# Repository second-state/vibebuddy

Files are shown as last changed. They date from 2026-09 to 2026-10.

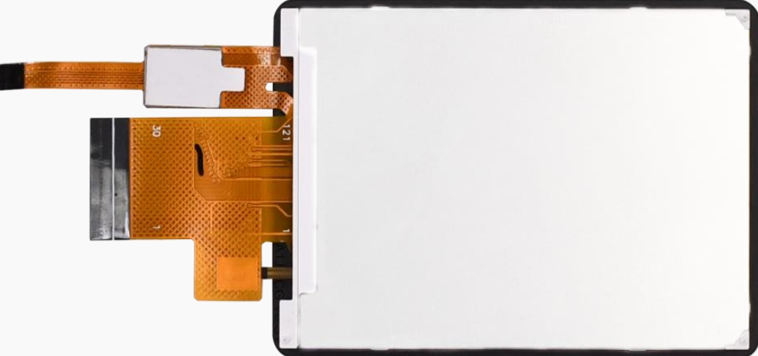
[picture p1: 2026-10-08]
docs/hardware-reference/atk-box3/n1.png

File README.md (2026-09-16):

Vibe Buddy (formerly VibeBuddy) is a physical status terminal for local AI agents and long-running tasks.

# Vibe Buddy

Vibe Buddy（原名 VibeBuddy，仓库、`vibebuddyd` 与 Vibe Buddy Protocol 沿用旧名）是运行在 ESP32-S3 盒子里的实体 Agent 宠物。原创角色“氛围小助手”用动画、任务卡片和短语音呈现本地 AI Agent 与长任务的状态；Codex 是第一个适配器，但设备协议不绑定某个客户端。

## 当前状态

**Stage 4 — 氛围小助手显示与语音已通过实机验收，Codex、Claude Code 与 GitHub Actions 均已接入。** 它们的事件都经 `vibebuddyd` 和 USB Serial/JTAG 到达盒子，并共享同一个任务卡栈。氛围小助手支持空闲、工作中、需要确认、完成、失败和失联；最多显示 3 张任务卡，最新在最上，每张卡显示它在当前状态里待了多久；需要确认、完成和失败各播报一次短语音，工作中保持安静；空闲时轮播当日战绩并偶尔做个小动作。

氛围小助手有三个模式。**值班**是默认：盯着 Agent，有事叫你。**番茄钟**给你计时（专注 25 分钟、休息 5 分钟）：K0 开始、暂停、继续，长按放弃；K1 在值班与番茄钟之间切换；K2 照旧打开来源，长按静音；阶段结束响铃并播报，下一阶段等你按 K0 再开始；今天完成了几次、专注了多久记在面板上，按日清零，重启不丢。**休闲**是值班空闲够久之后它自己去玩：五分钟后开始演小剧目（巡逻、踢球、看书、数星星、躲猫猫、被自己吓醒、梦话），半小时后困了转暗睡觉，夜里睡够 90 分钟关背光；Agent 一有动静或按任何键立刻回来值班。番茄钟与休闲的状态都在固件里，不依赖 Mac 端。设计见 [`docs/pomodoro.md`](docs/pomodoro.md) 与 [`docs/leisure.md`](docs/leisure.md)。

## 目标架构

```text
Local Programs / Agents / Codex / Scripts
                |
                | HTTP / Unix Socket
                v
             vibebuddyd
                |
                | Transport abstraction
                v
          USB Serial / USB CDC
                |
                v
           ESP32S3-BOX
                |
      LCD / Speaker / Buttons
```

- `vibebuddyd`：本机守护进程，负责事件接入、设备连接、重连、路由和状态。
- `beacon`：只调用 `vibebuddyd` 的命令行客户端，不直接占用串口。
- `vibebuddy-fw`：ESP32-S3 固件，仅负责设备 I/O 和 Vibe Buddy Protocol 消息处理。
- Vibe Buddy Protocol：与 transport 解耦的可扩展 NDJSON 协议。

更完整的边界与决定见 [`docs/architecture.md`](docs/architecture.md)，领域词汇见 [`CONTEXT.md`](CONTEXT.md)，氛围小助手设计见 [`docs/pet.md`](docs/pet.md)，番茄钟见 [`docs/pomodoro.md`](docs/pomodoro.md)，休闲模式见 [`docs/leisure.md`](docs/leisure.md)，Codex 接入见 [`docs/codex-adapter.md`](docs/codex-adapter.md)，CI 接入见 [`docs/ci.md`](docs/ci.md)，协议决定见 [`docs/protocol.md`](docs/protocol.md)，阶段门禁见 [`docs/roadmap.md`](docs/roadmap.md)，外部项目的借鉴边界见 [`docs/references.md`](docs/references.md)。

## Stage 0 USB 探测

在开发板未连接和已连接两种状态下分别运行：

```bash
./tools/detect-device.sh baseline
./tools/detect-device.sh connected
diff -ru .probe/baseline .probe/connected
```

探测结果可能包含本机 USB 设备标识。`.probe/` 默认不纳入 Git。

## Stage 1 固件

连接 ATK-DNESP32S3-BOX V1.1 的 `USB-SLAVE` 口后执行：

```bash
./tools/flash.sh /dev/cu.usbmodem8401
uv run --with pyserial python tools/serial-hello.py /dev/cu.usbmodem8401
```

烧录前可以在 Mac 上先验证固件里不依赖硬件的部分：`./tools/test-pomodoro.sh` 跑番茄钟状态机的测试，`./tools/preview-display.sh` 把固件的绘制代码渲染成 PNG 看版式。

固件使用 [`firmware/partitions.csv`](firmware/partitions.csv) 的自定义分区表（app 分区 4 MB），因为语音资产已经装不进默认的 1 MB。这个选择写在 `sdkconfig.defaults` 里，但 ESP-IDF 只在生成 `sdkconfig` 时读取 defaults：2026-09-15 之前就存在 `firmware/sdkconfig` 的检出目录要先删掉它再构建，否则仍按旧分区表检查大小并失败。

设备若只接着 BOX 的 `UART` 口（CH343 桥，`/dev/cu.usbmodem5909…`），不要用 `flash.sh`：那条路在 esptool 默认参数下会把 flash 擦掉后写不进去。用 [`tools/flash-bridge.sh`](tools/flash-bridge.sh)，它以 `--no-stub` 加 256 字节写块烧录，先单独写分区表试路，再写 app：

```bash
launchctl bootout gui/$(id -u)/com.vibebuddy.vibebuddyd
./tools/flash-bridge.sh /dev/cu.usbmodem59090668961 partition
./tools/flash-bridge.sh /dev/cu.usbmodem59090668961 app
launchctl bootstrap gui/$(id -u) ~/Library/LaunchAgents/com.vibebuddy.vibebuddyd.plist
```

`flash.sh` 会覆盖当前固件。2026-09-14 的原厂 `xiaozhi` 1.9.4 整片备份保存在本机 `.probe/factory/`，权限为 `600`，不会提交到 Git。

## Vibe Buddy App

Mac 端的图形界面是一个菜单栏 App，它把 `vibebuddyd` 与 `vibebuddy-hook` 带在身上并看管 daemon，取代了 LaunchAgent。装包：

```bash
idf.py -C firmware build          # Release 装包要附带固件三件套；--debug 可以不带
app/scripts/build-app.sh          # 出 app/build/Vibe Buddy.app
open "app/build/Vibe Buddy.app"
```

首次启动走引导：找盒子（眨眼确认）、接入 Codex 与 Claude Code（写 Hook 配置前展示差异）、挑播报音色写进盒子、登录时启动。之后菜单栏图标回答"盒子在线吗、什么模式、今天干了多少"，设置窗五页管通用、声音、接入、设备（固件更新、截图）、高级。发现旧的 LaunchAgent 会提议卸掉并接管。设计见 [`docs/app.md`](docs/app.md)。

App 用 SwiftPM 构建，只需要命令行工具；`swift run --package-path app SelfTest` 跑视图模型的自检。

## Stage 2 daemon

启动 `vibebuddyd`：

```bash
cargo run -p vibebuddyd
```

默认只监听 `127.0.0.1:7331`，并按 Espressif USB Serial/JTAG 的 `VID:PID 303A:1001` 自动发现设备。发送事件：

```bash
curl -H 'content-type: application/json' \
  --data '{"version":1,"event":"task.done","title":"Hello"}' \
  http://127.0.0.1:7331/v1/events
```

可用 `VIBEBUDDY_BIND` 修改监听地址、`VIBEBUDDY_SERIAL_PORT` 显式指定串口，或用 `VIBEBUDDY_USB_SERIAL` 在多块相同设备中选择目标。HTTP `202 Accepted` 表示事件进入有界发送队列；设备实际接收结果以 daemon 记录的设备响应为准。

daemon 由 Vibe Buddy App 看管（见上）。没有 App 的开发机可以用 [`packaging/com.vibebuddy.vibebuddyd.plist`](packaging/com.vibebuddy.vibebuddyd.plist) 装成 LaunchAgent，但两者不能同时跑，会抢串口。App 还提供 `GET /v1/status`、SSE `/v1/status/stream`、`/v1/config`、`/v1/device/{identify,screenshot,voice-pack,firmware}` 与 `/v1/daemon/restart`。

经 BOX 的 CH343 UART 桥发送时 daemon 按线速分段写：这条桥一次吞不下超过两百字节的连续数据，会把内容错位而长度不变；原生 USB 口不受影响。教训见 [`LESSONS.md`](LESSONS.md)。

## Agent 接入

Codex 与 Claude Code 都由本机 Hook 接入，各有一个隐私过滤脚本，两者写入同一个聚合器。任务卡标题带 Agent 前缀：Codex 为 `CX:`，Claude Code 为 `CC:`。第一行写 Agent 自己给会话起的名字（Claude App 的会话标题、Codex 的线程名或分支），第二行写项目名；会话没有名字时第一行就是项目名。项目名取自 git 项目根，因此在子目录或 worktree 中工作时显示的仍是项目名。

Hook 是一个 Rust 二进制 [`hook/`](hook/)（`vibebuddy-hook codex` / `vibebuddy-hook claude`），App 把它复制到 `~/Library/Application Support/VibeBuddy/bin/` 并写进用户级配置；不依赖 python3，App 挪位置也不断（ADR-0005）。

- Codex：`~/.codex/hooks.json` 的六个事件，写入后要在 Codex 的 `/hooks` 页面审查、信任；详见 [`docs/codex-adapter.md`](docs/codex-adapter.md)。
- Claude Code：`~/.claude/settings.json` 的八个事件；详见 [`docs/claude-adapter.md`](docs/claude-adapter.md)。

它只抽取会话与回合标识、事件名和工作目录，不转发 prompt、助手回复、transcript 或工具结果；判断助手是否在等待回答的规则两个 Agent 共用。它的前身是两个 Python 脚本，已退役；配置还指着旧路径的机器，App 启动时会把自己写的条目换成新路径。

## CI 接入

GitHub Actions 不走 Hook，由 `vibebuddyd` 每 30 秒用 `gh run list` 主动轮询，沿用你已有的 GitHub 登录。**不需要配置**：关注哪些仓库由 Agent 最近一小时工作过的项目自动推导，`owner/repo` 从 `.git/config` 的 `origin` 远端读出。任务卡前缀为 `CI:`，详见 [`docs/ci.md`](docs/ci.md)。

## 仓库布局

```text
daemon/    # vibebuddyd；Stage 2 开始实现
cli/       # beacon；Stage 6 开始实现
protocol/  # Vibe Buddy Protocol 类型与编解码
firmware/  # vibebuddy-fw
docs/      # 架构、协议、硬件证据和路线图
tools/     # 探测与烧录辅助脚本
```

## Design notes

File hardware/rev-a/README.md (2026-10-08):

# Vibe Buddy Rev A 硬件工程

状态：九页原理图草稿（总页 + 八个电路子页），已有 `.kicad_pcb` 初步布局，尚未布线，不可下单。用 KiCad 打开 `vibe-buddy-rev-a.kicad_pro`，再双击 `vibe-buddy-rev-a.kicad_sch` 进入总图；`VB.kicad_sym` 是本工程的元件符号库。

## 当前实现与验证

- 主控、USB、电源、三个业务按键与复位、BOX3 裸屏接口、音频采集、音频电源和音频播放已建立元件与跨页连接，共 105 个实体元件、100 个网络。
- 主控暂选 ESP32-S3-WROOM-1-N16R8；音频采用 ES7210、ES8311、NS4150B，功放使用稳压 3V3，不能直接承受 USB VBUS 的全部允许电压范围。
- 2026-09-18，KiCad 10.0.6 ERC 检查为 **0 错误、0 警告**，报告见 `erc-draft.rpt`。这是默认规则下的连接检查，不代表供电设计、器件参数或生产审核通过。
- 九页均能导出 SVG/PDF，已检查主控、显示、音频播放页的渲染并修正标签遮挡和页框重叠；尚未完成全部页面逐项人工复核。
- 从 KiCad 导出的 XML 网表核对了九组关键网络：USB 重复触点、原生 USB D+/D-、LCD SPI、差分扬声器输出及复位。已运行 PCB DRC，尚有未连接、工艺及丝印问题，不能放行。
- `circuit.py` 和 `build_schematic.py` 是生成源；重新运行会覆盖本目录原理图。若在 KiCad 内修改，须先保留修改并同步生成源，不能直接重新生成。

## 本轮电源审核与 PCB 布局

- 新增 TPS22918 受控上电，选择具体电感及布局封装；电源预算发现普通500mA端口不足以保证Wi-Fi/声音/亮屏峰值同时运行，待完成供电管理。
- 已生成四层90×80mm工程布局，105个电路元件和4个安装孔，所有原理图脚号在PCB上有对应焊盘；0条走线。板形为工程审查占位，不是最终产品尺寸。
- 完整审核、封装依据和未解决项见 [电源与封装审核](power-footprint-review.md)。DRC报告见 `drc-layout.rpt`：当前4项USB定位孔间距错误、2项天线区丝印越界警告，以及264项未连接。没有忽略这些报错或导出生产包。
- `build_layout.py`读取KiCad导出的`layout-input.xml`生成PCB，重新运行会覆盖布局；手动编辑前应保留副本。可双击 `vibe-buddy-rev-a.kicad_pcb` 查看。

## 已确定范围

ESP32-S3 模组、Wi-Fi、2.4 英寸屏幕、单模拟麦克风、ES7210 采集、ES8311 播放、NS4150B 功放、单扬声器。对外仅一个 USB-C、三个业务按键和一个复位键，无 TF 卡及扩展插座。暂按 USB 供电、无电池设计；暂不接模型。

完整设计输入见 [PCB 设计输入](../../docs/pcb-rev-a.md)。既有 BOX 和面包板固件继续保留，不能直接以其引脚分配代替本板设计。

## 原理图分块

| 模块 | 连接与责任 | 完成前需核对 |
| --- | --- | --- |
| 电源与 USB | 单 USB-C 供电、原生 USB 数据、CC 电阻、保护、稳压和去耦 | USB 可用电流、总功耗、峰值负载、连接器封装与保护参数 |
| 主控 | ESP32-S3 模组、启动配置、复位、板内下载测试点 | 完整模组料号、焊盘、天线净空、启动和 USB 引脚 |
| 显示 | BOX 规格的 2.4 英寸显示屏及背光驱动 | 裸屏/模块选择、接口、连接器与引脚方向、背光电流 |
| 操作 | 三个业务键和独立复位键 | GPIO 分配、按键封装、机械位置和故障恢复流程 |
| 音频采集 | 模拟麦克风到 ES7210；ES8311 播放参考到另一采集通道 | 麦克风偏置、耦合、输入幅度、采样通道与时钟 |
| 音频播放 | ESP32-S3 到 ES8311，再到 NS4150B 和扬声器 | 功放电源、增益、控制脚、扬声器阻抗与功率 |

音频依据见 [官方 BOX3 原理图调查](../../docs/box-audio-research.md)。硬件参考输入不等于回声消除软件已经实现。

## 工程推进顺序

1. 配置 KiCad 及官方符号/封装库，确定工程版本。
2. 落实完整采购料号与原厂规格书；自建封装须逐项核对焊盘尺寸、编号和方向。
3. 绘制原理图并做电源预算、引脚审查与 ERC；未定项不得用猜测的封装填充。
4. 结合屏幕和外壳装配确定板框；暂以四层板为设计方向，进入布局布线后复核。
5. 完成 DRC、机械核对、人工电路复核和可制造性检查后导出生产包。
6. 少量样机验收通过后再考虑 20～50 台试卖。

PCB 设计与工厂文件检查均不能代替实机功能验证。

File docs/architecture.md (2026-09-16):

# Vibe Buddy 架构

## 目标与边界

Vibe Buddy 把本地程序的状态事件变成实体宠物的画面与声音。ESP32 只负责确定性渲染、播报和设备 I/O；任务聚合、优先级与客户端适配由 Mac 端负责。

## 组件

### `vibebuddyd`

- 通过 `POST /v1/events` 接收通用事件，通过 `POST /v1/codex-hooks` 和 `POST /v1/claude-hooks` 接收经过最小化的 Agent 生命周期事件。
- 校验并编码 Vibe Buddy Protocol 消息。
- 管理设备发现、串口连接、断线重连和设备状态。
- 把设备上报的按钮事件路由回本机消费者。
- 聚合所有 Agent 的会话，生成最多 3 张“最新在最上”的任务卡；需要用户确认的活动优先控制宠物全局状态。
- 定时清除长时间没有事件的活动，避免异常退出的会话永久占用任务卡。

### `beacon`

- 作为 `vibebuddyd` 的客户端提供命令行接口。
- 不发现、打开或独占物理串口。
- 在 Stage 6 实现；Stage 2 先用 HTTP 请求验收完整链路。

### `vibebuddy-fw`

- 接收并解析 Vibe Buddy Protocol 消息。
- 驱动 LCD 和扬声器；氛围小助手动画完全在盒子上运行，不依赖 Mac 端逐帧传图。
- 不解释任务生命周期之外的本机业务语义。

### `app`（设计已定，待实现）

- 菜单栏 App，看管 `vibebuddyd`（作为 helper 随 App 分发、启动、重启、退出），取代 LaunchAgent。
- 首次引导、接入 Agent（写 Hook 配置）、挑选播报音色并写入设备、更新固件、看设备画面。
- 只在链路异常时自己出声（macOS 通知）；Agent 的事仍由设备讲。设计见 [`app.md`](app.md)。

### `protocol`

- 定义 Vibe Buddy Protocol 的消息模型、编解码、版本和限制。
- 与 USB UART、USB CDC、WebSocket、TCP 或 Bluetooth 等 transport 无关。

## 数据流

```text
Codex Hook -------> privacy filter -> POST /v1/codex-hooks ---+
Claude Code Hook -> privacy filter -> POST /v1/claude-hooks --+
Other producer ------------------> POST /v1/events -----------+-> vibebuddyd -> USB -> ESP32-S3
Codex / Claude / Browser <---------- open source <------------+<- vibebuddyd <- K2
```

首版只实现 `SerialTransport`。Transport 接口只抽象连接、发送、接收和关闭所需的最小能力；在第二个真实 transport 出现前不设计复杂插件系统。

## 关键决定

1. 第一阶段采用 monorepo，Mac 端优先 Rust，固件优先评估 ESP-IDF。
2. CLI 必须经由 daemon，避免多个进程竞争串口并分散重连逻辑。
3. Vibe Buddy Protocol v1 使用 NDJSON，一行一个 JSON object。
4. 固件硬件配置必须来自精确板型的官方资料或实机验证，不借用相似板卡 GPIO。
5. 编译、模拟链路和实机验收是三种不同证据；只有实机链路满足对应阶段门禁。
6. Stage 2 的 `SerialTransport` 使用 64 条有界队列；HTTP `202 Accepted` 只表示事件已入队，不谎称设备已经处理。串口写入失败时保留当前帧，重新按 `303A:1001` 发现设备并重试。
7. 不抓取 Codex UI，也不解析不稳定的 transcript。V1 只使用官方 Hook；适配脚本在进程边界前丢弃 prompt、transcript 与工具内容。任务卡的会话名来自两个 App 自己存在本机的记录（Claude App 会话索引的 `title`、Codex `state_5.sqlite` 里 `threads` 的 `name` 与 `git_branch`），它们是 App 侧栏里本来就显示的名字，不是 prompt；Codex 的 `title` 列是原始首条消息，不读。查询有缓存，Hook 每几秒来一次，不能每次都扫目录、开数据库。
8. 多任务卡按最近活动排序，最多 3 张；全局表情的优先级是“需要确认 > 工作中”。动画和语音资产留在固件中，Mac 只发送状态快照。
9. Hook 生命周期不保证收尾事件，活动必须能自行过期。工作中按 30 分钟、需要确认按 4 小时计时；两档时限不同，因为前者无事件通常意味着进程已经消失，后者只意味着用户尚未回来。清理由 60 秒一次的后台扫描驱动，不能只在收到新 Hook 时惰性触发。
10. 每个 Agent 一个 Adapter，但所有 Adapter 写入同一个聚合器。设备只有一块屏幕和一只氛围小助手，两个聚合器会各自维护任务卡栈并互相覆盖。Adapter 因此不持有状态，只做事件翻译和活动身份合成；任务卡标题带 Agent 前缀，因为两个 Agent 常在同一目录下工作。
11. CI 与 Agent 共用同一套任务卡和播报，只是来源不同：GitHub Actions 由 `vibebuddyd` 主动轮询，不靠 Hook。只有亲眼见过某次 run 在跑，它结束时才播报；否则每次重启 daemon 都会把仓库里最近一次历史结果重新宣告一遍。关注哪些仓库不需要用户配置：Hook 已经带来了 `cwd`，Agent 最近工作过的项目就是该关心 CI 的那些，仓库名从本地 `.git/config` 推导。
12. K2 打开的来源必须与屏幕主状态使用同一套优先级，不能另做一个“最近窗口”列表。聚合器只保存定位所需的 thread id、session id 或 repo/run id，不保存 prompt 与回复；外部参数不经过 shell。Codex 子 Agent 的生命周期 session 不是桌面可导航 thread，Hook 必须把它映射到父 thread 后再关联来源；Claude Code 的 CLI `session_id` 不足以定位窗口——同一个 id 会对应多个桌面会话——必须连同 `cwd` 在 Claude App 的会话索引里解析成桌面会话 id 后再跳转。
13. 番茄钟、休闲与模式切换都在固件里，`vibebuddyd` 只收诊断行。它是设备 I/O 与确定性渲染，本来就是固件的职责；更要紧的是用户拿它计时时 Mac 端可能没在跑，一个要靠心跳才走的计时器没有用。固件里凡是不碰硬件的逻辑——番茄钟状态机、休闲导演、绘制代码——都要能在 Mac 上直接编译：状态机与导演有主机测试，画面与剧目有主机预览，烧录之前就能看见版式和动画。
14. Mac 端的图形界面是原生 SwiftUI 菜单栏 App，`vibebuddyd` 作为 helper 由它看管；语音包放独立分区、走串口协议写入；Hook 改为 Rust 单二进制复制到 Application Support。三条取舍分别见 ADR-0004、0003、0005，整体设计见 [`app.md`](app.md)。

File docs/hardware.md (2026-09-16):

# Vibe Buddy 硬件记录

本文只记录带证据边界的硬件事实。相似名称或同系列开发板不能作为 GPIO、codec、LCD 或 USB 路径的依据。

## 用户提供，尚未由实物或原理图验证

- 名称：正点原子 ESP32S3-BOX。
- 模组：ATK-MWS3S / ESP32-S3。
- 资源：16 MB Flash、8 MB PSRAM。
- 外设：LCD、Speaker、Microphone、Buzzer、K0/K1/K2、TF/microSD、USB-C、USB-A Host、UART。
- 期望：一根 USB-C 线同时供电、烧录和运行时通信。

同一根 USB-C 线完成供电、运行时串口、ROM 下载、Vibe Buddy 固件写入和写入后的重新枚举已经实测成立。

## 当前主机确认

- 主机名：`Michaels-Mac-Studio.local`。
- 型号：Mac Studio，Model Identifier `Mac14,14`，Apple M2 Ultra。
- 证据：2026-09-13 在本机执行 `hostname` 和 `system_profiler SPHardwareDataType`。

## 官方资料确认

详细来源与候选板差异见 [`hardware-research.md`](hardware-research.md)。当前能够确认的是：

- `ATK-MWS3S` 是模组标识，不足以识别底板；正点原子的 DNESP32S3 开发板和老款 ESP32S3 BOX 都可能使用该模组。
- 官方 `ATK-DNESP32S3-Board` 仓库对应 DNESP32S3 开发板，不是 BOX 的通用 BSP。它公开的是 `ATK_DNESP32S3 V1.2` 原理图、KEY0～KEY3 + BOOT、ES8388、XL9555、CH340C 和原生 USB Serial/JTAG 两条烧录路径。
- 当前官方 Wiki 完整覆盖的是 `ATK-DNESP32S3B3 V1`（BOX3）：K0 直连 GPIO0，K1/K2 经过 AW9523B，屏幕为 320×240 ST7789V2，触摸为 CHSC5432，音频链路包含 ES8311、ES7210 与 NS4150B，并公开原生 USB/TinyUSB 资料。
- 用户给出的硬件组合与上述任一候选都不完全闭合。老款 BOX 的官方资料入口当前无法读取，不能拿 BOX3 或 DNESP32S3 开发板引脚补齐。

因此，在 PCB 丝印确认前不选择 BSP、不冻结 GPIO。ESP-IDF v5.5.3 已根据实机当前固件的 v5.5 构建信息和对应上游源码要求安装；该选择不代表已经接受某个候选板的 GPIO 定义。

## 实机确认

- 用户确认开发板尚未连接后，已于 2026-09-13 保存 Mac Studio 的未连接 USB 基线；基线未出现 ESP32、常见 USB-UART bridge 或新增 USB modem 串口。
- 2026-09-14 连接开发板后，新增 Espressif `USB JTAG/serial debug unit`，VID:PID `303A:1001`，USB serial `98:88:E0:06:8B:CC`。
- 新增节点为 `/dev/cu.usbmodem8401` 与 `/dev/tty.usbmodem8401`，证明目标板当前通过 ESP32-S3 原生 USB Serial/JTAG 枚举，而不是外置 CH340/CP210/FTDI bridge。
- 运行日志确认 ESP32-S3 revision v0.2、16 MB QIO Flash、8 MB Octal PSRAM，以及当前固件板型标识 `atk-dnesp32s3-box`。
- 只读 `esptool flash_id` 成功连接 ROM 下载通路并复核 16 MB Flash、8 MB embedded PSRAM 和 USB-Serial/JTAG mode；未擦除或写入 Flash。
- 打开原生 USB 串口会触发 `USB_UART_CHIP_RESET`，因此运行时重连设计必须容忍设备复位和重新枚举。
- 2026-09-14 的背面照片显示 PCB `V1.1` 丝印、ATK-MWS3S `N16R8` 模组、`B0/K1/K2`、`USB-SLAVE`、`HOST`、`UART`、麦克风、扬声器、蜂鸣器和 TF 卡座。
- 实物布局与当前固件自报标识共同确认板型为 **ATK-DNESP32S3-BOX V1.1**；不是 DNESP32S3 开发板、BOX0、BOX2 或 BOX3。
- Stage 2 真实拔掉 `USB-SLAVE` 后，`vibebuddyd` 记录到 `Device not configured`；插回后自动重新发现同一串口节点并恢复通信。
- 完整 USB 断电后，原小智固件遗留画面消失而屏幕保持黑色；这证明旧画面是 LCD 残留状态，不代表旧固件仍在运行，也不证明 Vibe Buddy 已有 LCD 驱动。
- LCD 已由 Vibe Buddy 实机驱动并通过视觉验收：320×240 ST7789、8 位 i80，总线数据 GPIO40/39/38/12/11/10/9/46，CS/DC/RD/WR 为 GPIO1/2/41/42，背光由 XL9555 P0.7 控制。
- I2C 在 7 位地址 `0x18` 探测到 ES8311；音频 I2S BCLK/WS/DOUT 为 GPIO21/13/14，采样率 24 kHz，扬声器使能由 XL9555 P0.5 控制。
- 固件启动已回报 `AUDIO READY` 与 `AUDIO CODEC ES8311`；用户已实际听到“需要你确认”语音。
- 2026-09-14 实机验证失联指示：停止 `vibebuddyd` 超过 15 秒后，设备转为闭眼、画面转灰并显示 `NO LINK`，任务卡保留但同样转灰；恢复 daemon 后自动退出该状态。用户已实机确认。
- 2026-09-14 提高播报响度：语音资产以统一增益归一化到约 90% 满量程（+5.5 dB，无削波），codec 输出音量由 45 调至 65。用户实机确认音量已足够。
- 2026-09-14 实机探针确认 K2 接在 XL9555 P0.3，低电平有效：松开时 `P0=0xFF`，按下时变为 `P0=0xF7`，随后恢复为 `0xFF`，期间 P1 保持 `0xFF`。写入正式固件后，用户短按 K2，设备能上报 K2 单击事件并由 Mac 端 `vibebuddyd` 拉起目标应用；Codex 子 Agent 到父会话的精确路由修复仍待最后一次实机确认。
- 2026-09-15 用户确认外壳上的按键为 K0、K1、K2 与 RST。PCB 丝印上的 `B0` 对应外壳的 K0：它是 ESP32-S3 的 BOOT 键，直连 GPIO0、低电平有效、内部上拉。依据是同板上游固件 `xiaozhi` 的 `atk-dnesp32s3-box/config.h` 定义 `BOOT_BUTTON_GPIO GPIO_NUM_0`；同日实机按压确认：按 K0 后设备回报 `POMODORO PAUSED` / `RESUMED`。运行时按 K0 不影响启动模式，只有复位瞬间按住才会进下载模式；`vibebuddyd` 打开串口会触发复位，那一瞬间恰好按着 K0 的概率可以忽略，但要知道有这回事。
- 2026-09-15 实机探针确认 K1 接在 XL9555 P0.4，低电平有效：按下时 `P0=0xEF`，松开恢复 `0xFF`，P1 始终 `0xFF`。探针的候选范围来自同板上游固件 `atk_dnesp32s3_box.cc` 的方向寄存器写法（`0x06=0x1B`、`0x07=0xFE`，即 P0.0、P0.1、P0.4 与 P1.1～P1.7 为输入），实机只有 P0.4 随 K1 变化。

## 当前运行固件旁证

实机运行 `xiaozhi` 1.9.4。固定版本源码中存在 `atk-dnesp32s3-box` board 目录，并记录了 ST7789 i80、XL9555、ES8311 和一组板级引脚。这与启动日志相互印证，可作为核对候选，但该仓库不是正点原子官方原理图/BSP，不能越过 PCB 版本门禁直接冻结引脚。

- [`xiaozhi-esp32` v1.9.4 固定提交](https://github.com/78/xiaozhi-esp32/tree/3ced7709c65a39494f5684e99111854a5bcbd8c7)
- [`atk-dnesp32s3-box/config.h`](https://github.com/78/xiaozhi-esp32/blob/3ced7709c65a39494f5684e99111854a5bcbd8c7/main/boards/atk-dnesp32s3-box/config.h)

## 待验证

- 与准确 PCB 版本匹配的厂家 schematic、BSP 和 examples。
- 触摸控制器（如有）。
- 麦克风输入链路。
- buzzer 的 GPIO 和有效电平。

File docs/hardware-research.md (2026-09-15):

# Vibe Buddy Stage 0：正点原子 ESP32-S3 硬件资料核对

> 调研日期：2026-09-13  
> 证据范围：正点原子官网、官方 Wiki、官方 GitHub，以及乐鑫官方文档/仓库。第三方项目仅列在“非官方实现参考”，不参与硬件事实确认。

## 结论先行

目前**不能仅凭“正点原子 ESP32S3-BOX / ATK-MWS3S”确认底板型号，也不能据此冻结 GPIO 或 BSP**。

- 正点原子官方把“ESP32S3 开发板”和“ESP32S3 BOX”列为两个产品，但二者都采用 ATK-MWS3S；所以 ATK-MWS3S 只能识别模组，不能唯一识别底板。[正点原子官方文章](https://www.cnblogs.com/zdyz/p/18715431)
- 正点原子目前有资料完整的 **ATK-DNESP32S3B3 V1（BOX3）**。它使用 K0/K1/K2、ST7789V2、CHSC5432、ES8311、ES7210 和 NS4150B；官方简介只列一个 USB Type-C OTG 口，未列蜂鸣器或 USB-A Host。[BOX3 官方简介](https://wiki.alientek.com/docs/Boards/IoT/DNESP32S3B3/start-guide/dnesp32s3-box3-introduction/)
- 正点原子官方 `ATK-DNESP32S3-Board` 仓库对应的是 **DNESP32S3 开发板**，不是已被证明等同于 BOX 的 BSP。该板有 KEY0～KEY3、BOOT、蜂鸣器、ES8388、CH340C USB 转串口和原生 USB 从机/JTAG。[官方仓库 README](https://github.com/openedv/ATK-DNESP32S3-Board/blob/c7434a3da5b9e6feda05added5d6a686f1c95f13/README.md)
- 用户描述中的“16 MB Flash、8 MB PSRAM、LCD、扬声器、麦克风、蜂鸣器、K0/K1/K2、TF、USB-C、USB-A Host、UART”与上述任一套已公开官方资料都不完全相符。尤其是“蜂鸣器 + 三按键 + USB-A Host”的组合尚无一手资料闭环。

因此 Stage 0 的硬件结论为：**型号门禁未通过**。在取得底板正反面清晰照片、PCB 丝印和接口标注之前，只能准备候选适配层，不能把任何候选板的 GPIO 当成实机事实。

## 型号歧义

### 三个不得混用的对象

| 对象 | 官方身份 | 与当前描述的关系 | 证据边界 |
|---|---|---|---|
| 正点原子 DNESP32S3 开发板 | `ATK-DNESP32S3-Board`；ATK-MWS3S，16 MB Flash、8 MB PSRAM | 有蜂鸣器、ES8388、MIC、扬声器、TF、USB 转串口和 USB 从机/JTAG；按键却是 KEY0～KEY3 + BOOT | 只能作为 DNESP32S3 开发板候选资料，不能直接套给 BOX。[官方 README](https://github.com/openedv/ATK-DNESP32S3-Board/blob/c7434a3da5b9e6feda05added5d6a686f1c95f13/README.md) |
| 正点原子 BOX3 | `ATK-DNESP32S3B3 V1`；ESP32S3-R8，16 MB Flash | 有 K0/K1/K2、2.4 英寸触摸屏、MIC、扬声器、TF 和 USB-C；官方简介未列蜂鸣器、USB-A Host，也未把板卡称作 ATK-MWS3S | 只有实机确认为 `ATK-DNESP32S3B3 V1` 后，才能采用本页 BOX3 引脚。[官方简介](https://wiki.alientek.com/docs/Boards/IoT/DNESP32S3B3/start-guide/dnesp32s3-box3-introduction/) |
| 乐鑫 ESP32-S3-BOX / BOX-3 | 乐鑫自有产品线 | 名字相近，但不是正点原子板卡 | 乐鑫 BSP 只服务其自有 ESP-BOX 系列，不能作为正点原子 GPIO/BSP 依据。[乐鑫 esp-box](https://github.com/espressif/esp-box) · [乐鑫 esp-bsp 的 ESP-BOX-3](https://github.com/espressif/esp-bsp/blob/master/bsp/esp-box-3/README.md) |

正点原子官方 2025 年文章确实给老款“ESP32S3 BOX”单列了资料入口：`ATK-DNESP32S3BVXX.html`，也给 DNESP32S3 开发板单列了 `ATK-DNESP32S3.html`；这进一步证明两者不能互换。[官方文章](https://www.cnblogs.com/zdyz/p/18715431) 截至本次调研，文章内老资料入口已无法正常取得内容，因此**老款 BOX 的精确版本号、原理图与 BSP 仍未确认**。

### 当前最小可信判断

1. 若 PCB 丝印为 `ATK-DNESP32S3B3 V1`，按 BOX3 资料实现。
2. 若 PCB 丝印为 `ATK-DNESP32S3` 并与官方开发板原理图一致，按 DNESP32S3 开发板资料实现。
3. 若丝印包含 `ATK-DNESP32S3B`、`BOX` 或其他版本号，但不是 `B3 V1`，必须继续寻找该精确版本的官方资料包；不能拿 BOX3 或 DNESP32S3 的引脚表补空白。

## 官方确认：DNESP32S3 开发板候选

以下只对正点原子 `ATK-DNESP32S3-Board` 官方仓库所对应的开发板成立。引用固定在官方仓库提交 `c7434a3da5b9e6feda05added5d6a686f1c95f13`，避免后续分支变化改变证据。

### BSP、原理图与例程

- 官方仓库包含原理图、ESP-IDF/Arduino/MicroPython 例程、固件和工具。[仓库 README](https://github.com/openedv/ATK-DNESP32S3-Board/blob/c7434a3da5b9e6feda05added5d6a686f1c95f13/README.md)
- 官方原理图版本为 `ATK_DNESP32S3 V1.2`。[原理图 PDF](https://github.com/openedv/ATK-DNESP32S3-Board/blob/c7434a3da5b9e6feda05added5d6a686f1c95f13/1_docs/1_sch/ATK_DNESP32S3%20V1.2.pdf)
- 仓库不是乐鑫 `esp-bsp` 中的一个集中式板级包；其 ESP-IDF 例程把厂商驱动放在各例程的 `components/BSP` 下。可以抽取为 Vibe Buddy 的板级适配层，但需要自行确定版本、依赖和测试边界。[I2C 扩展例程 BSP 目录](https://github.com/openedv/ATK-DNESP32S3-Board/tree/c7434a3da5b9e6feda05added5d6a686f1c95f13/2_examples/1_ESP_IDF/1_basic_routines/09_iic_exio/components/BSP)

### 按键与蜂鸣器

这块板的 KEY0～KEY3 和蜂鸣器不是直接连接 ESP32-S3 GPIO，而是连接 XL9555 I/O 扩展器；XL9555 使用 ESP32-S3 GPIO41（SDA）和 GPIO42（SCL）。[官方原理图](https://github.com/openedv/ATK-DNESP32S3-Board/blob/c7434a3da5b9e6feda05added5d6a686f1c95f13/1_docs/1_sch/ATK_DNESP32S3%20V1.2.pdf)

| 功能 | XL9555 位 | 电气/软件语义 | 官方依据 |
|---|---:|---|---|
| 蜂鸣器 | P0_3 / `0x0008` | 例程写 0 开、写 1 关，即低有效 | [定义](https://github.com/openedv/ATK-DNESP32S3-Board/blob/c7434a3da5b9e6feda05added5d6a686f1c95f13/2_examples/1_ESP_IDF/1_basic_routines/09_iic_exio/components/BSP/XL9555/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) · [例程](https://github.com/openedv/ATK-DNESP32S3-Board/blob/c7434a3da5b9e6feda05added5d6a686f1c95f13/2_examples/1_ESP_IDF/1_basic_routines/09_iic_exio/main/main.c) |
| KEY3 | P1_4 / `0x1000` | 低电平按下 | [定义与扫描实现](https://github.com/openedv/ATK-DNESP32S3-Board/blob/c7434a3da5b9e6feda05added5d6a686f1c95f13/2_examples/1_ESP_IDF/1_basic_routines/09_iic_exio/components/BSP/XL9555/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) |
| KEY2 | P1_5 / `0x2000` | 低电平按下 | [定义与扫描实现](https://github.com/openedv/ATK-DNESP32S3-Board/blob/c7434a3da5b9e6feda05added5d6a686f1c95f13/2_examples/1_ESP_IDF/1_basic_routines/09_iic_exio/components/BSP/XL9555/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) |
| KEY1 | P1_6 / `0x4000` | 低电平按下 | [定义与扫描实现](https://github.com/openedv/ATK-DNESP32S3-Board/blob/c7434a3da5b9e6feda05added5d6a686f1c95f13/2_examples/1_ESP_IDF/1_basic_routines/09_iic_exio/components/BSP/XL9555/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) |
| KEY0 | P1_7 / `0x8000` | 低电平按下 | [定义与扫描实现](https://github.com/openedv/ATK-DNESP32S3-Board/blob/c7434a3da5b9e6feda05added5d6a686f1c95f13/2_examples/1_ESP_IDF/1_basic_routines/09_iic_exio/components/BSP/XL9555/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) |

注意：这套官方定义没有 K0/K1/K2 命名，而是 KEY0～KEY3。若实机外壳印的是 K0/K1/K2，不能只按按键序号做映射。

### 音频

- 音频编解码器为 ES8388，板载 MIC、扬声器、耳机接口，扬声器使能通过 XL9555 的 P0_2 控制。[官方 README](https://github.com/openedv/ATK-DNESP32S3-Board/blob/c7434a3da5b9e6feda05added5d6a686f1c95f13/README.md) · [XL9555 定义](https://github.com/openedv/ATK-DNESP32S3-Board/blob/c7434a3da5b9e6feda05added5d6a686f1c95f13/2_examples/1_ESP_IDF/1_basic_routines/30_music/components/BSP/XL9555/xl9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)
- 官方音乐例程的 I2S 引脚为 MCLK=GPIO3、BCLK=GPIO46、WS/LRCK=GPIO9、ESP→codec 数据=GPIO10、codec→ESP 数据=GPIO14。[官方 I2S 头文件](https://github.com/openedv/ATK-DNESP32S3-Board/blob/c7434a3da5b9e6feda05added5d6a686f1c95f13/2_examples/1_ESP_IDF/1_basic_routines/30_music/components/BSP/I2S/i2s.h)
- ES8388 通过 I2C 配置；驱动接口同时覆盖 DAC 与 ADC 路径。[官方 ES8388 头文件](https://github.com/openedv/ATK-DNESP32S3-Board/blob/c7434a3da5b9e6feda05added5d6a686f1c95f13/2_examples/1_ESP_IDF/1_basic_routines/30_music/components/BSP/ES8388/es8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)

### LCD 与触摸

- 官方 SPI LCD 例程支持 240×240 与 320×240 两种面板配置，例程默认方向尺寸为 320×240；LCD CS=GPIO21，DC 由跳帽选择到 GPIO40，SPI MOSI/SCLK/MISO 分别为 GPIO11/GPIO12/GPIO13。[LCD 头文件](https://github.com/openedv/ATK-DNESP32S3-Board/blob/c7434a3da5b9e6feda05added5d6a686f1c95f13/2_examples/1_ESP_IDF/1_basic_routines/12_spilcd/components/BSP/LCD/lcd.h) · [LCD 实现](https://github.com/openedv/ATK-DNESP32S3-Board/blob/c7434a3da5b9e6feda05added5d6a686f1c95f13/2_examples/1_ESP_IDF/1_basic_routines/12_spilcd/components/BSP/LCD/lcd.c)
- 仓库包含 ST7789VW 数据手册，但通用驱动同时支持不同尺寸，因此**仅凭仓库不能确认用户 BOX 的 LCD 控制器或分辨率**。[官方资料目录](https://github.com/openedv/ATK-DNESP32S3-Board/tree/c7434a3da5b9e6feda05added5d6a686f1c95f13/1_docs/2_chip_manual)
- 官方 `touch` 例程使用 GT9xxx，并配合 RGBLCD；触摸 I2C 为 GPIO39/GPIO38，INT 为 GPIO40。它证明开发板生态中存在该触摸方案，但不能证明用户 BOX 的 2.4 英寸屏使用 GT9xxx。[GT9xxx 官方头文件](https://github.com/openedv/ATK-DNESP32S3-Board/blob/c7434a3da5b9e6feda05added5d6a686f1c95f13/2_examples/1_ESP_IDF/1_basic_routines/24_touch/components/BSP/TOUCH/gt9x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)

### USB、烧录与运行链路

- 原理图把 ESP32-S3 原生 USB 的 D- / D+ 分别接到 GPIO19 / GPIO20；UART0 TX/RX 分别是 GPIO43/GPIO44。[官方原理图](https://github.com/openedv/ATK-DNESP32S3-Board/blob/c7434a3da5b9e6feda05added5d6a686f1c95f13/1_docs/1_sch/ATK_DNESP32S3%20V1.2.pdf)
- 该开发板提供两条烧录路径：CH340C USB 转串口，以及 ESP32-S3 原生 USB Serial/JTAG。[官方 README](https://github.com/openedv/ATK-DNESP32S3-Board/blob/c7434a3da5b9e6feda05added5d6a686f1c95f13/README.md) · [官方 USB-UART 例程说明](https://github.com/openedv/ATK-DNESP32S3-Board/blob/c7434a3da5b9e6feda05added5d6a686f1c95f13/2_examples/1_ESP_IDF/1_basic_routines/33_usb_uart/README.md)
- 官方 USB-UART 例程使用 TinyUSB CDC ACM，可让应用运行时通过原生 USB 提供虚拟串口。[官方实现](https://github.com/openedv/ATK-DNESP32S3-Board/blob/c7434a3da5b9e6feda05added5d6a686f1c95f13/2_examples/1_ESP_IDF/1_basic_routines/33_usb_uart/main/APP/tud_usart.c)

这里必须区分三件事：CH340C 外置 UART、芯片固定功能的 USB Serial/JTAG、应用自己启动的 TinyUSB CDC。它们都可能表现为“串口”，但枚举身份、驱动、固件生命周期和故障恢复方式不同。

## 官方确认：BOX3 候选

以下仅在实机丝印确认为 `ATK-DNESP32S3B3 V1` 时成立。引用固定在官方 Wiki 源仓提交 `c6f9797b64aef2666547206b4b274017d6d28a3d`。

### 板卡组成

- 主控为 ESP32S3-R8，外接 16 MB Flash；板卡输入为 5V USB。[官方简介源文件](https://github.com/openedv/openedv-wiki-boards-dnesp32s3b3/blob/c6f9797b64aef2666547206b4b274017d6d28a3d/start-guide/dnesp32s3-box3-introduction.md)
- 屏幕为 2.4 英寸 320×240、4 线 SPI、ST7789V2；LCD CS=GPIO47、DC=GPIO48，SPI SCLK/MOSI/MISO=GPIO15/GPIO16/GPIO17。[LCD 官方说明](https://github.com/openedv/openedv-wiki-boards-dnesp32s3b3/blob/c6f9797b64aef2666547206b4b274017d6d28a3d/example-idf/lcd.md)
- 触摸控制器为 CHSC5432，I2C 7 位地址 `0x2E`。[触摸官方说明](https://github.com/openedv/openedv-wiki-boards-dnesp32s3b3/blob/c6f9797b64aef2666547206b4b274017d6d28a3d/example-idf/touch.md)
- 音频输出使用 ES8311，采集使用 ES7210，输入为模拟麦克风，功放为 NS4150B。[官方简介源文件](https://github.com/openedv/openedv-wiki-boards-dnesp32s3b3/blob/c6f9797b64aef2666547206b4b274017d6d28a3d/start-guide/dnesp32s3-box3-introduction.md)
- 音频 I2S 为 BCLK=GPIO38、WS=GPIO39、数据输出=GPIO40、数据输入=GPIO41、MCLK=GPIO21。[音乐官方说明](https://github.com/openedv/openedv-wiki-boards-dnesp32s3b3/blob/c6f9797b64aef2666547206b4b274017d6d28a3d/example-idf/music.md)

### K0/K1/K2

| 按键 | 连接 | 备注 | 官方依据 |
|---|---|---|---|
| K0 | ESP32-S3 GPIO0 | 低电平有效 | [按键例程](https://wiki.alientek.com/docs/Boards/IoT/DNESP32S3B3/example-idf/key/) |
| K1 | AW9523B P0_0 | 通过 I/O 扩展器读取 | [音乐例程源文件](https://github.com/openedv/openedv-wiki-boards-dnesp32s3b3/blob/c6f9797b64aef2666547206b4b274017d6d28a3d/example-idf/music.md) |
| K2 | AW9523B P0_1 | 通过 I/O 扩展器读取 | [音乐例程源文件](https://github.com/openedv/openedv-wiki-boards-dnesp32s3b3/blob/c6f9797b64aef2666547206b4b274017d6d28a3d/example-idf/music.md) |

BOX3 官方简介的功能列表和板载资源表均未列蜂鸣器。因此若实机确认有蜂鸣器，不能用 BOX3 文档猜测其引脚。[官方简介](https://wiki.alientek.com/docs/Boards/IoT/DNESP32S3B3/start-guide/dnesp32s3-box3-introduction/)

### USB、烧录与运行链路

- BOX3 有一个 USB Type-C OTG 接口，默认 Device 模式，用于供电、USB 通信及连接 VS Code；官方简介未列第二个 USB-A Host 口。[官方简介源文件](https://github.com/openedv/openedv-wiki-boards-dnesp32s3b3/blob/c6f9797b64aef2666547206b4b274017d6d28a3d/start-guide/dnesp32s3-box3-introduction.md)
- 官方 USB Slave 例程使用芯片原生 USB 与 TinyUSB CDC，运行时提供虚拟串口。[USB Slave 官方说明](https://github.com/openedv/openedv-wiki-boards-dnesp32s3b3/blob/c6f9797b64aef2666547206b4b274017d6d28a3d/example-idf/usb_slave.md)
- 官方烧录说明使用同一 USB 连接，并允许在开发环境中选择 UART 或 JTAG 下载方式。[烧录官方说明](https://github.com/openedv/openedv-wiki-boards-dnesp32s3b3/blob/c6f9797b64aef2666547206b4b274017d6d28a3d/set-up-development-environment/esp-flash-download.md)

## 乐鑫官方 USB 能力边界

这些是 ESP32-S3 芯片能力，不自动证明某块底板已把接口、电源和跳线按相同方式接出。

- ESP32-S3 固定功能 USB Serial/JTAG 使用 GPIO20（D+）和 GPIO19（D-），可同时提供双向串口、烧录和 JTAG；macOS 通常使用 `/dev/cu.*` 设备。[乐鑫 USB Serial/JTAG 文档](https://docs.espressif.com/projects/esp-idf/en/stable/esp32s3/api-guides/usb-serial-jtag-console.html)
- 如果应用重配 USB 引脚或禁用 USB Serial/JTAG 控制器，端口会消失；官方恢复方式包括 GPIO0 拉低后复位进入下载模式。[乐鑫 USB Serial/JTAG 文档](https://docs.espressif.com/projects/esp-idf/en/stable/esp32s3/api-guides/usb-serial-jtag-console.html)
- ESP-IDF 的 TinyUSB Device 栈可实现 CDC、HID、MIDI、MSC、Vendor 和复合设备，CDC-ACM 是应用级 USB 串口实现。[乐鑫 USB Device Stack 文档](https://docs.espressif.com/projects/esp-idf/en/stable/esp32s3/api-reference/peripherals/usb_device.html)
- 首次通过芯片原生 USB 烧录时，若自动下载未生效，官方流程是按住 BOOT、按一下 RESET，再松开 BOOT。[乐鑫串口连接文档](https://docs.espressif.com/projects/esp-idf/en/stable/esp32s3/get-started/establish-serial-connection.html)

对 Vibe Buddy 而言，“一根 USB-C 同时负责供电、烧录、日志和运行期 NDJSON 串口”在芯片能力上可行，但要满足：

1. 实机 USB-C 确实连接到 GPIO19/20 的原生 USB，而不是只接 CH340C；
2. 固件选择 USB Serial/JTAG 控制台或 TinyUSB CDC 中的一条明确链路；
3. 固件不在运行中抢占/关闭该 USB 控制器；
4. macOS 上实测冷启动、烧录后重枚举、异常重启和 BOOT 恢复。

在以上实测完成前，不应把“一根线完成全部链路”写成已确认能力。

## 非官方实现参考

本节两个仓库都不是正点原子或乐鑫官方资料，**不能作为板型、GPIO、BSP、原理图或电气安全依据**。

### `second-state/echokit_box`

可借鉴：

- 用 Rust + ESP-IDF 组织设备固件，并通过 Cargo feature 选择集成式 BOX 配置；README 展示了 `espflash` 的构建/烧录流程。[项目 README](https://github.com/second-state/echokit_box/blob/4484efca885c2ffd01ffb1acdbb5817421583bd8/README.md)
- `atom_box.rs` 把屏幕、音频、按键、I2C/I/O 扩展器等集中在一个板级实现中。Vibe Buddy 可以借鉴这种“业务逻辑不直接引用裸 GPIO、板型差异封装在 board profile”的结构。[板级实现](https://github.com/second-state/echokit_box/blob/4484efca885c2ffd01ffb1acdbb5817421583bd8/src/boards/atom_box.rs)
- 可参考其 framebuffer、音频任务、按钮任务的并发组织方式，但需要重新用目标板官方资料和实机测试验证时序、缓冲区与引脚。

不可作为依据：该项目自行携带/修改的 HAL 驱动和 `atom_box.rs` 中的 I2C、I2S、LCD、I/O 扩展器引脚，即使注释出现 ALIENTEK 或 ESP32S3 BOX，也只是第三方实现声明。它与上文 BOX3/DNESP32S3 的已确认引脚明显不同，恰好说明“ESP32S3 BOX”名称不足以识别硬件。

### `second-state/echokit_server`

可借鉴：设备与服务端分层、WebSocket 会话，以及 ASR→LLM→TTS 服务编排和可配置 provider 的工程组织。[项目 README](https://github.com/second-state/echokit_server/blob/d1d976596f122976095b7da4df3e946baf152b96/README.md)

不可作为依据：这是上层语音代理服务器，不提供正点原子底板的官方硬件证明。Vibe Buddy v1 若采用本地守护进程 + USB NDJSON，WebSocket 与完整语音云管线也不应未经需求验证直接引入。

## 待实机/丝印确认

请一次性采集以下证据，避免继续靠商品名猜板：

1. 拆开或透过开孔拍摄主板正反面高清照片，必须能读出 PCB 型号、版本号和日期，例如是否为 `ATK-DNESP32S3B3 V1`。
2. 拍摄模组屏蔽罩丝印，确认 `ATK-MWS3S` 的具体版本；同时记录 Flash/PSRAM 的实机启动日志。
3. 拍清所有接口旁的丝印：USB-C、USB-A、UART、OTG、HOST、SLAVE、DOWNLOAD/JTAG。
4. 拍清 K0/K1/K2、蜂鸣器、MIC、扬声器、TF 及 LCD 排线/子板丝印。
5. 在 macOS 上分别插入每个 USB 口，保存 `system_profiler SPUSBDataType`、`ioreg -p IOUSB` 和 `/dev/cu.*` 变化；不要只凭接口外形判断 Host/Device。
6. 上电保存完整 ROM/bootloader 日志，记录芯片 revision、Flash、PSRAM、USB 枚举身份和固件标识。

在实机确认前保持以下项目为**未确认**：

- 精确底板型号及硬件 revision；
- LCD 控制器、分辨率、总线与背光控制；
- 触摸控制器、I2C 地址、中断/复位线；
- codec、ADC、功放、MIC 类型及所有 I2S/I2C 引脚；
- 蜂鸣器是否存在、直连还是经 I/O 扩展器、有效电平；
- K0/K1/K2 是直连 GPIO 还是扩展器位；
- USB-C 是 CH340C、USB Serial/JTAG、USB OTG/TinyUSB 中的哪条链路；
- USB-A 是否真的支持 Host、VBUS 供电能力及过流保护；
- 官方 BSP/资料包是否有对应老款 BOX 的独立版本。

## ESP-IDF 版本选择门槛

- **若确认为 BOX3**：正点原子官方环境文档明确要求其 ESP32-S3 例程使用 ESP-IDF `v5.3.x` 及以上，当前资料包示例提供 `v5.5.3` 离线安装包。[BOX3 官方安装说明](https://github.com/openedv/openedv-wiki-boards-dnesp32s3b3/blob/c6f9797b64aef2666547206b4b274017d6d28a3d/set-up-development-environment/esp-idf-install.md)
- **若确认为 DNESP32S3 开发板或老款 BOX**：已找到的 DNESP32S3 官方仓库没有声明可复现的最低/固定 ESP-IDF 版本；老款 BOX 的精确资料包又尚未取得。因此不能把 BOX3 的 `>=5.3.x` 要求外推给它们。[DNESP32S3 官方开发说明](https://github.com/openedv/ATK-DNESP32S3-Board/blob/c7434a3da5b9e6feda05added5d6a686f1c95f13/1_docs/Developing_With_ESP_IDF.md)
- **Vibe Buddy 的选择规则**：不要跟随 `latest` 或 `master`。先在精确板型的官方最低支持线内选择一个固定 release tag；候选版本只有在厂商原始例程与 Vibe Buddy 最小探针都通过“编译、烧录、重启、USB 重枚举、LCD、触摸、按键、音频采放”后才能锁定。乐鑫也明确建议依赖 ESP-IDF 的项目先遵循该项目自己的兼容版本说明。[乐鑫 ESP-IDF 版本说明](https://docs.espressif.com/projects/esp-idf/en/latest/esp32/versions.html)
- **当前建议**：若实机是 BOX3，以官方资料中的 `v5.5.3` 作为第一条复现基线，再单独验证同一 `release/v5.5` 系列的最新 bugfix tag；没有完整回归前不升 ESP-IDF 6.x。若不是 BOX3，在拿到对应资料包前不冻结 IDF 版本。

## 建议下一步

1. **先过型号门禁**：以 PCB 丝印和端口照片为准，把设备归入 BOX3、DNESP32S3 开发板或“其他老款 BOX”。
2. **获取精确官方资料包**：若不是 BOX3，使用丝印型号向正点原子技术支持索要对应 revision 的原理图、例程与出厂固件，不接受相近型号替代。
3. **做只读枚举**：在 Mac Studio 上记录每个 USB 口的 VID/PID、产品名、串口节点和重枚举行为，再决定烧录/运行链路。
4. **做最小硬件探针固件**：只验证串口、三按键、蜂鸣器、LCD 色块、触摸坐标、MIC 电平、扬声器正弦波和 TF 挂载；每项先用候选 BSP，再以逻辑/示波和实机现象复核。
5. **建立板型隔离**：代码层至少区分 `dnesp32s3_devboard`、`dnesp32s3_box3` 与 `unknown_legacy_box`，型号未确认时禁止选择默认 GPIO 表。
6. **最后才冻结 Vibe Buddy 接口**：硬件探针通过后，再确定一线 USB 的烧录、日志与 NDJSON 生命周期，并把经过验证的引脚表转录到 `docs/hardware.md`。

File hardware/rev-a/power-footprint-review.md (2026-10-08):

# Rev A 电源与封装审核

状态：第一轮审核已完成，发现项已记录；**尚未通过生产放行**。PCB 为四层、90×80mm 工程布局，非最终产品尺寸；目前未布线。

## 电源改动与计算

- 新增 U8 TPS22918DBVR，VBUS → U8 → VBUS_SW → 降压和模拟 LDO。C14/C17 移至受控上升时间的输出侧；连接器直接电容只剩 C10 4.7µF。已从 KiCad 导出网表确认此连接。
- C19=10nF 接 CT，QOD 悬空禁用快速放电，ON 接 VBUS。TI 给出的典型斜率时间 SR=0.55×CT(pF)+30，计算为 5530µs/V；5V 的 10%–90%上升约22.1ms。输出直接11µF的纯充电分量约2mA。这不包含稳压器启动时的负载和后级电容，也不是浪涌实测结果。
- **TPS22918 不具备本设计所需的 USB 枚举电流管理，也不是电流限制器**。没有 PD 协商；仅保留 CC 下拉与检测。普通电脑端口可用电流、上电枚举前负载及 USB 挂起策略仍需软硬件联合设计，不能默认允许取用1.5A。
- U3 保留 AP63203WU-7。L1 改为 SRP5030T-4R7M：4.7µH、DCR最大53mΩ、Irms4.6A、Isat6A。4.7µH位于稳压器手册建议2.2–10µH范围内；与典型表的3.9µH有意不同。按VIN5.5V、VOUT3.3V、1.1MHz算纹波约0.255A，2A负载峰值约2.13A；饱和电流也高于芯片峰值限流最大3.1A。仍需按电感容差、温升和实际布局做瞬态验证。
- 功放使用稳压3.3V，避免直接USB电压超过NS4150B允许范围。3.3V桥接理想正弦功率上限约V²/(2R)=1.36W（4Ω），实际未削顶功率更低，不能宣称能输出扬声器标称2W。
- U4 AP2112K-3.3只供模拟/音频芯片，按音频电流60mA的工程预留估算，在5.5V输入时损耗约0.132W；60mA不是整套芯片已验证最大值。

### 供电预算发现

暂取主控峰值预留500mA、屏幕100mA（屏幕规格未锁定）、模拟轨60mA，以及功放/降压效率均85%的估算。4.75V输入、0.4W声音输出时，输入约为 `(3.3×0.6+0.4/0.85)/(4.75×0.85)+0.06=0.67A`；1W声音输出时约0.84A。这些是设计预留值，不是器件数据表保证值。

因此，**Wi-Fi峰值、亮屏和声音同时运行不能宣称适配所有500mA电脑端口**。须完成USB供电能力识别、音量/背光/Wi-Fi功耗管理、枚举前启动预算和热插拔实测。当前功放默认关闭；这不足以证明整机枚举前电流合规。该项阻止生产放行，但不阻止先做布局审查。

## 封装核对

105个实体电路元件均分配了布局封装。脚号检查从KiCad导出XML网表到实际PCB焊盘逐件完成；不能等同于所有采购料号已经通过尺寸承认。

|器件|采用封装|检查与剩余条件|
|---|---|---|
|ESP32-S3-WROOM-1-N16R8|KiCad官方模组封装，含天线禁布区|41号地焊盘及内部散热孔；标准库0.2mm孔；按嘉立创多层板能力将最小孔径设为0.2mm，盘中孔填孔/盖孔工艺仍需报价确认|
|ES7210|VQFN32 4×4、0.4mm间距、EP2.8×2.8|与原厂本体、间距及EP尺寸匹配；将同芯片焊盘间隙设为0.15mm（库角部约0.183mm）；焊盘扩展量、钢网需在生产审核中复核|
|ES8311|VQFN20 3×3、0.4mm间距、EP1.7×1.7|同上；裸露焊盘21接地|
|NS4150B|MSOP8 3×3、0.65mm|引脚1～8与原厂连接对应；不替换成SOP8|
|AP63203|TSOT23-6|脚1FB、2EN、3VIN、4GND、5SW、6BST|
|AP2112K|SOT23-5|1IN、2GND、3EN、4NC、5OUT|
|TPS22918DBVR|SOT23-6|按TI脚表1VIN、2GND、3ON、4CT、5QOD、6VOUT|
|L1|Bourns SRP5030T|外形5.7×5.2mm；库焊盘2×1.8mm，中心距4.5mm，外跨度6.5mm|
|四个按键|TL3305A系列封装|选TL3305AF160QG上按式工程候选；高度、力值和壳体按帽需试装，不代表最终低成本采购已锁定|
|J2屏幕座|Hirose FH12-30S-0.5SH(55)|30针0.5mm下接候选；FPC厚度/插入方向与实际BOX3裸屏尚未实物核对，位置未冻结|
|MK1|项目CMC-4015-40P手焊封装|脚距1.4mm、孔0.7mm、外径4mm；实物针距公差需试装，禁止假定可回流|
|USB/扬声器连接器|USB4105-GF-A / B2B-PH-K-S|焊盘号已核；USB定位孔附近的默认孔铜间距规则冲突需向板厂确认|
|阻容及磁珠|0603/0805及指定磁珠|还需冻结具体阻容料号，检查电容直流偏压后的有效容量和电阻额定功率|

## 布局及检查边界

天线在上侧板边，三个业务键位于右上，USB在下侧，电源在左下；ADC与麦克风在右侧，DAC与功放在右下。安装孔已避开天线禁布区。完整内层地平面、USB回流、功放回流和地过孔属于后续布线工作，当前没有铺铜，不能声称已实现。

自动摆放用于初步分区，**尚未逐一优化所有去耦电容到芯片电源脚的距离与回流路径**。屏幕暂按背面装配思路预留接口，未绘制虚构的裸屏外形。PCB脚号覆盖检查通过，ERC为0错误0警告；当前DRC仍存在未连接和制造/丝印问题，详见 `drc-layout.rpt`，没有通过DRC放行。

## 依据

- [TI TPS22918 Rev C](https://www.ti.com/lit/ds/symlink/tps22918.pdf)
- [Diodes AP6320x DS41326 Rev3-2](https://www.diodes.com/datasheet/download/AP63200-AP63201-AP63203-AP63205.pdf)
- [Bourns SRP5030T原厂规格](https://www.bourns.com/docs/product-datasheets/srp5030t.pdf)
- [E-Switch TL3305产品页](https://www.e-switch.com/ja/product/tl3305-series-smt-tactile-switch/?part-number=TL3305AF160QG)
- 音频原厂资料与针脚证据见 `audio-component-evidence.md`。

工艺参考：[嘉立创制造工艺要求](https://member.jlc.com/portal/1/serviceGuide)，[当前加工能力](https://www.jlc.com/portal/vtechnology.html)。仅为工程设计规则依据，不是工厂审单通过。USB定位孔到铜约0.1944mm仍不足本工程0.25mm规则及通常0.2mm要求，保留报错，不用规则豁免掩盖。

本轮最终检查：ERC 0错误0警告；PCB DRC 4项USB定位孔间距错误、2项天线区丝印越界警告，另有264项未连接。安装孔/器件庭院重叠和天线禁布区冲突已消除。原理图完整针脚到PCB焊盘编号覆盖检查通过，不代表布线、回流和供电验收通过。

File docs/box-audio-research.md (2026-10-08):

# 正点原子 BOX 音频器件调查

调查日期：2026-09-18。对象是用户照片中的 ATK-DNESP32S3-BOX V1.1，不是乐鑫 ESP-BOX，也不是正点原子 BOX3。

## 当前结论

**尚未取得老款 BOX 麦克风和扬声器的完整可采购料号。不能据此冻结音频 BOM 或封装。**

| 项目 | 已有证据 | 未确认内容 |
| --- | --- | --- |
| 麦克风 | 原商品资料称“数字麦克风”；照片可见独立收音器件 | 厂家、完整料号、接口、电压、灵敏度、封装与声孔方向 |
| 扬声器 | 用户照片中为板载圆形喇叭 | 厂家、完整料号、标称阻抗、额定功率、尺寸和安装方式 |
| 音频芯片 | 项目已有正点原子实机记录为 ES8311，见 `hardware.md` | 不能由编解码器型号推出麦克风或扬声器料号 |

“数字麦克风”是商品功能描述，不能据此直接认定为 INMP441、PDM 或某个 I²S 器件。面包板麦克风录音成功也不能证明其与 BOX 同料。

## 资料追踪

1. [正点原子官方旧款产品文章](https://www.cnblogs.com/zdyz/p/18715431)链接到用户同款商品与老款资料入口。对应[商品链接](https://detail.tmall.com/item.htm?id=850275706131)的资料没有给出可确认的麦克风、扬声器完整料号。
2. 老款资料入口 `http://www.openedv.com/docs/boards/esp32/ATK-DNESP32S3BVXX.html` 与论坛 `https://openedv.com/thread-350585-1-1.html` 本次无法取得资料正文；论坛浏览出现证书问题。
3. [21ic 原理图条目](https://dl.21ic.com/download/atk_dnesp32s3b_v1-756799.html)列出 `ATK_DNESP32S3B_V1.0.pdf`，679 KB，下载需要 2 积分。本次只读到文件条目，未取得 PDF。它既不是已阅读的原理图证据，也不能证明与用户 V1.1 完全一致。
4. [官方 BOX3 录音实验](https://wiki.alientek.com/docs/Boards/IoT/DNESP32S3B3/example-idf/recoding/)写明 ES8311 输出、ES7210 采集；属于不同硬件版本，不可移植为老款器件结论。
5. [官方 BOX3 音乐实验](https://wiki.alientek.com/docs/Boards/IoT/DNESP32S3B3/example-idf/music/)前言出现 NS4168，后续资源与正文又介绍 ES8311。说明文字存在不一致，不能只摘一个芯片名建立 BOM。

## 官方 GitHub 仓库核查（2026-09-18 补充）

通过 GitHub API 分页检查 `openedv` 公开仓库，并读取相关仓库的 README 与文件树：

| 入口 | 实际内容 | 对当前 BOX 的适用范围 |
| --- | --- | --- |
| [openedv 官方账号](https://github.com/openedv) | 账号介绍为广州市星翼电子，链接 alientek.com 与 wiki.alientek.com | 官方仓库总入口 |
| [ATK-DNESP32S3-Board](https://github.com/openedv/ATK-DNESP32S3-Board) | 包含 `1_docs/1_sch/ATK_DNESP32S3 V1.2.pdf`、数据手册、IDF/Arduino/MicroPython 例程；README 标明 ES8388、五个按键等资源 | 是大开发板，不是用户的 BOX V1.1，不能直接套用其音频器件 |
| [openedv-wiki-boards-dnesp32s3b3](https://github.com/openedv/openedv-wiki-boards-dnesp32s3b3) | BOX3 在线教程源文件，包含录音、播放及原理图插图；下载页仍指向 openedv.com 资料中心 | 可作新版电路参考，不能证明老款同料 |
| [openedv-wiki](https://github.com/openedv/openedv-wiki) | 当前完整文件树中 ESP32 相关产品目录为 `docs/Boards/IoT/DNESP32S3B3` | 本次未找到老款 BOX 教程目录 |
| [ATK-MD0240 屏幕仓库](https://github.com/alientek-module/LCD-module_2.4-inch_ATK-MD0240) | 独立 2.4 英寸屏幕资料，已保存规格书和原理图 | 见屏幕调查；不能用于推断音频型号 |

本次没有找到老款 BOX V1.1 的官方公开 BOM 或独立 GitHub 硬件仓库。这是当前检索结果，不是断言厂家从未公开。已找到的公开仓库说明可以直接获得部分参考资料，但尚未解决老款麦克风与扬声器的完整料号。

## 对自研 PCB 的影响

### BOX3 官方原理图核查结果

已直接读取官方仓库原理图插图，固定版本为 `c6f9797b64aef2666547206b4b274017d6d28a3d`，原文件保存在 `hardware-reference/atk-box3/`。

| 器件/电路 | 图纸证据 | 结论与限制 |
| --- | --- | --- |
| MK1 麦克风 | 采集图标注 `4015`，两端经电容接 ES7210 MIC1P/MIC1N，并有 MICBIAS12 偏置网络 | 是模拟麦克风电路；`4015` 不是包含厂家、灵敏度等信息的完整可采购料号，不能仅凭该字符串冻结封装 |
| U8 | `ES7210`；MIC3P/MIC3N 经电容及 0Ω 电阻接 CODEC_OUTP/OUTN | 同时采集麦克风和播放参考信号；官方说明用于 AEC。硬件连接本身不代表回声消除已实现 |
| U9 | `ES8311`；OUTP/OUTN 输出，麦克风输入及 ASDOUT 未接 | 此设计主要用于播放，采集由 U8 承担 |
| U10 | `NS4150B`；模拟差分输入，VoP/VoN 接 LS+/LS−，电源 VBAT | 确认功放型号；图中没有扬声器完整料号、阻抗或额定功率 |
| 扬声器 | 产品介绍写 `2520腔体喇叭` | 仅有规格类别，仍不足以作为采购料号；不能推定 4Ω、8Ω 或额定瓦数 |

来源：

- [官方采集原理图](https://github.com/openedv/openedv-wiki-boards-dnesp32s3b3/blob/c6f9797b64aef2666547206b4b274017d6d28a3d/example-idf/img/ES7210.png)
- [官方播放与功放原理图](https://github.com/openedv/openedv-wiki-boards-dnesp32s3b3/blob/c6f9797b64aef2666547206b4b274017d6d28a3d/example-idf/img/z13.png)
- [官方产品介绍](https://github.com/openedv/openedv-wiki-boards-dnesp32s3b3/blob/c6f9797b64aef2666547206b4b274017d6d28a3d/start-guide/dnesp32s3-box3-introduction.md)

### 第一版方案判断

用户在查看比较后决定第一版加入 BOX3 参考音频架构：模拟麦克风 + ES7210 采集、ES8311 播放、NS4150B 功放和外接扬声器，并保留播放参考信号采集通路。此前将单 I²S 麦克风 + MAX98357A 作为自研板基线的建议被此决定替代；面包板配置继续保留。

当前仍暂不接模型。AEC、语音打断需要后续软件、时钟同步和声学验证，不能仅凭硬件参考通路承诺效果。具体麦克风、扬声器料号和各芯片订购型号仍需落实，尚未冻结生产 BOM。

以下约束保持不变：

- 用户指定正式版采用 BOX 屏幕，但没有要求音频器件必须与 BOX 完全同料。找原装料号与选择满足需求的量产器件是两条可独立推进的路线。
- 在获得老款原理图/BOM 之前，原装麦克风与扬声器保持“待确认”，不要填写猜测的型号、阻抗或功率。
- 如果改用有明确数据手册和供应来源的音频器件，必须标为自研方案选型，并重新验证采集、播放、供电与装配；不能称为 BOX 同款。
- 保留已验证的面包板 I²S 采集和 MAX98357A 播放方案作为功能参考，见 `pcb-rev-a.md`。现有低音量试听不代替扬声器额定功率与最大音量验证。

本次仅调查资料，没有修改固件、烧录设备或生成可投产文件。

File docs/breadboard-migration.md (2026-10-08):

# 面包板原型迁移记录

## 目标与保护边界

同时支持原有正点原子 BOX 和新的 ESP32-S3 面包板原型；通过独立板型配置和独立构建目录区分驱动、引脚及产物。新板暂不接业务按键。此处记录迁移准备，不代表已实现双板支持。

2026-09-17 检查时工作区干净，源码基线为 `685118ccc961d3fda70db7fdf1a8a5ff2d0b9f2c`。已归档至 `.probe/hardware-migration-backup/alientek-source-685118ccc961.tar.gz`，该本地目录不提交 Git。当前工作树未发现 `firmware/build` 下可归档的固件二进制；源码归档不能替代设备 Flash 备份，设备现有固件及语音包备份仍待完成。尚未对设备执行擦除或烧录。

## 已确认和待确认的硬件

- 用户照片确认屏幕背面标注 `DRIVER IC: ST7789`、`INTERFACE: SPI`、`RESOLUTION: 240*240`，正面标注 1.54 英寸 IPS。
- 正面从左到右引脚为 `GND VCC SCL SDA RES DC CS BLK`；背面视角顺序相反。接线必须按丝印，不按照片左右方向记忆。
- 屏幕供电规格和 BLK 控制电路尚未由对应资料或测量确认；背面丝印本身不证明可接 5V，也不证明 BLK 可以无条件直接接 GPIO。
- 主控模组丝印为 `S3-N16R8`，实际芯片、Flash 和 PSRAM 待读取确认。
- 功放模块丝印为 `MAX98357A`；麦克风具体型号、扬声器阻抗和功率待确认。
- 现有面包板接线未经核验，不从线色或遮挡照片推断网络。
- 用户确认当前电脑连接的是正点原子设备；新开发板尚待单独连接确认。

## 新开发板 USB 首次连接

用户随后拔掉正点原子、接入新开发板 OTG 口。当前枚举为 Espressif `USB JTAG/serial debug unit`，VID:PID `303A:1001`，序列号 `D0:CF:13:15:27:E4`，串口 `/dev/cu.usbmodem8401`。这证明新板原生 USB 枚举正常，不证明外设、存储或现有程序正常。串口路径和 VID/PID 可与旧板相同，切换设备不能仅凭路径识别个体。

`lsof` 显示现有 `vibebuddy` 进程正在占用该串口；尚未打开串口进行 ROM 查询、Flash 读取或烧录。需要先释放端口，再读取芯片信息及保存旧程序。正点原子设备 Flash 备份仍待重新连接时完成。

## 验证顺序

### 新板只读检测结果与备份取消

退出 App 后已释放串口，ROM 查询确认 ESP32-S3 revision v0.2、8 MB 内置 PSRAM、16 MB Flash（厂商 ID `c2`，器件 ID `2018`），USB Serial/JTAG，MAC `d0:cf:13:15:27:e4`。这些不是 PSRAM 运行压力测试结果。

读取新板完整 Flash 期间，用户明确要求“不用备份了”，已中断读取，不将此次文件视为完整备份；未擦除或烧录。该要求按当前语境应用于新板旧程序备份，原正点原子源码及双板支持要求仍保留。

1. 保留正点原子源码、确认原设备固件备份，再切换设备。
2. 新板断电，移除外设及电源轨连接线，仅保留主控开发板；核对面包板孔位无电源短接，再接单根 USB 数据线。识别端口和芯片，确认旧程序是否需要保存。
3. 确认屏幕电源和背光接法，冻结引脚表，再接屏幕测试色块、方向及动画。
4. 核对 MAX98357A 供电与接线，单独测试播报，再验证显示和音频并行。
5. 新板配置禁用未安装的按键，不依赖 BOX 的 XL9555；麦克风采集与语音对话是后续功能，不能当作现有播报代码的直接迁移。
6. 验证 App/daemon 在两台设备之间拔插切换，以及各板型构建和烧录目标的明确区分。

## 屏幕独立探针

用户已逐线核对并确认以下接线，照片不能替代电气通断测量：

| 屏幕 | 开发板 |
|---|---|
| GND | GND |
| VCC | 3V3 |
| SCL | G12 |
| SDA | G11 |
| RES | G10 |
| DC | G9 |
| CS | G8 |
| BLK | 3V3，暂时常亮 |

独立测试工程位于 `firmware-probes/spi-screen`，使用 ESP-IDF 5.5.3，运行 `bash tools/build-screen-probe.sh` 仅构建，不自动烧录。产物在该工程自己的 `build/` 目录；原有 `firmware/` 和 `tools/flash.sh` 不变。探针并非完整 Vibe Buddy 新板固件，不提供 Agent 协议、音频或按键功能。

测试采用 4 MHz SPI、RGB565、240×240、初始偏移 `(0,0)`。上电先依次显示红、绿、蓝各一秒，然后显示左红中绿右蓝三条色带、四周白边框、左上白块和右下黄块；中间白块水平移动。实际颜色、方向、边框完整性须观察屏幕验收，日志提交成功不能证明屏幕收到数据。若有偏移或反色，依据实机结果调整。

烧录前必须核对目标 MAC 为 `d0:cf:13:15:27:e4`，避免仅凭可复用的串口路径选设备。探针使用自己的默认分区表，只允许写到此新板，不可使用它覆盖正点原子。

### 首次烧录结果

2026-09-17 用户接回 USB 后串口变为 `/dev/cu.usbmodem1101`。ROM 查询重新确认 MAC 为 `d0:cf:13:15:27:e4`，再写入独立探针的 bootloader、分区表和 app；三段均通过 esptool 写入哈希校验。未执行整片擦除，正点原子未连接、未写入。

启动日志确认运行 `vibebuddy-spi-screen-probe`、ESP-IDF v5.5.3、16 MB Flash，打印指定 GPIO、图案提交和刷新计数。打开 USB 串口引发一次 `USB_UART_CHIP_RESET` 后正常启动。当前证据仅证明烧录、启动和 SPI 提交成功，屏幕实际显示仍待用户观察或照片确认。

用户随后回复“一致”，确认屏幕色带、边框及动态测试画面符合预期，屏幕阶段通过。

## MAX98357A 播放探针

用户确认自行核对完成以下连接：VIN/SD 接 3V3、GND 共地、BCLK 接 G5、LRC 接 G6、DIN 接 G7、GAIN 悬空；扬声器两线接功放输出正负端，输出负端不是 GND。3.3V 仅作为当前低音量测试供电，尚未验证最大音量或正式产品供电。

探针新增独立音频任务，复用 `firmware/main/assets/done.pcm`（24 kHz、16-bit、小端双声道），数字幅度缩小至 1/16。启动后播放三次“任务完成”，间隔五秒，随后停止；按 RST 可重复测试。屏幕动画同时运行，用于观察电源和并行运行情况。当前探针仍不支持 Agent 协议、录音或按键。

音频版已编译通过；2026-09-17 再次核对目标 MAC 后，经 `/dev/cu.usbmodem8401` 仅写 app 地址 `0x10000`，写入哈希校验通过。声音是否清晰、播放期间画面是否稳定仍需用户验收。

### 音频实机验收

用户确认听到语音、声音清晰，播放期间屏幕没有闪烁或重启。因此当前接线下的小音量 MAX98357A 播放及屏幕并行刷新通过实机验收。此结论不覆盖最大音量、Wi-Fi 并行、麦克风录音或长期稳定性。下一阶段迁移 Vibe Buddy 的 240×240 界面和 Agent 通信，同时保留原正点原子板型；麦克风及语音对话仍作为后续独立功能验证。

## 正式固件迁移（2026-09-17）

已新增 `breadboard` 板型，保留默认 `alientek` 板型。原 BOX 本轮没有连接、擦除或烧录；原音频、显示和按键路径保留。用户此前取消了备份，本轮未继续读取 Flash；开头的备份待办是历史状态，不是本轮前置条件。

分别构建：

```bash
bash tools/build-firmware.sh alientek
bash tools/build-firmware.sh breadboard
```

各自产物和 sdkconfig 位于 `firmware/build-alientek`、`firmware/build-breadboard`。脚本仅编译；烧录前必须重新核对串口与设备 MAC，不能以端口名称判断设备身份。旧 `tools/flash.sh` 仍是默认 BOX 入口，不能用它烧录面包板。

面包板复用已验证的屏幕与功放引脚，不需改线。SPI 频率仍为 4 MHz。所有原有页面先按 4:3 比例缩至 240×180，在 240×240 屏幕上下留边；采用面积采样避免小字整条笔画丢失。此为功能迁移版，小字仍比原屏小，尚未单独重排方屏界面。BLK 接 3V3，熄屏和识别闪烁通过 LCD 显示开关实现，不等于切断背光供电。

MAX98357A 使用软件音量，App 的 20～100 档映射到 PCM 振幅的 1.25%～6.25%，默认 65 档约为 4.06%。此限制沿用已通过的低音量测试范围。未接业务按键，固件明确上报 `BUTTONS NOT FITTED`；不会读取 BOX 的按键扩展芯片。麦克风、Wi-Fi 语音对话尚未迁移或验收。

### App 和切换板型

App 根据设备上报的 `BOARD` 选择对应固件。旧 BOX 固件没有该字段时仍按 BOX 兼容。重新连接时清除上一台设备的板型、音量、音色等缓存。设备与请求板型不符时，daemon 拒绝烧录。截图链路支持 320×240 和 240×240。

`bash app/scripts/build-app.sh --debug` 已生成同时包含两种固件的 `app/build/Vibe Buddy.app`，本轮运行的就是这个包，没有替换 `/Applications` 下的 App。它仍使用原有 Hook 路径和本机配置。日常切换先断开当前板，再连接另一块，App 自动重连；不要同时插两台依赖自动选择。

### 已验证的结果与边界

- 两种正式固件编译通过；番茄钟、休闲模式、语音包格式测试通过。
- Rust 工作区 119 项测试通过，包括两种尺寸截图和阻止旧 App 请求向面包板写入 BOX 固件；Swift `SelfTest` 通过，App 打包通过。
- 每次烧录前 ROM 核对 MAC 为 `d0:cf:13:15:27:e4`。首次写入正式分区表、bootloader、app；随后只更新面包板 app。写入均通过哈希校验。
- 实机上报 `AUDIO CODEC MAX98357A`、`VOICES builtin`、`VOLUME 65`、`BOARD goouuu-s3-spi`。正式分区为 4 MiB app + 2 MiB voices。
- App 状态确认新板已连接；收到这次 Codex 会话的真实 Hook，设备截图显示 `CX:VIBE BUDDY` 工作卡片。
- 经 App/daemon 截图接口取得实际设备的 240×240 PNG；通过同一链路提交音量试听。
- 对正在连接的新板提交旧板固件请求，实测返回 HTTP 409“固件板型与连接设备不匹配”，没有执行写入。

验收截图、状态与构建/测试/烧录日志存于忽略目录 `.probe/breadboard-formal/`。正式版本的肉眼画面与试听还待用户确认；原 BOX 本轮只完成编译回归，未做换线后的物理切换验收。探针成功不代表录音、语音对话或量产可靠性已通过。

用户随后回复“正常”，正式固件的画面与播放通过本轮实机验收。

## 麦克风采集测试

圆形模块已按引脚文字连接：VDD→3V3、GND→GND、L/R→GND、SCK→G15、WS→G16、SD→G17。具体芯片型号仍未确认；当前按 Philips I²S 数字麦克风接口验证。麦克风 SD 是数据输出，不能与 MAX98357A 的 SD 使能脚混接。

仅面包板编译 `agent_mic.c`，使用 I2S1；扬声器仍为 I2S0。`device.mic.capture` 命令采集两秒：16 kHz、左右各 32 位槽、每帧 64 个时钟，丢弃开始 128 ms，取左槽高 16 位。仅在命令期间打开采集，完成即关闭、释放通道。当前是同步硬件测试，录音及导出期间界面会短暂停止刷新，不是正式语音交互实现。

退出 App 释放串口后运行：

```bash
python tools/capture-mic.py /dev/cu.usbmodemXXXX .probe/mic/test.wav
```

需要 pyserial；脚本核对固件板型、倒数三秒、接收带偏移量的 Base64 数据，核对完整 64,000 字节后写本地 WAV，并输出峰值、去直流 RMS 和削波计数。不会上传录音。测试后重新打开本次构建的 App。

2026-09-17：两种板型构建通过。核对 MAC `d0:cf:13:15:27:e4` 后仅更新新板 app，哈希校验通过。首次两秒采样完整收到 32,000 点，最小 -133、最大 521、去直流 RMS 117.51、削波 0，保存于 `.probe/mic/baseline.wav`。这证明链路产生非恒定数据，尚不能单凭底噪认定语音录音通过；等待用户说话测试。

用户准备好后完成说话采样：`.probe/mic/speech.wav`，32,000 点，最小 -1168、最大 283、整段去直流 RMS 165.42、削波 0。按 100 ms 分块观察，开始有直流衰减，后半段 RMS 出现约 14～142 的变化，不能把整段 RMS 增长直接等同于清晰人声。保留原始文件，另生成 80 Hz 高通、16 倍增益的 `speech-listen.wav` 供用户试听；清晰度待确认。

本轮 App 重新编译遇到本机 SDK 缺少 `SwiftUIMacros.StateMacro` 插件。App 源码未因录音测试改变，因此保留此前已验证的 App 可执行文件，仅更新包内面包板固件和构建标识、重新 ad-hoc 签名；未把本次完整 App 构建记为通过。录音完成后已重新启动该 App。

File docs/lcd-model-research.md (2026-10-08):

# 正点原子 2.4 英寸屏幕料号调查

调查日期：2026-09-18。当前决定：正式产品按 BOX3 裸屏参考设计推进，不再要求确认与旧 BOX 同款；1.54 英寸面包板屏仅作验证。下文独立模块调查为历史记录，当前依据见末节。

## 结论与证据边界

- 客服推荐的[独立屏幕商品](https://detail.tmall.com/item.htm?id=768663566580)与 **ATK-MD0240** 的尺寸、分辨率、驱动和接口规格一致，属于高度匹配的模块型号。
- `alientek-module/LCD-module_2.4-inch_ATK-MD0240` 公开资料包中的屏幕规格书明确写出 **深圳市优智景科技有限公司（UNVISION），TFT024B462**。这是有厂商规格书支持的裸屏候选，不是根据 ST7789 猜出的料号。
- **尚不能证明用户 ATK-DNESP32S3-BOX V1.1 的当前生产批次使用同一裸屏**。缺少该 BOX 的 BOM、实物屏幕排线料号或厂商对该料号的明确确认。不得将候选写成已冻结生产物料。
- 未验证裸屏库存、价格、最低采购量及长期供货；模块零售价不能当作裸屏成本。

## 已取得资料

来源仓库固定提交：[`a4ac06ddfc1a22bfd0b0379aca148c95fd68eebd`](https://github.com/alientek-module/LCD-module_2.4-inch_ATK-MD0240/tree/a4ac06ddfc1a22bfd0b0379aca148c95fd68eebd)。下载后原样保存，没有编辑 PDF。

| 文件 | 本地副本 | 用途 |
| --- | --- | --- |
| `1_docs/2_datasheet/Specifications.pdf` | [裸屏规格书](hardware-reference/atk-md0240/Specifications.pdf) | TFT024B462，V1.0，2023-12-19；封面标为初步规格书 |
| `1_docs/1_sch/ATK-MD0240_V1.1.pdf` | [模块原理图](hardware-reference/atk-md0240/ATK-MD0240_V1.1.pdf) | LCD、接口模式选择、背光与外围电路；图纸标题栏为 V1.0、2024-03-18，与文件名版本不同 |
| `1_docs/2_datasheet/Module_dimension_diagram.pdf` | [模块尺寸图](hardware-reference/atk-md0240/Module_dimension_diagram.pdf) | 带底板模块机械资料，不能替代裸屏尺寸图 |

## 裸屏参数

以下取自规格书 PDF 第 4、5、7、10 页（印刷页码 3、4、6、9）；尺寸与原理图已视觉核对。

| 项目 | 厂商资料 |
| --- | --- |
| 料号 | TFT024B462 |
| 厂家 | 深圳市优智景科技有限公司 |
| 屏幕 | 2.4 英寸 IPS，全视角，常黑 |
| 分辨率 | 240×320；横向使用对应 320×240 |
| 驱动 | ST7789 |
| 本体尺寸 | 43.12×59.80×3.05 mm，排线另计 |
| 显示有效区域 | 36.72×48.96 mm |
| 接口 | MCU 8080 8/16 位、SPI；按 IM 引脚配置 |
| 屏端引脚 | 1～29；与转接板的 32 Pin 接口不同 |
| 背光 | 4 LED 并联，典型总电流 80 mA，典型电压 3.0 V |
| 典型亮度 | 300 cd/m² |

## 设计前需解决的资料问题

1. 仓库 README 写模块最大 50 mA，但裸屏规格书背光典型为 80 mA；不能据前者直接冻结供电预算，需核对背光实际驱动电流。
2. README 的 32 Pin 数据位映射与原理图不一致：README 将 12～27 顺序写为 D0～D15，原理图为 12=D15、27=D0。应核实实物/最新生产图，而非照 README 接线。
3. 裸屏机械图端点标为 1～29，间距为 1.00 mm，但尺寸公式写有 `P1.0*(32-1)=28.00`，算式存在笔误。不得由该错误公式制作最终焊盘。
4. 29 引脚裸屏焊接端、32 Pin 转接板接口、2×4 SPI 排针是三个不同连接层级；必须区分。

## 下一步

可据此开始屏幕外围原理图草案；冻结 PCB 焊盘前，取得 TFT024B462 最新承认书和样品，核对排线及连接方式。若要确认 BOX 原装同款，用其屏幕背面/排线完整丝印与这个料号比对，或让供应商明确确认，不需要继续泛问“是不是 ST7789”。本次不修改固件、不烧录设备、不下单。

## 2026-09-18：BOX3 裸屏参考更新

用户要求直接使用 BOX 同款裸屏，不接受 ATK-MD0240 模块，并允许参考 BOX3。BOX3 官方 LCD 教程原理图标为 **TFT024B579-B0**，配 30 针、0.5mm 间距、下接 FPC 座；这一接口与此前独立模块 TFT024B462 的资料不同，禁止混用。

来源：[官方 BOX3 LCD 文档固定版本](https://github.com/openedv/openedv-wiki-boards-dnesp32s3b3/blob/c6f9797b64aef2666547206b4b274017d6d28a3d/example-idf/lcd.md)，[官方电路图](https://github.com/openedv/openedv-wiki-boards-dnesp32s3b3/blob/c6f9797b64aef2666547206b4b274017d6d28a3d/example-idf/img/19.png)。本地原图：`hardware-reference/atk-box3/19.png`。

Rev A 当前仅采用其电气映射：1 LEDA、2 LEDK/GND、3 GND、4/5 3V3、6/7 3V3、8 GND、9 RESET、10 CS、11 SCLK、12 DC、13 GND、14 MOSI、15–30 GND。引脚 11/12 必须按 SPI 模式连线，不按并口功能名猜测。

仍未取得可信的 TFT024B579-B0 裸屏承认书，外形、排线厚度、出线位置、背光电流尚未冻结。没有给屏幕座指定生产封装，也没有生产板框。用户后续明确“参考 BOX3 就行”：旧 BOX 同款证明及客服链接不再是继续设计的前提。继续依据 BOX3 官方资料核定屏幕接口和布局；原始资料未给出的尺寸仍须标明未确认，不能以此授权推断未知规格。

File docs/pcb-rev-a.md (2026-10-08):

# Vibe Buddy 第一版自研 PCB 设计输入

状态：设计输入草案，已有部分原理图草稿，已有初步 PCB 布局，但尚无可下单的生产文件。

## 设计工具与工程位置

- 用户已确定使用 KiCad 设计原理图和 PCB，嘉立创负责制造及贴片。
- 工程目录：`hardware/rev-a/`，可编辑工程与设计资料纳入仓库版本管理。
- 用户已安装 KiCad 10.0.6，命令行工具与符号、封装、3D 模型库已确认可用。九页原理图草稿已绘制电路并通过解析与导出，ERC 为 0 错误、0 警告；USB 功耗/浪涌和屏幕机械输入仍未闭环，已有未布线 PCB，DRC 尚未通过。具体进度见工程目录 README。
- 制造交付物包括 Gerber、钻孔、BOM、贴片坐标及装配说明；不能将草稿目录或未验证文件作为生产包。

## 已确认的目标

- 保留正点原子 BOX、面包板两种已有固件支持；自研板另有硬件配置。
- 不接模型、不开发语音对话；保留麦克风硬件和已通过的录音能力。
- 第一版自研 PCB 纳入 BOX3 参考音频架构：模拟麦克风 + ES7210 采集、ES8311 播放、NS4150B 功放和外接扬声器，包含播放信号回送采集芯片的 AEC 参考通路。硬件纳入不等于 AEC 软件或语音打断已经完成。
- 屏幕显示、扬声器播放、麦克风采集、USB 与 App 通信已获得本轮用户实机确认。
- 首批产品目标为 20～50 台，先做少量工程样机验收，再决定试卖批次。
- 对外只保留一个 USB-C、三个业务按键和一个独立复位键；不安装 TF 卡座、额外 USB、UART 扩展插座及通用扩展排针。屏幕、麦克风、扬声器和 Wi-Fi 保留。

## 建议的第一版范围（待冻结）

- ESP32-S3 模组焊接到自研主板，保留 Wi-Fi 能力；不把整块 GOOUUU 开发板装到量产主板上。
- 唯一 USB-C 同时供电、原生 USB 通信和下载；暂按无电池方案设计。
- 主板包含电源、音频功放、三个业务按键和一个独立复位键；不额外增加外露下载键。板内预留下载模式、复位及必要调试测试点，具体电路和故障恢复流程在原理图阶段确认并验证。
- 不依赖 TF 卡存储；现有声音与界面资源继续按板载 Flash 方案规划，后续核算固件、资源及升级所需容量。录音验证不要求设备长期保存录音。
- 正式版按 BOX3 的 2.4 英寸裸屏参考设计推进（用户最新确认）；1.54 英寸面包板屏仅作验证。用户明确拒绝带底板模块，要求裸屏。BOX3 官方电路中的 TFT024B579-B0（30 针、0.5mm、下接 FPC）作为当前电气参考，不再要求确认与旧 BOX 同款；仍须核定机械规格；不能套用 ATK-MD0240/TFT024B462 的 29 针资料。见[屏幕料号调查](lcd-model-research.md)。扬声器通过接口连接。
- 麦克风采用模拟采集路线，须确认完整料号、偏置、灵敏度、收音孔与机械安装方式；不直接沿用面包板数字麦克风的接法。音频架构依据见[音频调查记录](box-audio-research.md)。
- 板形以易调试为先，保留固定孔；尺寸和元件位置仍需和屏幕、按键、扬声器装配配合。

## 面包板已验证的信号分配

| 功能 | GPIO / 电源 | 验证边界 |
| --- | --- | --- |
| ST7789 SCK / MOSI | 12 / 11 | 4 MHz SPI，240×240 |
| ST7789 RES / DC / CS | 10 / 9 / 8 | 已实机显示 |
| 屏幕 VCC / BLK | 3V3 / 3V3 | 模块接法，不代表裸屏电路 |
| MAX98357A BCLK / LRC / DIN | 5 / 6 / 7 | 24 kHz 播放 |
| MAX98357A VIN / SD | 3V3 / 3V3 | 仅低音量负载验证 |
| 数字麦克风 SCK / WS / SD | 15 / 16 / 17 | 16 kHz，Philips I²S 左槽 |
| 麦克风 VDD / L/R | 3V3 / GND | 型号未确认；用户已听清录音 |
| 业务按键 | 未分配 | 尚未在面包板连接测试 |

该表是逻辑 GPIO，不能直接当作所选模组的焊盘编号。设计时必须逐项核对模组数据手册。
该表保留面包板验证记录；自研板采用新的音频架构，需另行分配 I²C、I²S/MCLK 和功放控制信号，重新验证固件与硬件。

## 布板前需要补齐

1. 模组完整料号、厂家数据手册、推荐焊盘和天线净空；“N16R8”是存储容量标识，不能用来推断不同厂家的模组封装兼容。
2. 屏幕按 BOX3 的 TFT024B579-B0 参考设计；核定实际供货屏幕的排线、背光和机械尺寸后冻结屏幕座及位置。此前 ATK-MD0240/TFT024B462 资料只保留为调查历史，不能用于当前屏幕的封装或尺寸。
3. 模拟麦克风完整料号、规格书与封装；ES7210、ES8311、NS4150B 的完整订购型号、供应情况、供电与时钟要求。核对播放参考信号幅度与采集通道配置，重新做录放音和参考通道验证。
4. 扬声器标称阻抗和额定功率；据此选择功放供电和输出能力，不能把低音量 3V3 测试当作最大音量设计依据。
5. 三个业务按键与一个复位键的操作方向、位置与封装；确认无外露下载键时，通过板内测试点进入下载模式的恢复方案。
6. 板框、固定孔和接口出线方向。3D 打印可以容纳修改，但不替代机械尺寸确认。

## 设计与交付顺序

1. 冻结器件和接口，完成 BOM 初稿及供应情况检查。
2. 原理图：USB-C CC、电源预算/稳压/去耦、保护、复位下载、音频与按键。
3. PCB：核对封装，处理天线净空、USB 走线、功放回流和麦克风噪声/声孔；做 ERC、DRC 与人工复核。
4. 导出可编辑 EDA 工程、Gerber/钻孔、BOM、贴片坐标及装配说明；平台匹配料号和生产稿后再下单。
5. 少量工程样机：上电电压、下载、USB、屏幕、按键、录放音、供电负载、Wi-Fi 和组合运行验证。
6. 修订后再考虑 20～50 台试卖，不能从面包板通过直接跳到整批生产。

嘉立创 PCB 加 SMT 流程需要板文件、BOM 和坐标文件，参见[官方贴片下单流程](https://www.jlc.com/portal/server_guide_19858.html)。平台制造检查不等于功能验证。

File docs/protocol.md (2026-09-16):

# Vibe Buddy Protocol v1

Vibe Buddy Protocol 是 `vibebuddyd` 与 Vibe Buddy 设备之间的应用协议。v1 使用 UTF-8 NDJSON；transport 负责可靠地传送字节流，协议不依赖具体串口名称。

## Framing

- 每条消息是一个 JSON object，以单个 LF（`\n`）结束。
- 接收端同时接受 CRLF（`\r\n`），但发送端统一使用 LF。
- 空行忽略。
- 单条 JSON 最多 1024 bytes，不含行结束符。超出后丢弃整行并返回 `ERROR input_too_large`。
- v1 不支持跨行 JSON、JSON array 或多个 JSON object 共用一行。

## Envelope

每条消息必须包含：

- `version`：整数；v1 必须等于 `1`。
- `event`：非空字符串。

`id`、`title`、`message` 等字段由具体事件使用。Stage 1 不要求 `id`，所以下面的 Hello 是合法消息：

```json
{"version":1,"event":"task.done","title":"Hello"}
```

接收端忽略未知字段，以便旧固件接受新增的可选字段。未知 `event` 也必须完成 framing 和 envelope 解析；Stage 1 固件会输出其名称，不因事件尚未实现而破坏连接。无法识别的 `version` 返回 `ERROR unsupported_version`，不能按 v1 猜测处理。

## 方向

Mac 到设备的首批事件：

- `task.start`
- `task.done`
- `task.error`

当前固件识别：

- `task.start`：工作中，不播放语音。
- `agent.input_required`：需要用户确认，播放一次“需要你确认”。
- `task.done`：完成，播放一次“任务完成”，5 秒后回到空闲。
- `task.error` / `agent.blocked`：失败，播放一次“任务遇到问题”。
- `agent.idle`：回到空闲，不播放语音。
- `device.heartbeat`：证明链路存活，不显示、不回显诊断行、不播放语音。

`vibebuddyd` 可附加最多 3 项的 `tasks` 数组。数组按最近活动倒序，设备按给定顺序绘制任务卡：

```json
{"version":1,"event":"task.start","title":"GAMMA","tasks":[{"title":"GAMMA","status":"working","elapsed_s":75},{"title":"BETA","status":"input_required","elapsed_s":900}],"stats":["7 DONE","4 ASKS","1H23 BUSY"]}
```

每项包含 `title`、`status` 和 `elapsed_s`，可选 `project`；当前状态值为 `working`、`input_required`、`done`、`failed`。`title` 是卡片第一行：Agent 自己给会话起的名字（Claude App 的会话标题、Codex 的线程名）或分支名，都没有才是项目名；`project` 是项目名，设备画在第二行，与标题重复时不画。旧固件会按 v1 规则忽略 `tasks` 与 `project`。未来事件可以包括 `task.progress`、`task.cancelled`、`agent.waiting`、`message`、`system` 和 `device.status`。

`elapsed_s` 是该活动进入**当前状态**已经过去的秒数，不是距上一个事件的秒数：工作中的卡片回答「这个 turn 跑了多久」，等待确认的卡片回答「等了多久」。设备收到后自行继续计时，因为可见状态不变时 `vibebuddyd` 会去重、不再发消息，而屏幕上的数字必须一直走。也正因为要去重，`elapsed_s` 与 `stats` 都在去重之后才盖到事件上；放进快照会让每个工具事件都变成一次重绘，把工作中的动画不断打回第一帧。

`stats` 是最多 3 行当日战绩，空闲屏轮播它们。它随每条状态事件下发而不只随 `agent.idle`：`task.done` 之后设备是自己回到空闲的，那一刻正是用户会看的一眼，缓存的战绩必须已经包含刚刚完成的那一件。计数按本地自然日归零，并持久化到 `~/Library/Application Support/VibeBuddy/stats.json`，否则每次重启 daemon 屏幕上写着「今天」的数字都会归零。

当一个后台任务完成、但画面仍需显示其他活动任务时，`vibebuddyd` 会在当前状态事件上附加 `"announcement":"done"`。这是一次性语音通知，不改变画面状态；`announcement_id` 用于标识对应 turn。设备收到它时排队播放一次“任务完成”。失败走同一条路径，取值为 `"announcement":"failed"`，播放一次“任务遇到问题”。

当聚合任务变化仅需重绘既有的输入等待状态时，`vibebuddyd` 会附加 `"suppress_audio":true`。设备继续显示 `agent.input_required`，但不重复播放已经播过的提醒。`announcement` 的一次性通知优先于此字段。

`vibebuddyd` 每 5 秒发送一次心跳，并捎上自己的构建标识、本地小时数与本地日期：

```json
{"version":1,"event":"device.heartbeat","build":"9b642af 2026-09-14 17:41","hour":14,"day":20260915}
```

`build` 是 `git describe --always --tags --dirty` 加上二进制的时间戳。它随心跳重复发送而不是握手一次，因为设备可能随时重启，一次性的握手会丢。设备只在取值变化时才重绘，否则每 5 秒就要刷一次屏。`hour` 是 Mac 端的本地小时，休闲模式用它区分白天黑夜；`day` 是本地日期 YYYYMMDD，番茄钟的当日记录按它清零。设备没有时钟，也不该为了这个去连 Wi-Fi。旧 daemon 不发它们时设备当白天处理、不换日。

Mac 端发往 BOX 的 CH343 UART 桥时按线速分段写（每 128 字节等它走完再写下一段）：这条桥一次吞不下超过两百字节的连续数据，会把内容错位而长度不变；原生 USB 口整帧写。

设备只显示它，不拿它和自己的固件标识比对：两边的发布节奏本来就不同步，把不一致当告警只会制造持续的假警报。字段缺失时设备显示 `?`，这说明对面是个还不发这个字段的旧 daemon。

设备超过 15 秒没有收到**任何**消息即判定失联，覆盖显示为 `NO LINK` 并把画面转灰；收到任何一行合法消息即恢复。判定依据是所有消息而不只是心跳，因为繁忙时真实事件本身就足以证明链路存活。固件不为心跳输出 `EVENT` 诊断行，否则每天会产生上万行日志。

设备到 Mac 的事件同样使用 NDJSON，例如：

```json
{"version":1,"event":"button","button":"K2","action":"press"}
```

当前只上报 K2 短按，在任何模式里都上报。K0（番茄钟）、K1（切换模式、长按去休闲）与 K2 长按（静音）由固件自己消费，不上报。短按在松开时才算数，因为只有等到松开才知道它不是长按的开头；上报时机因此从按下推迟到松开。模式与番茄钟见 [`pomodoro.md`](pomodoro.md)，休闲见 [`leisure.md`](leisure.md)。`vibebuddyd` 收到后按这个顺序选落点：等人回答的任务优先（屏幕主状态显示的就是它，而且它 blocking 着人）；其次是最近一次播报过结束的任务——它已经离开卡片栈，屏幕上再也看不到，而还在跑的任务一直挂在屏幕上、本来就不需要 K2 定位；再次才是最新工作项。落点由下一次播报接力替换，不设时间窗：这台设备的用处正是人不在电脑前，用墙上时钟让落点过期，等于假设用户一直守在旁边。选定活动后，Codex 顶层活动打开自身 thread，子 Agent 活动打开拥有它的父 thread；Claude Code 先把 Hook 报的 CLI `session_id` 连同 `cwd` 在 Claude App 的会话索引里解析成桌面会话 id，再用 `claude://code/continue?session=<桌面会话 id>` 精确跳转；解析不到（会话只跑在终端里）才退回 `claude://resume?session=<session_id>` 导入；GitHub Actions 打开对应 run。当前没有活动时回到最近一次可定位的来源；该定位会写入本机状态文件，daemon 重启后仍然有效。候选按这个顺序逐个试：Codex 线程先在本机线程表里核对存在，不存在就跳过，免得打开一个空白会话。K0、K1 和长按/释放尚未绑定。

固件输出的 `READY`、`EVENT`、`TITLE` 和 `ERROR` 行是实机链路验收用的诊断文本，不是设备到 Mac 的正式 JSON 事件。同类的还有 `MODE DUTY` / `POMODORO` / `LEISURE`（模式切换），`POMODORO FOCUS START` / `FOCUS END` / `BREAK START` / `BREAK END` / `PAUSED` / `RESUMED` / `STOPPED` / `BREAK SKIPPED`（番茄钟转换），`LEISURE ALERT` / `BORED` / `SLEEPY`、`LEISURE SKIT <名>`、`LEISURE LIGHTS OUT` / `ON`（休闲），以及 `CLOCK HOUR <n>`（收到的小时数变化）、`TALLY LOADED <次> <秒>S DAY <日期>`（开机恢复的当日记录）、`MUTE ON` / `OFF`（长按 K2）与 `AUDIO MUTED <哪句>`（静音期间被吞掉的语音）。番茄钟与休闲的状态都只在固件里，Mac 端只记日志。

## 设备维护：眨眼确认与语音包写入

这些消息是 App 在操作设备本身，不算 Agent 的动静，不叫醒休闲，也不产生 `EVENT` 诊断行。

`device.hello` 是 Mac 端刚连上时的一声招呼：模式、固件构建号、音色、音量只在开机或变化时才报，daemon 比设备重启得勤，不问就一直不知道。设备回四行诊断：`DISPLAY READY BUILD …`、`MODE …`、`VOICES …`、`VOLUME …`。

`device.echo` 是链路自检：设备把 `data` 字符串的长度与 CRC32 回成 `{"event":"echo","length":…,"crc":…}`，再原样回显一行 `ECHO …`，用来查串口有没有收错字节；排查 UART 桥那次就是靠它。

`device.identify` 让设备背光快闪约一秒，任何模式下都看得见；引导里用它确认连的是哪一台。设备回一行诊断 `IDENTIFY`。

`device.volume` 调扬声器音量：`level` 是 codec 的 20 到 100，越界的值收进范围，存在设备的 NVS 里，重启不丢；不带 `level` 只是问一声。设备应用后回一行 `VOLUME <n>`（没有 codec 的板子回 `VOLUME ERROR` 再报当前值）；带 `preview: true` 时再用当前音量播一句"任务完成"，静音时和别的播报一样不出声。下限不到零：静音只在设备上长按 K2，而且有意不持久化。

语音包（格式见 `firmware/main/agent_voice_pack.h`）经同一条串口写进 `voices` 分区，不复位、不用 esptool，两种接法行为一样。停等流控：Mac 每发一块就等设备回执，没有回执不发下一块。

```json
{"version":1,"event":"voice.begin","size":1523456}
{"version":1,"event":"voice.chunk","seq":0,"crc":305419896,"data":"<base64，最多 672 字节原始数据>"}
{"version":1,"event":"voice.end"}
```

设备的回执：

```json
{"version":1,"event":"voice.ready","seq":-1}
{"version":1,"event":"voice.ack","seq":0}
{"version":1,"event":"voice.written","voice":"wanwanxiaohe"}
{"version":1,"event":"voice.error","seq":12,"message":"ESP_ERR_INVALID_CRC"}
```

`begin` 会先等正在播的一句放完，再擦掉所需范围；`size` 是整包字节数，含 256 字节包头。块必须按 `seq` 从 0 连续到达，每块原始数据不超过 672 字节，base64 后整行仍在 1024 字节上限内；`crc` 是这一块原始字节的 CRC32（zlib 同款），设备解码后当场核对，不符就回 `voice.error` 放弃，不等到最后。包头那 256 字节留在设备内存里，`end` 时设备回读 flash 校验载荷 CRC，通过才写包头，然后重新映射并切换到新音色；任一步失败都回 `voice.error`、放弃会话，分区在固件看来是空的，播报回落到内置音色。写入期间的播报用内置音色。

## Stage 1 错误输出

| 输出 | 含义 |
| --- | --- |
| `ERROR invalid_json` | 该行不是完整合法的 JSON |
| `ERROR invalid_message` | 根不是 object，或缺少/误用 `version`、`event`、`title` |
| `ERROR unsupported_version` | `version` 不是 `1` |
| `ERROR input_too_large` | 一行超过 1024 bytes |

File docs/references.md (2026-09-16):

# 实现参考与适用边界

本文记录可借鉴的外部实现，不把参考项目当成 Vibe Buddy 硬件事实来源。

## `second-state/echokit_box`

核查版本：[`4484efca885c2ffd01ffb1acdbb5817421583bd8`](https://github.com/second-state/echokit_box/tree/4484efca885c2ffd01ffb1acdbb5817421583bd8)

可借鉴：

- Rust 固件使用 `esp-idf-svc`，并通过 `esp-idf-sys` 接入 C component；这说明“Rust 上层 + 厂家/ESP-IDF C driver”在 ESP32-S3 上是可行组织方式。[Cargo.toml](https://github.com/second-state/echokit_box/blob/4484efca885c2ffd01ffb1acdbb5817421583bd8/Cargo.toml)
- 工程把板级差异放在 board module/feature 中，适合以后确有第二种硬件时参考；Vibe Buddy 第一块板不提前复制其多板抽象。
- 仓库固定 `ESP_IDF_VERSION = "v5.4.1"`，使用 `xtensa-esp32s3-espidf` 和 `espflash`。[`.cargo/config.toml`](https://github.com/second-state/echokit_box/blob/4484efca885c2ffd01ffb1acdbb5817421583bd8/.cargo/config.toml)
- README 记录 EchoKit 设备通过标为 OTG/SLAVE 的口枚举成 JTAG 串口，并给出 `/dev/cu.usbmodem...` 示例；这可作为 Vibe Buddy 插板后的一个排查假设，不能当成目标板结论。[README](https://github.com/second-state/echokit_box/blob/4484efca885c2ffd01ffb1acdbb5817421583bd8/README.md)

不直接采用：

- EchoKit 的协议面向 Wi-Fi/WebSocket 音频会话，服务端事件用 MessagePack，设备命令部分用 JSON；Vibe Buddy v1 是本地 USB 串行 NDJSON，目标和 framing 不同。[`src/protocol.rs`](https://github.com/second-state/echokit_box/blob/4484efca885c2ffd01ffb1acdbb5817421583bd8/src/protocol.rs)
- `atom_box.rs` 和 `components/hal_driver` 中的 GPIO、ES8311、XL9555、320×240 LCD 等参数只属于 EchoKit 对应板型。除非精确 PCB/原理图证明一致，否则不得复制到 Vibe Buddy。
- 该仓库使用 GPL-3.0。没有确定 Vibe Buddy 的许可证兼容策略前，只借鉴思路，不复制实现代码。

## `second-state/echokit_server`

核查版本：[`d1d976596f122976095b7da4df3e946baf152b96`](https://github.com/second-state/echokit_server/tree/d1d976596f122976095b7da4df3e946baf152b96)

可借鉴：

- 服务端采用 Rust、Tokio、Axum、Serde 和 tracing/logging 相关生态，与 `vibebuddyd` 的候选技术栈方向一致。[Cargo.toml](https://github.com/second-state/echokit_server/blob/d1d976596f122976095b7da4df3e946baf152b96/Cargo.toml)
- WebSocket I/O 使用独立消息处理循环和 channel 把 transport 与业务流水线分隔；Stage 2 设计串口收发/重连任务时可参考这个职责边界。[`src/services/ws.rs`](https://github.com/second-state/echokit_server/blob/d1d976596f122976095b7da4df3e946baf152b96/src/services/ws.rs)

不直接采用：

- EchoKit Server 是 ASR → LLM → TTS 语音平台，范围显著大于本地状态守护进程。Vibe Buddy 不引入其 AI provider、VAD、音频流、MCP 或配置系统。
- 它的网络协议、重试和音频分块策略不能替代 Vibe Buddy Protocol 的版本、逐行 framing、输入上限与未知事件规则。
- 该仓库同样使用 GPL-3.0；当前阶段不复制代码。

## 对 Vibe Buddy 的实际影响

1. 保持 Mac 端 Rust + Tokio/Axum 的方向，但到 Stage 2 才创建依赖与代码。
2. 固件仍优先评估 ESP-IDF C；是否采用 Rust 固件必须以官方 BSP 可复用程度、构建复杂度和 Stage 1 最小链路为依据，不因参考仓库使用 Rust 就自动选择 Rust。
3. 插板后重点观察 `/dev/cu.usbmodem*`、USB Serial/JTAG 与多 USB 口角色，但不预设结果。
4. 许可证策略未确定前，参考仓库只用于架构比较和排障线索。

## 当前设备运行固件：`78/xiaozhi-esp32`

核查版本：[`v1.9.4 / 3ced7709c65a39494f5684e99111854a5bcbd8c7`](https://github.com/78/xiaozhi-esp32/tree/3ced7709c65a39494f5684e99111854a5bcbd8c7)

2026-09-14 的实机启动日志自报应用 `xiaozhi` 1.9.4、ESP-IDF v5.5 和板型 `atk-dnesp32s3-box`，与该固定源码版本相符。这个仓库因此是“当前设备运行固件”的一手实现来源，可用于理解当前可工作的板级配置和选择兼容 ESP-IDF 版本。

适用边界：它不是正点原子的厂家原理图/BSP，也没有给出用户手中 PCB 的硬件版本。其 [`config.h`](https://github.com/78/xiaozhi-esp32/blob/3ced7709c65a39494f5684e99111854a5bcbd8c7/main/boards/atk-dnesp32s3-box/config.h) 中的 GPIO、LCD 和音频参数只能作为待核对候选，不能单独成为 Vibe Buddy 的最终硬件依据。

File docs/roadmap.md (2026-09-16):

# Vibe Buddy 路线图

## 阶段门禁

### Stage 0 — Hardware Probe（已完成，2026-09-14）

完成条件：

- 当前开发主机确认为 Mac Studio。
- 记录开发工具路径与版本，明确缺失项和安装方案。
- 保存 ESP32S3-BOX 插拔前后的 USB、IOKit 和串口枚举，并形成差异。
- 确认 VID/PID、设备名、串口节点、USB 类型、烧录路径和运行时路径，或把尚不能证明的项目明确标记为待验证。
- 精确识别 PCB 型号/版本，并调查匹配的官方 schematic、BSP 和 examples；无法取得的资料必须记录证据边界，并继续锁定依赖它们的外设阶段。

最小 USB/烧录路径未确认前，Stage 0 不通过。

实机结论：ATK-DNESP32S3-BOX V1.1 通过 `303A:1001` 原生 USB Serial/JTAG 枚举；同一 `USB-SLAVE` 连接已完成 ROM 探测、烧录和运行时通信。老款 BOX V1.1 的厂家原理图/BSP 仍未取得，因此 Stage 3～5 的外设 GPIO 不得按相似板卡猜测。

### Stage 1 — Serial Hello（已完成，2026-09-14）

只实现串口逐行读取和 JSON 解析，不实现 LCD/audio。验收必须是 Mac → USB → ESP32 → JSON parse 的实机链路，不能用本机模拟或仅编译通过代替。

实机结论：ESP-IDF v5.5.3 构建和烧录成功；Mac 发送 `{"version":1,"event":"task.done","title":"Hello"}` 后，ESP32 实际返回 `EVENT task.done` 与 `TITLE Hello`。原厂 16 MB Flash 已在写入前完成本地受限权限备份。

### Stage 2 — `vibebuddyd`（已完成，2026-09-14）

实现 `POST /v1/events`、最小 Transport 抽象、`SerialTransport` 和断线重连；用 HTTP 请求完成实机验收。

实机结论：`vibebuddyd` 按 `303A:1001` 自动发现 `/dev/cu.usbmodem8401`；HTTP 事件到达 ESP32 并得到对应诊断输出。真实拔掉 `USB-SLAVE` 后记录到 `Device not configured`，插回后自动重新连接；重连后的 `task.done` 事件成功到达设备。

### Stage 3 — LCD（已完成，2026-09-14）

实机确认 320×240 ST7789 i80 与 XL9555 背光控制后，实现氛围小助手的 Ready、Working、Input Required、Done、Failed 动画。Mac 端多任务快照可绘制最多 3 张卡片，最新在最上。

### Stage 4 — Audio（已完成，2026-09-14）

实机探测到 ES8311，并确认 I2S 与扬声器使能链路。需要确认、完成和失败使用固件内置的 24 kHz PCM 中文短语音；工作中与空闲保持静音。用户已听觉确认“需要你确认”。

### Stage 5 — Buttons（K2 已完成，2026-09-14）

K2“打开当前来源”的按键与 Mac 激活链路已经通过实机验收：探针确认 K2 为 XL9555 P0.3、低电平有效（`P0: 0xFF → 0xF7 → 0xFF`）；设备通过 NDJSON 上报单击，用户短按后 `vibebuddyd` 能拉起目标应用。精确路由已修正两处：Codex 子 Agent 映射到父 thread；Claude Code 不再聚焦 Ghostty，而是打开 Claude App 的对应 Code 会话。2026-09-15 修正了其中的定位错误：CLI `session_id` 到桌面会话不是一对一，原先的 `claude://resume` 会打开一个内容陈旧的影子会话，现改为先解析桌面会话 id 再用 `claude://code/continue` 跳转。两条 deeplink 均已单独验证，完整 K2 页面跳转仍需一次实机短按确认。

2026-09-15 加入第二个场景：番茄钟（专注 25 分钟、休息 5 分钟，表盘仿 Focus To-Do）。三个键各管一件事：K0 短按开始/暂停/继续、长按放弃，K1 切换场景，K2 照旧打开来源；阶段结束播钟声加语音并自动切到番茄钟，下一阶段等用户按 K0 才开始。状态机有主机测试，画面有主机预览。同日经 UART 桥烧录后实机确认三个键都工作：K0 为 GPIO0，K1 由候选位探针定为 XL9555 P0.4，K2 照旧打开来源；场景切换、开始、暂停、继续均有设备回报。第一次实机也暴露出短促轻点会被 100 ms 的采样加两次一致去抖丢掉，已改为 20 ms 采样、翻转即生效。专注结束与休息结束的钟声、语音和自动切场景尚待一次完整的 25 分钟实机验收。设计见 [`pomodoro.md`](pomodoro.md)。

同日再加入第三个模式：休闲。值班空闲 5 分钟进无聊档随机演七出小剧目，30 分钟进困倦档转暗睡觉，夜里 23 点到 7 点睡够 90 分钟关背光；Agent 一有动静、任何按键、链路断开都立刻回值班；番茄钟待开始放五分钟、暂停放半小时视为人走了。心跳新增本地小时数。导演有主机测试，剧目有 GIF 预览。实机验收用时间压缩 60 倍的固件走完整条链：无聊、剧目轮换、困倦、熄灯、被 Agent 事件唤醒并点亮、再次入睡，设备回报与预期一致。设计见 [`leisure.md`](leisure.md)。

Stage 5 整体尚未完成：K2 在无活动/已完成状态下的扩展行为仍未实现；原计划的 K0 静音已让位给番茄钟。

### Stage 6 — `beacon`

实现 `start`、`done`、`error` 和 `run`；CLI 只调用 `vibebuddyd`。

### Stage 7 — App（已实现，2026-09-16；待人工过一遍界面）

原生 SwiftUI 菜单栏 App 看管 `vibebuddyd`、首次引导、接入 Agent、挑选播报音色并写入设备的 `voices` 分区、更新固件、看设备画面。设计见 [`app.md`](app.md)。

实机结论：固件加了 2 MB `voices` 分区，语音包经串口协议分块写入并回读校验，换音色不刷固件；`device.hello`、`device.identify`、`device.echo` 事件到位。daemon 有状态接口与 SSE、配置文件、截图、语音包写入、ROM 协议烧录（块 256 字节、桥接分段，MD5 校验后硬复位，在 App 看管下约 38 ms 一块，1.5 MB 四分钟）。`vibebuddy-hook` 取代两个 Python 脚本。App 在 dragon 的 Mac 上取代了 LaunchAgent：拉起 daemon、SSE 驱动菜单、SIGTERM 与 SIGKILL 下 daemon 都跟着退出。经 App 走通：写语音包、烧固件、Hook 转发。尚未由人过目的是界面本身（引导六步、设置五页、通知）。

途中查明 CH343 UART 桥吞不下超过两百字节的连续数据（见 `LESSONS.md`），daemon 改为按线速分段发送，顺带修掉了长事件行偶发 `invalid_json` 的老毛病。

## Later

可选任务标题、microphone、voice interaction、长期任务历史、Wi-Fi、WebSocket transport、progress、多设备。多 Agent 的三任务实时卡片已提前进入 Stage 4。

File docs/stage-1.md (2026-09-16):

# Stage 1 — Serial Hello 验收记录

验收时间：2026-09-14（Asia/Singapore）

## 结论

Stage 1 **已通过实机验收**。证据链是 Mac Studio → `/dev/cu.usbmodem8401` → ESP32-S3 原生 USB Serial/JTAG → `vibebuddy-fw` → cJSON parse → USB 返回结果，不是本机模拟或仅编译通过。

本阶段没有初始化 LCD、audio、microphone、buzzer 或 buttons。实机烧录后，LCD 继续显示原小智固件最后留下的配网页面；这不是旧固件仍在运行，而是 LCD 控制器显存和背光在 ESP32 软件复位后保持，且 Stage 1 固件没有覆盖画面。随后重复执行 Serial Hello 仍通过，直接证明当前运行的是 Vibe Buddy 固件。LCD 清屏和新 UI 必须等待 Stage 3 及厂家硬件依据。

## 构建

- ESP-IDF：v5.5.3。
- Target：`esp32s3`。
- 固件项目名：`vibebuddy-fw`。
- 应用镜像：183,616 bytes（`0x2cd40`）。
- 默认应用分区：1 MiB，剩余 82%。
- 首次构建发现并移除了一个无效 Kconfig symbol 和一个 C qualifier warning；重新构建无编译警告。

构建和烧录入口：

```bash
./tools/flash.sh /dev/cu.usbmodem8401
```

## 原厂固件备份

写入 Vibe Buddy 前，使用 `esptool read_flash` 读取了完整 16 MiB Flash：

- 本机文件：`.probe/factory/atk-dnesp32s3-box-v1.1-xiaozhi-1.9.4-2026-09-14.bin`
- 大小：16,777,216 bytes。
- SHA-256：`7e0ae33002423eaca46a6e6c1f8cc6d92a2a04babd99fe7aa2a4ede788a01ec2`。
- 权限：`600`。
- Git 状态：`.probe/` 已忽略，不进入仓库。

整片备份可能包含原固件的配网或设备状态，因此按敏感本机证据处理，不复制到文档或远程仓库。

## 烧录

`idf.py flash` 通过同一 `/dev/cu.usbmodem8401` 成功写入：

| Offset | 内容 | 写入大小 |
| --- | --- | --- |
| `0x0000` | bootloader | 20,832 bytes |
| `0x8000` | partition table | 3,072 bytes |
| `0x10000` | `vibebuddy-fw` | 183,616 bytes |

三段写入均由 esptool 报告 hash verified，随后完成 hard reset；设备仍以 `/dev/cu.usbmodem8401` 重新枚举。

## Mac → USB → ESP32 验收

执行：

```bash
uv run --with pyserial python tools/serial-hello.py /dev/cu.usbmodem8401
```

Mac 实际发送：

```json
{"version":1,"event":"task.done","title":"Hello"}
```

ESP32 实际返回：

```text
EVENT task.done
TITLE Hello
PASS Stage 1 Mac -> USB -> ESP32-S3 -> JSON parse
```

在用户观察到旧小智画面仍停留后，同一命令再次得到完全相同的 PASS，排除了“烧录未生效或仍在运行旧固件”。Hello 没有 `id`，验证了 Stage 1 对可选 `id` 的实际兼容。NDJSON framing、版本策略、未知字段/事件和输入上限见 [`protocol.md`](protocol.md)。

同一实机还补测了非法 JSON、`version: 2`、带未知字段的 `custom.event`、CRLF framing 和 1025-byte 超限输入，依次得到：

```text
ERROR invalid_json
ERROR unsupported_version
EVENT custom.event
ERROR input_too_large
PASS protocol error, version, extension, CRLF, and size handling
```

## 未证明的事项

- 这次验收没有证明 LCD、audio、buzzer、buttons 或 TF 卡可由 Vibe Buddy 驱动。
- 这次验收没有实现 `vibebuddyd`、HTTP API 或 serial reconnect；这些属于 Stage 2。
- 当前串口节点编号可能随 macOS 枚举变化，后续 daemon 不能写死 `usbmodem8401`，应使用 VID/PID 与 USB serial 发现设备。

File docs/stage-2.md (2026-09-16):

# Stage 2 — `vibebuddyd` 验收记录

验收时间：2026-09-14（Asia/Singapore）

## 结论

Stage 2 **已通过实机验收**。Mac 本机 HTTP 请求经 `vibebuddyd`、`SerialTransport`、ESP32-S3 原生 USB Serial/JTAG 和 Vibe Buddy Protocol 到达 `vibebuddy-fw`；真实 USB 拔插后 daemon 自动重新发现并连接设备，重连后的事件也成功送达。

## 实现边界

- `POST /v1/events` 默认只监听 `127.0.0.1:7331`。
- `vibebuddy-protocol` 负责 version、非空 event、未知扩展字段、NDJSON 编码和 1024-byte 上限。
- `SerialTransport` 默认按 `VID:PID 303A:1001` 发现唯一设备，不写死 `/dev/cu.usbmodem8401`。
- `VIBEBUDDY_SERIAL_PORT` 可显式指定串口；`VIBEBUDDY_USB_SERIAL` 可在多块同型号设备中筛选目标。
- 发送队列容量为 64。HTTP `202 Accepted` 只表示入队；队列满或 worker 已停止时返回 `503 Service Unavailable`。
- 串口读写失败后保留尚未确认 flush 的当前帧，每 500 ms 重新发现并连接设备。

本阶段没有安装 macOS 后台服务，也没有实现 `beacon` CLI、LCD、audio 或 buttons。

## 自动化检查

执行：

```bash
cargo fmt --all -- --check
cargo test --workspace
cargo clippy --workspace --all-targets -- -D warnings
```

结果：6 个测试通过，Clippy 无告警。测试覆盖无 `id` 的 Hello、未知字段保留、不支持的 version、超长消息、HTTP 入队与 NDJSON framing，以及 USB serial 格式归一化。

## HTTP → USB → ESP32 实机链路

daemon 自动发现并打开：

```text
串口已连接 port=/dev/cu.usbmodem8401
```

发送：

```json
{"version":1,"event":"task.start","id":"stage2-live","title":"Stage 2 HTTP"}
```

HTTP 实际返回 `202 Accepted`。ESP32 随后实际返回：

```text
EVENT task.start
TITLE Stage 2 HTTP
```

`version: 2` 的请求实际返回 `400 Bad Request`，没有进入串口队列。

## 真实断线重连

保持同一 `vibebuddyd` 进程运行，用户拔掉 `USB-SLAVE` 后日志记录：

```text
串口读取失败，开始重连 port=/dev/cu.usbmodem8401 error=Device not configured (os error 6)
```

重新插回后，无需重启 daemon：

```text
串口已连接 port=/dev/cu.usbmodem8401
```

随后发送：

```json
{"version":1,"event":"task.done","id":"stage2-reconnect","title":"Reconnect verified"}
```

设备实际返回：

```text
EVENT task.done
TITLE Reconnect verified
```

因此本阶段证明的是同一 daemon 进程在真实 USB 断开、重新枚举后恢复传输，不是进程重启或本地模拟。

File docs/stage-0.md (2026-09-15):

# Stage 0 — Hardware Probe 记录

更新时间：2026-09-14（Asia/Singapore）

## 当前结论

Stage 0 **已通过**。开发主机、USB 插拔差异、运行时串口和 ROM 下载链路已经实机确认；芯片、Flash/PSRAM 容量、PCB 版本以及当前运行固件的板型标识也已确认。

2026-09-14 的实物照片显示 PCB `V1.1` 丝印、ATK-MWS3S `N16R8` 模组、`B0/K1/K2`、`USB-SLAVE`、`HOST` 和 `UART` 接口，以及麦克风、扬声器、蜂鸣器和 TF 卡座。结合当前固件自报的 `atk-dnesp32s3-box`，实机可识别为 **正点原子 ATK-DNESP32S3-BOX V1.1**，不是 DNESP32S3 开发板、BOX0、BOX2 或 BOX3。

厂家针对这款老 BOX V1.1 的原理图/BSP 仍未从当前官方站点或 GitHub 组织取得。这个缺口不阻塞仅使用芯片原生 USB Serial/JTAG、且不访问外设 GPIO 的 Stage 1；它继续阻塞 LCD、音频、蜂鸣器和按键实现。未取得厂家依据前，不冻结这些外设的 GPIO。

Stage 1 所需的最小 USB 前置条件已经满足：同一根 USB-C 线可供电、读取运行时日志，并让 `esptool` 进入 ESP32-S3 ROM 下载链路。这里的“下载链路已确认”不等于“Vibe Buddy 固件已烧录”；本阶段没有擦除或写入 Flash。

## 主机身份

| 项目 | 实测结果 |
| --- | --- |
| Hostname | `Michaels-Mac-Studio.local` |
| Model Name | Mac Studio |
| Model Identifier | `Mac14,14` |
| Chip | Apple M2 Ultra |
| Architecture | `arm64` |
| macOS | 26.6.2（25G83） |

主机满足“只在 Mac Studio 创建项目”的前置条件。

## 开发环境

### 初始探测

| 工具 | 初始状态 | 初始版本/路径 | 对当前阶段的影响 |
| --- | --- | --- | --- |
| Homebrew | 已安装 | 6.0.22，`/opt/homebrew/bin/brew` | 满足安装依赖所需条件 |
| Python 3 | 已安装 | 3.14.5，`/opt/homebrew/bin/python3` | 满足 ESP-IDF 6.x 官方最低 Python 3.10 要求 |
| CMake | 未安装 | 不在 PATH，Homebrew 无 installed keg | 固件构建前必须补齐 |
| Ninja | 未安装 | 不在 PATH，Homebrew 无 installed keg | EIM/ESP-IDF 前置依赖，必须补齐 |
| Rust | 已安装 | 1.98.0，`/Users/dragon/.cargo/bin/rustc` | 满足后续 Mac daemon 开发 |
| Cargo | 已安装 | 1.98.0，`/Users/dragon/.cargo/bin/cargo` | 满足后续 Rust workspace 构建 |
| ESP-IDF / `idf.py` | 未发现 | PATH、`~/esp`、`~/.espressif` 常见位置均未找到 | Stage 1 固件构建前必须安装 |
| `esptool` / `esptool.py` | 未发现 | 命令与当前 Python 环境均未找到 | 识别芯片/烧录前必须由选定 IDF 环境补齐 |

### 已执行安装与验证

按 Espressif 当前 macOS 官方安装路线，已通过 Homebrew 安装：

- CMake 4.4.3
- Ninja 1.13.2
- dfu-util 0.11
- libslirp 4.9.4
- ESP-IDF Installation Manager（EIM）0.19.0

安装 EIM 时，Homebrew 自动从 6.0.22 更新到 7.0.0，并要求显式信任第三方 tap。仅对 Espressif 官方 `espressif/eim` tap 建立了信任；没有处理或信任其他 tap。

实机日志显示当前固件由 ESP-IDF v5.5 构建；同一固件的 `xiaozhi` v1.9.4 源码要求 ESP-IDF 5.4 或以上。基于这两条依据，已用 EIM 安装固定稳定版 ESP-IDF v5.5.3，而不是追踪 `master` 或切换到 6.x。

安装过程出现 `compote cooking` 命令缺失及 component cache 下载失败警告，因此没有把安装器的成功提示直接当作验收。重新激活环境后独立验证结果如下：

| 工具 | 实测版本/路径 |
| --- | --- |
| ESP-IDF | v5.5.3，`/Users/dragon/.espressif/v5.5.3/esp-idf` |
| `idf.py` | ESP-IDF v5.5.3 |
| `esptool` | v4.12.0 |
| Xtensa GCC | 14.2.0_20251107 |
| IDF CMake | 3.30.2 |
| IDF Ninja | 1.12.1 |

EIM 在仓库根目录生成了包含本机绝对路径的 `eim_config.toml`。它是本机安装状态，不是项目构建配置，已加入 `.gitignore`，不提交到仓库。

官方依据：

- [ESP-IDF v6.0 macOS 安装说明](https://docs.espressif.com/projects/esp-idf/en/stable/esp32p4/get-started/macos-setup.html)
- [EIM 官方说明与 macOS Homebrew 安装方式](https://docs.espressif.com/projects/idf-im-ui/en/latest/)
- [EIM 前置依赖](https://docs.espressif.com/projects/idf-im-cli/en/latest/prerequisites.html)
- [ESP-IDF v5.5.3 官方 release](https://github.com/espressif/esp-idf/releases/tag/v5.5.3)

## USB 未连接基线

用户确认开发板尚未接入 Mac Studio 后，已保存 `.probe/baseline`。该快照中：

- `system_profiler SPUSBDataType` 退出码为 0，但在 macOS 26.6.2 上返回空结果。
- `ioreg -p IOUSB -l -w 0` 正常返回 USB 树。
- `/dev/cu.*` 与 `/dev/tty.*` 只出现 Bluetooth、Bose QC Earbuds 和系统 debug 节点。
- 未观察到名称包含 ESP、CP210、CH34、FTDI、USB Serial/JTAG 或 CDC 的设备/串口。

这构成开发板未连接时的正式基线，但仍不能推导目标板采用哪种 USB 实现。原始 `ioreg` 包含不断变化的统计计数器；探测脚本同时生成只保留设备树、VID/PID、产品名、厂商名、序列号和 location ID 的归一化摘要，后续差异以摘要为主、原始输出为证据补充。

## USB 连接后对比

2026-09-14，用户把开发板通过计划采用的 USB-C 线接到 Mac Studio 后，已保存 `.probe/connected` 并与基线比较。连接期间同时出现一台 iPhone；它不符合 ESP/串口筛选条件，已从目标设备判断中排除。

| 项目 | 实测结果 |
| --- | --- |
| USB product | `USB JTAG/serial debug unit` |
| Manufacturer | Espressif |
| VID:PID | `303A:1001`（十进制 `12346:4097`） |
| USB serial | `98:88:E0:06:8B:CC` |
| Location ID | `138412032` |
| Runtime callout device | `/dev/cu.usbmodem8401` |
| Runtime tty device | `/dev/tty.usbmodem8401` |
| USB implementation | ESP32-S3 原生 USB Serial/JTAG；不是 CH340、CP210 或 FTDI bridge |

`system_profiler SPUSBDataType` 在本机仍以退出码 0 返回空内容，因此本次结论由 `ioreg` 插拔差异和新增 serial device node 共同支撑。

## 运行日志与 ROM 下载链路

以 115200 baud 打开 `/dev/cu.usbmodem8401` 后，设备因原生 USB 串口打开动作发生 `USB_UART_CHIP_RESET`。这不是完全被动的读取，但没有擦除或写入 Flash。启动日志确认：

- ESP32-S3 ROM 标识 `esp32s3-20210327`，芯片 revision v0.2。
- 16 MB QIO Flash，80 MHz。
- AP 64 Mbit（8 MB）Octal PSRAM，80 MHz。
- 当前应用项目 `xiaozhi`，版本 1.9.4，ESP-IDF v5.5。
- 当前固件板型标识 `atk-dnesp32s3-box`。
- 当前固件成功初始化 LCD/LVGL、ES8311 codec 和 Wi-Fi；这些日志只证明现有固件可驱动实机，不自动证明 Vibe Buddy 可复用其全部板级参数。

随后执行只读 `esptool flash_id` 探测：

- 成功连接 ESP32-S3 QFN56 revision v0.2。
- 确认 USB mode 为 `USB-Serial/JTAG`，40 MHz crystal，8 MB embedded PSRAM。
- Flash manufacturer/device 为 `68:4018`，探测容量 16 MB，3.3 V。
- RAM stub 上传、460800 baud 切换和 hard reset 均成功。

该探测证明 ROM 下载通路工作，但未执行 erase、write 或 Vibe Buddy 固件烧录。实际写入后的重新枚举和运行时通信仍属于 Stage 1 实机验收。

## 当前固件源码旁证

启动日志中的 `xiaozhi` 1.9.4 与板型标识可对应到该固件的固定源码版本。其 `atk-dnesp32s3-box` board 目录记录了 ST7789 i80、XL9555 和 ES8311 等配置，可用于下一步核对实物，但它是当前运行固件的上游源码，不是正点原子的官方原理图/BSP，不能单独作为最终 GPIO 依据。

- [`xiaozhi-esp32` v1.9.4 固定提交](https://github.com/78/xiaozhi-esp32/tree/3ced7709c65a39494f5684e99111854a5bcbd8c7)
- [该版本的 `atk-dnesp32s3-box/config.h`](https://github.com/78/xiaozhi-esp32/blob/3ced7709c65a39494f5684e99111854a5bcbd8c7/main/boards/atk-dnesp32s3-box/config.h)

## Stage 0 门禁

- [x] 经用户确认的未连接 USB 基线。
- [x] 连接后快照及拔插前后 USB 差异。
- [x] VID/PID 与设备名称。
- [x] native USB 或 USB-UART bridge 的证据。
- [x] ROM 下载路径与当前固件运行时串口路径；实际 Vibe Buddy 烧录后仍需复验。
- [x] PCB 完整型号/版本：ATK-DNESP32S3-BOX V1.1。
- [x] 已整理 DNESP32S3 开发板和 BOX3 两套候选官方资料，并明确不可混用。
- [x] 确定实机版本；厂家 schematic、BSP 和 examples 仍缺失并继续锁定外设阶段。
- [ ] LCD、touch、audio、microphone、buzzer、K0/K1/K2 的官方引脚/器件依据。

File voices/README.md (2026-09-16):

# 音色库

同一套五句提示，用五种音色各合成一遍，供日后在 macOS 端让用户挑选。每个子目录就是一整套固件资产，格式与 `firmware/main/assets/` 完全相同（24 kHz、16-bit、双声道、小端序 PCM，峰值 -1 dBFS，番茄钟两句前面拼了钟声），复制过去重新编译即可换音色。`wanwanxiaohe/` 与当前固件资产逐字节一致。

| 目录 | 音色 | 引擎 | 备注 |
|---|---|---|---|
| `wanwanxiaohe/` | 湾湾小何 `zh_female_wanwanxiaohe_moon_bigtts` | 火山引擎豆包语音 1.0（`seed-tts-1.0`） | 台湾口音，小智音箱同款，当前固件用的就是它 |
| `xiaohe2/` | 小何 2.0 `zh_female_xiaohe_uranus_bigtts` | 火山引擎豆包语音 2.0（`seed-tts-2.0`） | 普通话，同一角色的 2.0 版 |
| `hsiaoyu/` | 晓雨 `zh-TW-HsiaoYuNeural` | 微软 edge-tts | 台湾女声，不用密钥 |
| `hsiaochen/` | 晓臻 `zh-TW-HsiaoChenNeural` | 微软 edge-tts | 台湾女声，不用密钥 |
| `xiaoxiao/` | 晓晓 `zh-CN-XiaoxiaoNeural` | 微软 edge-tts | 大陆女声，不用密钥 |

五句台词固定为：需要你确认 / 任务完成 / 任务遇到问题 / 专注结束，休息一下 / 休息结束，对应 `input_required` / `done` / `failed` / `focus_done` / `break_done`。

## 重新生成

```bash
# 火山引擎音色（密钥是豆包语音控制台发的 API Key，不进仓库）
VOLC_API_KEY=... OUT_DIR=voices/wanwanxiaohe tools/make-voices.sh
VOLC_API_KEY=... OUT_DIR=voices/xiaohe2 VOLC_VOICE=zh_female_xiaohe_uranus_bigtts VOLC_RESOURCE_ID=seed-tts-2.0 tools/make-voices.sh
# edge-tts 音色
OUT_DIR=voices/hsiaochen VOICE=zh-TW-HsiaoChenNeural tools/make-voices.sh
```

## 打成语音包

写进设备 `voices` 分区的是语音包（ADR-0003），由脚本从一个音色目录打出：

```bash
tools/make_voice_pack.py voices/wanwanxiaohe wanwanxiaohe build/wanwanxiaohe.bin
```

包不入库，App 构建时现打。格式见 `firmware/main/agent_voice_pack.h`，两边各有测试：`tools/test-voice-pack.sh`（固件解析）与 `python3 tools/test_make_voice_pack.py`（打包布局）。

豆包语音 2.0 的合成结果每次略有差异，1.0 和 edge-tts 基本稳定。想试听就转成 WAV：

```bash
ffmpeg -f s16le -ar 24000 -ac 2 -i voices/hsiaochen/done.pcm done.wav
```

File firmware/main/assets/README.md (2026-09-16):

# 氛围小助手语音资产

PCM 文件为 24 kHz、16-bit、双声道、小端序，由 `tools/make-voices.sh` 一键生成。它们只在以下状态切换时播放一次：

- `input_required.pcm`：需要你确认
- `done.pcm`：任务完成
- `failed.pcm`：任务遇到问题
- `focus_done.pcm`：钟声，然后“专注结束，休息一下”
- `break_done.pcm`：钟声，然后“休息结束”

工作中和空闲状态不播放语音，避免持续打扰用户。番茄钟的开始、暂停、继续、放弃也不出声。

## 音色

当前音色是火山引擎豆包语音的「湾湾小何」（`zh_female_wanwanxiaohe_moon_bigtts`，1.0 模型，台湾口音，2026-09-16 更换），由 `tools/volc-tts.py` 走 V3 HTTP 接口合成。用户要的是小智音箱那种台湾女声，这个音色就是同一个。它归「语音合成 1.0」字符版，`X-Api-Resource-Id` 用 `seed-tts-1.0`；2.0 里的「小何 2.0」是普通话音色，不是替代品。

API Key 是豆包语音控制台（default 项目）自己发的那种，IAM 的 API Key 和 Access Key 都不能直接用于合成接口；密钥存在用户的凭据目录，不进仓库。之前用过 macOS 系统语音 `Tingting`（拼接式发音生硬）和微软 edge-tts 的 `zh-TW-HsiaoYuNeural`（不设 VOLC_API_KEY 时脚本仍会回落到它）。合成只在生成素材时发生，固件运行时不依赖任何在线服务。五种候选音色的完整成品都归档在仓库根目录 `voices/`，见那里的 README。

## 生成步骤

```bash
VOLC_API_KEY=... tools/make-voices.sh      # 豆包语音，默认湾湾小何
tools/make-voices.sh                       # 不给密钥则用 edge-tts HsiaoYu
```

脚本对每一句单独归一化到 -1 dBFS 峰值：不同句子的合成峰值相差可达 1.7 dB，统一增益要么让一句削波、要么让另一句太轻。单声道转双声道会损失 3 dB，脚本量的是转换之后的峰值。要再提高响度应优先调整 `agent_audio.c` 的 codec 音量，不要把素材推到满量程，那会让功放削波。

番茄钟的两个文件由 `tools/make-pomodoro-audio.py` 在语音前拼上钟声。钟声由脚本加法合成，不使用任何第三方音频素材。

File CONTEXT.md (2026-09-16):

# Vibe Buddy

Vibe Buddy 把本地 AI Agent 的状态变成实体宠物的画面与声音。本文只定义领域词汇，不记录实现决定；实现边界见 [`docs/architecture.md`](docs/architecture.md)。

## Language

### 角色与组件

**Vibe Buddy**：
产品名，2026-09-15 起用，此前叫 AgentBeacon。2026-09-16 起内部名也全部跟着改：仓库 `vibe-buddy`、daemon `vibebuddyd`、Hook `vibebuddy-hook`、CLI `vibebuddy`、Vibe Buddy Protocol、bundle id `com.vibebuddy.app`、本机目录 `VibeBuddy`。
_Avoid_: AgentBeacon、beacond、beacon-hook（旧名，只在讲历史时出现）、氛围助手（那是解释，不是名字）

**氛围小助手**：
Vibe Buddy 的原创像素角色，设备上唯一的拟人化主体，英文也叫 Vibe Buddy。2026-09-15 前叫小灯灵，代码里叫 `buddy`。
_Avoid_: 小灯灵（旧名）、宠物（泛指时可用，指代本角色时不可）、Pet、Codex 宠物、助手（单独用时指 Agent，见下）

**Agent**：
被 Vibe Buddy 观测的本地 AI 助手，例如 Codex 或 Claude Code。Agent 是观测对象，不是 Vibe Buddy 的组成部分。
_Avoid_: 客户端、AI、助手；也不指 Claude Code 内部的 subagent

**Adapter**：
把某个 Agent 的事件翻译成 Vibe Buddy 领域概念的那一层，包含本机隐私过滤脚本和 daemon 内的事件映射。每个 Agent 一个 Adapter，聚合逻辑不属于 Adapter。
_Avoid_: 集成、插件、connector

**App**：
Vibe Buddy 在 Mac 上的图形界面：菜单栏图标加设置窗，负责首次引导、设置、音色与固件，并看管 daemon。它不是第二个提醒出口，Agent 的事都由氛围小助手来讲。
_Avoid_: 客户端、面板、控制台、伴侣应用

**链路**：
Mac 与设备之间的连接。链路断开时氛围小助手闭眼变灰，链路异常是 App 唯一会自己出声提醒的事。
_Avoid_: 连接、USB、串口（那是链路的一种实现）

**接入**：
某个 Agent 与 Vibe Buddy 之间的 Hook 连接及其状态：装没装、最近一次收到事件是什么时候。
_Avoid_: 集成、安装、配置

### 声音

**播报音色**：
氛围小助手说话用的那一个声音，全部五句共用，同一时刻只有一个。候选音色各自成套归档，用户在 App 里挑选并写入设备。
_Avoid_: 声音、语音（语音指那几句台词本身）、voice、TTS

**语音包**：
一个播报音色的五句成品打成的一包，写进设备里独立于程序的位置；设备没有语音包时用出厂内置的那一套。换音色就是换语音包，不换固件。
_Avoid_: 音色包、资产包、语音资产（那是仓库里的源文件）

**静音**：
设备扬声器的总开关，只在设备上长按 K2 切换：关上后播报和番茄钟的铃声都不出声，画面照常。它是设备自己的事，Mac 端不记、不显示、不代切。
_Avoid_: 免打扰、勿扰、mute、关声音

**音量**：
设备扬声器的响度档位，20 到 100，存在设备上、重启不丢；播报和番茄钟的铃共用一个。App 的滑块只是遥控，显示的永远是设备报回来的值。下限不到零：关声音只能靠静音。
_Avoid_: 声音大小、volume、音量设置（那是 App 里的一处界面，不是这个概念）

### 模式

**模式**：
氛围小助手此刻在替用户做的事，同一时刻只有一个，每个模式拥有整块画面。三个：值班、番茄钟、休闲。模式决定画面归谁，不决定语音——扬声器不分模式。
_Avoid_: 场景、页面、视图、状态（那是值班里 Agent 的词）

**值班**：
默认模式：盯着 Agent，有事叫你。任务卡、氛围小助手的表情、当日战绩都在这里。Agent 一有动静就回到值班。
_Avoid_: Agent 模式、助手模式（“助手”已被 Agent 一词避免）、工作模式（用户在番茄钟里也在工作）

**番茄钟**：
设备本地的专注计时器：专注 25 分钟、休息 5 分钟，两个阶段都由用户按键开始。它的状态只在固件里，Mac 端不参与；它不是 Activity，也不产生任务卡。
_Avoid_: 计时器、Timer、番茄、专注模式（会与专注阶段相撞）

**阶段**：
番茄钟当前所处的一段：专注或休息，各自有待开始、运行中、暂停三种运行状态。阶段结束是只消费一次的边沿，与播报同一性质。
_Avoid_: session

**休闲**：
值班时空闲够久之后氛围小助手自己去玩的模式。它由无聊度驱动而不是由用户切换；Agent 有动静、按键、链路断开都让它立刻回到值班。
_Avoid_: 娱乐模式、屏保、空闲模式（空闲是值班里的一个状态）

**无聊度**：
连续空闲的时长，按状态而非按消息累计：Agent 无事可做、番茄钟没在走、链路正常、没有按键。分三档：待命、无聊、困倦。
_Avoid_: 空闲时间（会与值班的空闲状态混）

**剧目**：
休闲模式里随机演出的一段几秒到十几秒的动画，例如巡逻、踢球、看书。
_Avoid_: 动画、小动作（那是值班空闲时的眨眼伸懒腰）

### 活动生命周期

**Session**：
一个 Agent 进程中的一次完整会话。由 Agent 提供标识，Vibe Buddy 不自行生成。
_Avoid_: 连接、会话实例

**Turn**：
从用户提交一次输入到助手停止生成之间的工作单元。Codex 以 `turn_id` 标识，Claude Code 以 `prompt_id` 标识；两者语义对齐，因此 Turn 是跨 Agent 的通用概念，不是某个 Agent 的专有词汇。
_Avoid_: 轮次、prompt、请求

**Activity**：
Vibe Buddy 正在追踪的一次工作及其当前状态，是值得单独播报的最小单位。对话式 Agent 的 Activity 由 Session 与 Turn 共同确定身份；训练任务、CI 等没有 Turn 的生产者自行提供标识。Activity 在结束或过期时消失。
_Avoid_: 任务、Job、Task（Task 专指设备上的呈现，见下）

**任务卡**：
Activity 在设备屏幕上的呈现形式，最多同时显示 3 张，最近活动的在最上。Vibe Buddy Protocol 中承载它的字段名为 `tasks`，属于 v1 的历史命名，不改变 Activity 才是领域对象这一事实。
_Avoid_: 卡片、条目、Task item

### 状态与通知

**可见状态**：
当前应当显示在设备上的那一个状态快照，由所有 Activity 聚合得出。可见状态是持续的、可去重的：相同的快照不重复下发。
_Avoid_: 当前状态、全局状态、快照

**播报**：
只应消费一次的边沿通知，对应一次短语音。播报不改变可见状态，也不参与去重；同一个 Turn 的播报不得触发第二次。
_Avoid_: 通知、提醒、语音事件

**当日战绩**：
按本地自然日累计的完成数、需要确认次数和忙碌时长。它描述的是这一天发生过什么，不是当前状态，因此只在空闲时显示，也不参与去重。
_Avoid_: 统计、metrics、历史

**需要确认**：
某个 Activity 正在等待用户回应时的状态。它在全局优先级上高于工作中，因为它回答的是"我现在最需要你做什么"。
_Avoid_: 阻塞、等待中、pending

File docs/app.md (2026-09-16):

# Vibe Buddy App

App 是 Vibe Buddy 在 Mac 上的图形界面：一个菜单栏图标加一扇设置窗。它负责首次引导、设置、播报音色与固件，并看管 daemon。它不是第二个提醒出口：Agent 的事都由盒子上的氛围小助手来讲，App 只在盒子自己没法开口的时候（链路异常）出声。本文记录 2026-09-16 的设计定案；三个难逆转的取舍另见 ADR-0003、0004、0005。

## 角色与生命周期

- **菜单栏常驻，不上 Dock。** `LSUIElement` 为真，设置窗从菜单打开。
- **看管 daemon。** `vibebuddyd` 作为 helper 打包在 App 内，App 启动时拉起它，崩溃后按 1、2、5 秒退避重启，连续三次失败就停手、弹通知，菜单第一行变成「daemon 异常 · 点击重启」。
- **退出即离线。** 退出 App 就退出 daemon，菜单项写明「退出 Vibe Buddy（盒子将离线）」。不再有独立于 App 的 daemon 生命周期。
- **取代 LaunchAgent。** 首次启动发现旧的 `com.vibebuddy.vibebuddyd` LaunchAgent，或 7331 端口已被占用，就提议卸掉旧的并接管。
- **登录时启动**用 SMAppService 注册，引导的最后一步询问，之后在「通用」页可改；系统会提示"已添加后台项目"，这是唯一会遇到的系统权限交互。

## 技术栈与仓库布局

- SwiftUI 界面，菜单栏用 AppKit 的 `NSStatusItem` 加标准 `NSMenu`；daemon 与 Hook 仍是 Rust。
- `app/` 目录放 Xcode 工程，`.xcodeproj` 直接入库，不用生成器。一个 Build Phase 跑 `cargo build --release -p vibebuddyd -p vibebuddy-hook`，把两个二进制拷进 App 包。
- 最低 macOS 14。界面第一版只做中文，字符串集中存放以便日后加英文。
- 显示名 `Vibe Buddy`，包名 `Vibe Buddy.app`，bundle id `com.vibebuddy.app`，helper 叫 `vibebuddyd`。与"显示名改、内部名不改"的约定一致。
- App 自身不做更新检查（没有 Sparkle），关于页只显示版本号。

## App 与 daemon 怎么说话

沿用本机 HTTP `127.0.0.1:7331`。新增：

- `GET /v1/status`：链路、当前模式、固件与 daemon 构建标识、当日战绩、Hook 最近一次事件时间。
- `GET /v1/status/stream`：SSE，状态一变就推。
- 写操作：写语音包、更新固件、截图、重启 daemon 自身。

配置由 daemon 持有，存在 `~/Library/Application Support/VibeBuddy/config.json`（当前音色、通知开关等），App 通过接口读写，不直接碰文件；现有环境变量保留为开发时的覆盖手段。App 自己只用 UserDefaults 存窗口位置一类的界面状态。

## 菜单栏

图标是氛围小助手的像素脸：设备已连接时正常，链路断开或 daemon 没起来时灰色闭眼。点开是标准菜单：

1. 设备状态：`已连接 · 固件 abc1234` / `未找到盒子` / `daemon 异常 · 点击重启`
2. 当前模式：值班 / 番茄钟 / 休闲
3. 当日战绩一行，只读
4. 设置…
5. 退出 Vibe Buddy（盒子将离线）

菜单里不放任务卡，盒子才是看任务的地方。

## 通知

只在链路异常时弹 macOS 通知：设备断开超过 30 秒（拔一下线不弹），或 daemon 三次重启失败。Agent 事件一律不弹，避免与盒子重复。通知权限在第一次需要弹的时候才申请，不在引导里要。

## 设置窗

五页，外观走系统设置那一套：顶部标签、分组表单、系统字体与配色。品牌只出现在引导页、关于页和菜单栏图标。

**通用**：登录时启动、链路异常通知开关。

**声音**：最上面是音量滑块（20 到 100，步进 5）：值来自盒子的状态，松手才写进盒子的 NVS，重启不丢；旁边「在盒子上试一句」让盒子用新音量播"任务完成"，Mac 上的试听与它无关。不做静音也不允许调到零，静音只在盒子上长按 K2。下面是播报音色的卡片列表，每张卡有名字、口音或来源标签、一个播放键（五句连播，约十秒，再点停止）、「使用」按钮和「已写入」标记。点「使用」后卡片上出进度条，其它卡片与设备页操作禁用；桥接时最长约三分钟，写完盒子回校验结果才标记「已写入」。写到一半拔线，分区在固件看来就是空的，自动回落内置音色，App 提示重新写入，不做断点续传。

**接入**：Codex、Claude Code 两行，各显示状态与最近一次事件时间，配「安装」「修复」「移除」。GitHub CLI 这一版不出现在界面上，CI 轮询照旧沿用已登录的 `gh`，没登录就静默没有 CI 卡。写入的是用户级 `~/.claude/settings.json` 与 `~/.codex/hooks.json`，只合并 Vibe Buddy 自己的条目，不动别人的 Hook，写前展示差异确认。写完显示「等待第一次事件…」，收到即变绿。Codex 的 `/hooks` 信任只能人做，App 只提示，但提示要能分出好坏：Codex 对改过的 hook 会静默停用直到重新信任，所以配置文件比 daemon 报的最近一次事件新时，这一行标红并直说去 Codex 输入 `/hooks`；App 自己改写 Codex 配置（包括改名迁移）时当场弹一条通知。App 不重算 Codex 的信任哈希，只看写入之后有没有收到过事件。项目级配置不碰。

**设备**：连接状态与串口名；「盒子固件 x · App 附带 y」，哈希不同就出「更新到 App 附带版本」；盒子当前画面，按「刷新」才截一张（桥接下一张要占串口几秒，不自动轮询），配「保存图片」。

**高级**：打开日志、重启 daemon、导出诊断（日志、配置、两边构建标识打成一个包）。

## 首次引导

1. 欢迎。
2. 找设备：提示插上盒子，列出找到的口，连上后让盒子眨一下眼确认。可跳过，之后菜单栏一直提示「未找到盒子」。
3. 接入 Agent：检测 Codex、Claude Code，一键写 Hook，Codex 提示去 `/hooks` 信任。可以「先不接」，不能跳过这一页。
4. 选音色：试听并写入盒子。可跳过。
5. 登录时启动。
6. 完成。

找设备放在接入之前：先让人看到盒子活了，再配别的，信心足。

## 播报音色与语音包

固件不再把五句 PCM 编进程序。分区表新增 2 MB 的 `voices` 数据分区，固件启动时从那里读；分区为空或校验不过就用出厂内置的湾湾小何，行为与今天一样。

语音包是自定义的小格式，不上文件系统：魔数、版本、音色 id、五条 `[偏移, 长度]`，后面跟五段与现有资产同格式的 PCM。包头最后写，写到一半的包等于没写。

写入走现有串口协议：Mac 分块 base64 发，固件自己写分区并校验回报，不复位、不抢串口，两种接法行为一样；桥接 115200 波特下 1.5 MB 约三分钟，原生 USB 口几秒。esptool 路径只留给固件升级。

五个语音包不入库，构建时由脚本从 `voices/*/` 打出，随 App 分发，约 7.5 MB。

设备协议要新增的事件（草案，实现时写进 `protocol.md`）：`device.identify`（眨眼）、`voice.begin` / `voice.chunk` / `voice.end`、设备回报 `voice.written` 与校验结果。

## 固件升级

App 附带与之配套的固件三件套（bootloader、分区表、app）。Release 构建要求 `firmware/build` 里有它们，缺了就构建失败并提示先构建固件；Debug 构建允许不带，设备页隐藏「更新」。

版本只比哈希：不同就显示「更新到 App 附带版本」，不判断新旧，带 `-dirty` 的照实显示。固件没有语义版本号，加一个反而要维护。

流程：确认 → daemon 断开串口 → espflash 烧录（桥接时自动 no-stub）→ 盒子重启 → 重连，进度全程可见；失败给出重试和「按住 K0 再插线」的兜底说明。升级不抹 `voices` 与 `nvs` 分区，换固件不丢音色和当日战绩。永远不自动升级。

## 设备页脚

页脚第二行标签从 `DAEMON` 改为 `APP`，值是 App 版本加构建号。链路断开时不清掉，跟着整屏变灰：断开时最有价值的信息恰恰是"上次连的是哪个版本"。

## 实现记录（2026-09-16）

- 构建用 SwiftPM 加装包脚本，不是 Xcode 工程：本机只有命令行工具，`xcodebuild` 不可用，而 `swift build` 能编 SwiftUI 与 AppKit；装了 Xcode 可直接打开 `app/Package.swift`。命令行工具也没有 XCTest 和 swift-testing，视图模型的缝用 `swift run --package-path app SelfTest` 的断言自检守着。
- 固件烧录不用 espflash：它的 ROM 写块固定 1 KB、串口对象是具体类型没法包装，过不了 UART 桥；daemon 自己实现 ROM 下载协议，块 256 字节、桥接时按线速分段，MD5 校验后硬复位。
- 语音包分块写入在桥上约 5 KB/s（1.2 MB 四分钟），比设计里估的慢一些；瓶颈是停等回执加 115200 波特，原生 USB 口快得多。
- 设备连上先收 `device.hello`，把模式、固件构建号、音色重报一遍；否则 daemon 重启后什么都不知道。
- App 把自己的 pid 放在 `VIBEBUDDY_PARENT_PID` 里传给 daemon；App 被强杀（SIGKILL）时 daemon 两秒内自己退出，不会变成孤儿占着串口和端口。SIGTERM 则由 App 接住走正常退出。
- 装包脚本做的是 ad-hoc 签名，只为让登录项与通知认得这个包的身份，不是分发用的 Developer ID 签名与公证——那仍在「明确不做」里。
- 固件三件套的偏移（0x0、0x8000、0x10000）由分区布局决定，daemon 写死，App 只传文件路径。

## 明确不做

- **静音**：只在设备上长按 K2，Mac 不记、不显示、不代切。
- 菜单里的任务卡、Agent 事件的 macOS 通知。
- 自动升级固件、App 自更新、安静时段、项目级 Hook 配置。

## 验收

实机走完：引导六步；换一次音色并听到新声音；固件更新一次且音色与战绩仍在；拔线 30 秒后收到通知、插回后图标恢复；一键写 Hook 后接入页在下一次 Agent 事件时变绿。

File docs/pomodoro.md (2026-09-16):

# 番茄钟模式

番茄钟是氛围小助手的第二个模式。第一个是值班：盯着 Agent，回答“Agent 现在怎么样”；番茄钟回答“我自己这一段专注还剩多久”。两者共用一块屏幕，所以需要模式这个概念；它们共用一只扬声器，所以语音不分模式。第三个模式是休闲，见 [`leisure.md`](leisure.md)。

## 时长

专注 25 分钟，休息 5 分钟，暂时固定。两个阶段都由用户按键开始，不自动衔接：专注结束后停在“休息待开始”（`BREAK 05:00`），按 K0 才开始计休息；休息结束后回到空闲，按 K0 才开始下一段专注。第一版曾让休息自动开始，理由是休息的意义在于被计时；实际用下来 dragon 要求改成手动——专注结束那一刻人往往还在收尾，休息从起身那一刻算才准。休息待开始时长按 K0 直接跳过休息回到空闲。

## 画面

复刻 Focus To-Do 的表盘：一圈 60 根刻度，走过的部分染成阶段色，一根更长的指针停在当前位置，倒计时放在圆心。空闲时指针停在 12 点、刻度全灰、显示 `25:00`。专注是番茄红，休息是绿色，空闲用氛围小助手的 READY 蓝。

右栏三组信息：

- 阶段与按键提示：`FOCUS` / `BREAK` / `READY`，下面是当前可用的按键。暂停时倒计时数字每半秒闪一次，并额外显示 `PAUSED`——停表的老规矩。
- 当日记录：`TODAY` 下面每完成一次专注记一格，再一行 `3 FOCUS 1H15` 写清次数与累计专注时长。只记完成的专注，放弃的不算，暂停的时间也不扣。按 Mac 端心跳带来的本地日期清零，存在 NVS 里，重启不丢；Mac 端跨夜没在跑时，要等心跳回来带着新日期才归零。值班空闲屏的战绩轮播也带这一行。
- Agent 摘要：氛围小助手的主状态与最上面那张任务卡的标题。番茄钟模式里 Agent 让出了画面，但没有让出注意力：需要确认时这一行仍然变黄，语音照常播。

阶段结束时圆环像闹钟一样响：头两秒圆环和倒计时数字左右抖动，每 0.1 秒换一边、幅度 3 像素，整圈刻度亮成下一阶段的颜色（专注结束是休息的绿，休息结束是 READY 蓝）；之后整圈在阶段色与它的半亮之间一秒一拍地脉动，像心跳而不是灰与亮的硬闪。脉动持续到用户动手为止：按 K0 开始下一阶段、长按 K0 放弃或跳过，或者按 K1 切走画面（休闲接管也算）。钟声和语音是瞬时的，静了音就再也听不见；这套画面让到点之后任何时候瞟一眼都能看出"还没按掉"。这不是番茄钟状态机的一部分：画面模块记下结束时的阶段，视图一变就停。

切回值班时，倒计时不消失：右上角有一个小徽章 `F 18:21` / `B 04:59`，暂停时同样闪烁。

失联时只灰掉 Agent 那一栏与顶部状态条。番茄钟是设备自己的事实，不因为 Mac 端失联而变得不可信，圆环保持原色。

## 按键

外壳上有 K0、K1、K2 三个键（另有 RST）。三个键各管一件事，与当前模式无关：

| 按键 | 短按 | 长按（1 秒） |
| --- | --- | --- |
| K0 | 番茄钟：开始 / 暂停 / 继续 | 放弃当前阶段，回到空闲；休息待开始时即跳过休息 |
| K1 | 在值班与番茄钟之间切换 | 让氛围小助手现在就去休闲 |
| K2 | 打开当前来源（上报 Mac，行为不变） | 静音开关 |

每个键只有一种意思，不用记“在哪个模式里按什么”。专注途中 Agent 需要确认，按 K2 一下就能跳过去，不必先换模式。K0 开始一段专注时会自动切到番茄钟，圆环开始走就是反馈；暂停和继续不换模式，值班画面右上角的徽章会跟着闪。

短按在松开时才算数，因为只有等到松开才知道它不是一次长按的开头。K2 上报 Mac 的时机因此从按下推迟到松开，对“打开来源”没有可感知的影响。

三个键的接线都已实机确认：K0 是 BOOT 键 GPIO0（PCB 丝印写作 `B0`），K1 是 XL9555 P0.4，K2 是 XL9555 P0.3，都是低电平有效。K1 的位是 2026-09-15 第一次烧录时由固件里的候选位探针定出来的：上游固件把 P0.0、P0.1、P0.4 与 P1.1～P1.7 配成输入，固件先把其中任一位变低当作 K1，实机按下时回报 `BUTTON RAW P0=0xEF`，随后收窄成单一位并去掉探针。

## 模式切换规则

- 用户用 K1 在值班与番茄钟之间主动切换，设备记住他的选择。
- K0 开始一段专注时切到番茄钟。
- 阶段结束把番茄钟推到前面来。那一刻正是用户该看一眼的时候：知道该按键开始休息了，或者知道该按键开始下一段专注了。
- 待开始放了五分钟、暂停放了三十分钟没人动，切回值班，接着由休闲接手（见 [`leisure.md`](leisure.md)）。
- Agent 事件不抢模式。专注途中 Agent 需要确认，靠语音和右栏那一行黄字提醒；把画面切走等于替用户决定“Agent 比你的专注重要”，那不是设备该做的判断。

## 声音

专注结束和休息结束各播一次：先一段钟声，再一句中文语音。钟声是加法合成的（[`tools/make-pomodoro-audio.py`](../tools/make-pomodoro-audio.py)），专注结束是下行的“叮—咚”，休息结束是上行三音；语音是“专注结束，休息一下”和“休息结束”。钟声负责把注意力拉过来，语音负责说清楚是哪一个。

开始、暂停、继续、放弃都不出声：这些是用户自己按出来的动作，画面已经给了反馈。

长按 K2 一秒是全局静音：Agent 的播报和番茄钟的铃都不响，再长按恢复；屏幕左上角常驻 `MUTE`。静音不持久化，重启恢复有声——开会静了音忘记开回来，设备哑好几天比多响一次更糟。专注时自动免打扰、夜间自动静音暂未做。

## 状态归属

番茄钟的状态完全在固件里，`vibebuddyd` 不参与。它是设备 I/O 与确定性渲染，正是固件的职责；而且用户拿它计时的时候，Mac 端可能根本没在跑。固件只把转换以诊断行的形式发给 Mac（`POMODORO FOCUS START`、`FOCUS END`、`BREAK START`、`BREAK END`、`PAUSED`、`RESUMED`、`STOPPED`、`BREAK SKIPPED`，以及记录变化时的 `POMODORO TODAY <次> <秒>S DAY <日期>`），`vibebuddyd` 记进日志，不做别的。当日记录也留在设备上，不回传：专注一结束面板上的数字就该变，绕一圈 Mac 端只会引入延迟和不一致。

## 验证

- 状态机有主机端测试：`./tools/test-pomodoro.sh`，覆盖开始、暂停、继续、放弃、阶段结束只报一次、毫秒计数回绕。
- 画面有主机端预览：`./tools/preview-display.sh`，把固件里同一份绘制代码渲染成 PNG，烧录前先看版式；阶段结束的闹铃头三秒拼成 `pomodoro_alarm.gif`。
- 实机验收清单：按 K1 看到 `25:00` 表盘，再按 K1 回到值班；按 K0 开始，画面自动切到番茄钟、指针走动，按 K1 切回值班能看到右上角徽章；再按 K0 暂停，数字闪烁；长按 K0 回到 `25:00`；等到专注结束听到钟声加语音、画面自动切到 `BREAK 05:00` 且不走动，圆环抖两秒后整圈绿色脉动；按 K0 休息开始走动、脉动停；休息结束听到第二段钟声、回到 `READY`，圆环整圈蓝色脉动到按 K0 为止；长按 K2 静音后重复一遍，只靠画面也能察觉到点；专注途中让 Agent 请求确认，右栏那行变黄且语音照常，按 K2 能打开来源。

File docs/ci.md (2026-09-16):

# CI 状态回流

## 为什么值得做

CI 出结果的时候，用户通常早就切走做别的事了。笔记本屏幕上的那个页签要主动去看才有用，而这个盒子一直在视野边缘——这是设备真正比屏幕有用的场景之一。

CI 与 Agent 共用同一套任务卡、同一只氛围小助手和同一组播报，只是来源不同：Agent 由 Hook 推送，CI 由 `vibebuddyd` 主动轮询 GitHub Actions。

## 映射

| GitHub Actions run | Vibe Buddy 状态 |
| --- | --- |
| `queued` / `in_progress` | 工作中，标题 `CI:<仓库名>` |
| `completed` + `success` | 完成，播放一次“任务完成” |
| `completed` + `failure` / `timed_out` / 其他 | 失败，播放一次“任务遇到问题” |
| `completed` + `cancelled` / `skipped` / `neutral` | 安静收起卡片，不播报 |

每个仓库最多占一张卡，取该仓库最近一次 run。轮询间隔 30 秒；CI 以分钟计，30 秒既够用，也不至于把 API 配额花在这上面。

**只报告亲眼见过在跑的 run。** 某次 run 已经结束、而 `vibebuddyd` 从没见过它处于运行中，就什么都不做。没有这条规则，daemon 每次重启都会把每个仓库最近一次历史结果重新宣告一遍，包括昨天那次失败。代价是：一次 run 若在两次轮询之间开始并结束，它不会被播报。

## 关注哪些仓库

没有配置文件，也不需要你列清单。`vibebuddyd` 关注的就是 **Agent 最近一小时工作过的 GitHub 仓库**：每个 Hook 都带 `cwd`，适配器为了生成任务卡标题本来就要把它解析成 git 项目根，CI 复用同一个事实，再从 `.git/config` 的 `origin` 远端读出 `owner/repo`。

这个推导只读本地文件，不调用 git 也不调用网络。子目录和 worktree 都会归到主仓库。没有 GitHub 远端的项目、以及一小时内没有 Agent 活动的项目，都不会被轮询；没有任何项目在跟踪时，整个功能不发一次请求。

一小时这个窗口对应的是「我正在这个仓库上干活，所以我关心它的 CI」。CI 通常在推送后几分钟内出结果，而推送前总会有 Agent 活动。

`VIBEBUDDY_CI_REPOS`（逗号分隔）可以覆盖自动推导，用于观察本机没有检出的仓库。

## `gh` 的位置

`vibebuddyd` 通过 `gh run list` 读取状态，沿用你已有的 GitHub 登录，不自己保存 token。

launchd 启动的进程只有一个很短的 `PATH`（`/usr/bin:/bin:/usr/sbin:/sbin`），`gh` 通常不在里面，所以 `vibebuddyd` 会依次尝试 `~/bin`、`/opt/homebrew/bin`、`/usr/local/bin`、`/usr/bin`，都找不到才回退到 `PATH`。装在别处可以用 `VIBEBUDDY_GH` 指定绝对路径。不需要改 plist。

## 边界

只请求 run 的 `databaseId`、`status` 和 `conclusion`。不读取日志、不读取 diff、不读取 commit message；设备上只出现仓库名和状态。

一个仓库连续读取失败时只记录第一次，恢复后记录一次恢复。每 30 秒一条告警一天就是几千行，会把真正有用的日志淹掉。

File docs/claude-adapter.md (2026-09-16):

# Claude Code 实时适配器

## 能力边界

Claude Code 的公开生命周期 Hook 提供了 Vibe Buddy 需要的全部信息，因此适配方式与 Codex 一致：只用官方 Hook，不抓取 UI，不解析 transcript。

| Claude Code Hook | Vibe Buddy 状态 |
| --- | --- |
| `UserPromptSubmit` | 工作中 |
| `PermissionRequest` | 需要确认 |
| `PostToolUse` | 恢复工作中 |
| `SubagentStart` | 工作中，子 agent 独立成卡 |
| `SubagentStop` | 该子 agent 完成 |
| `Stop`（回复正在等待用户回答） | 需要确认 |
| `Stop`（其他回复） | 完成 |
| `StopFailure` | 空闲，标题为 `STOPPED`，不误报成功 |
| `SessionEnd` | 空闲 |

判断助手是否在等待回答的规则与 Codex 共用 [`tools/hook_filter.py`](../tools/hook_filter.py)，理由见 [ADR-0002](adr/0002-both-adapters-share-the-waiting-heuristic.md)。权限类等待不经过该规则，`PermissionRequest` 是显式事件。

## 活动身份

Claude Code 的 `prompt_id` 与 Codex 的 `turn_id` 语义对齐，都标识一个 Turn。

需要注意的是**后台 agent 共享父会话的 `session_id` 与 `prompt_id`**：2026-09-14 的实测显示，子 agent 触发的 `SubagentStart`、`SubagentStop` 及其内部的工具事件，这两个字段都与父会话相同，只有 `agent_id` 不同。因此活动身份必须是 `session_id + prompt_id + agent_id`，否则并行的子 agent 会互相覆盖。

## 与 Codex 并存

两个 Adapter 写入同一个聚合器，因为设备只有一块屏幕和一只氛围小助手。任务卡标题带 Agent 前缀：Codex 为 `CX:`，Claude Code 为 `CC:`。两个 Agent 常常在同一个目录下工作，没有前缀就无法区分该切回哪个窗口。

前缀只能使用固件字体支持的字符：`A-Z`、`0-9` 以及 `-.:/!?>` 等少数符号。固件按单字节渲染，非 ASCII 分隔符会被拆成两个未知字形。

标题取自 git 项目根而非工作目录：直接用工作目录会把 `repo/tools` 显示成 `TOOLS`，把 worktree 显示成分支目录名。worktree 的 `.git` 是指回主仓库的文件，因此两种情况都能还原成同一个项目名。

## K2 导航

Claude Code 虽然可以运行在终端里，但 K2 的用户目标是 Claude App 中拥有该 Activity 的 Code 会话，不是承载 CLI 的 terminal。

Hook 给的 `session_id` 是 **CLI 的**会话 id，它和桌面会话 id 是两个不同的 UUID，而且不是一对一：worktree 被删除后会话迁回主仓库、fork，以及每一次 `claude://resume` 导入，都会让同一个 CLI 会话多出一条桌面记录。所以 `vibebuddyd` 先查 Claude App 自己的会话索引，把 CLI 会话解析成桌面会话再打开：

```text
~/Library/Application Support/Claude/claude-code-sessions/<账号>/<组织>/local_*.json
  { "sessionId": "local_…", "cliSessionId": "…", "cwd": "…", "isArchived": … }
```

按 `cliSessionId` 取未归档的记录；有多条时用 Hook 报的 `cwd` 选中真身——那是 CLI 进程实际待的目录，影子记录的 `cwd` 停在别处。解析命中后用：

```text
claude://code/continue?session=<桌面会话 id>
```

这条链接按桌面会话 id 精确跳转，不读磁盘上的 transcript。只有解析不到（会话跑在终端里，Claude App 中没有对应窗口）时才退回 `claude://resume?session=<CLI session_id>`，此时导入正是想要的行为。

2026-09-15 已用本机 Claude 1.52386.6 验证：`code/continue` 使目标会话的 `lastFocusedAt` 前移，且不产生任何导入日志。

`claude://resume` 不能单独承担 K2：它按 CLI session id 去磁盘认领 transcript，同一个 id 在多个项目目录下各有一份时只能挑一个。2026-09-14 到 15 之间 K2 就一直打开一个内容停在前一天的影子会话，并且每按一次都把整份 5.4 MB transcript 重新导入一遍。

## 隐私边界

Hook 的原始载荷含 `prompt`、`tool_input`、`tool_response`、`transcript_path`、`session_title` 和 `last_assistant_message`。[`tools/claude-hook.py`](../tools/claude-hook.py) 在发送 HTTP 前只保留：

- `session_id`
- `prompt_id`
- `hook_event_name`
- `cwd`
- `agent_id`
- `agent_type`

当且仅当主会话的 `Stop` 被本机规则判定为等待回答时，额外加入派生字段 `response_kind`。子 agent 的最后一段是写给父会话的报告，不是向用户提问，因此 `SubagentStop` 不做该判定。

它只请求 `http://127.0.0.1:7331/v1/claude-hooks`，超时 0.5 秒；daemon 未运行或载荷无效时静默退出 0。

## 安装

在 `~/.claude/settings.json`（对所有项目生效）或项目的 `.claude/settings.json` 中，为上表的八个事件配置：

```json
{
  "hooks": {
    "Stop": [
      {
        "hooks": [
          {
            "type": "command",
            "command": "/usr/bin/python3 /Users/dragon/workspace/vibe-buddy/tools/claude-hook.py",
            "timeout": 2
          }
        ]
      }
    ]
  }
}
```

Hook 保持同步执行，不使用 `async`。异步会让事件乱序到达，而活动模型依赖顺序：迟到的 `PostToolUse` 会让已经结束的 Turn 复活。脚本本身 0.5 秒超时且失败静默，正常情况下往返不足 10 毫秒。`SessionEnd` 的所有 Hook 共享 1.5 秒预算，0.5 秒的上限在其中是安全的。

## vibebuddy-hook

2026-09-16 起 Hook 由 Rust 二进制 `vibebuddy-hook claude` 处理（源码在 `hook/`），它的前身 `tools/claude-hook.py` 已退役，测试用例逐条搬了过去。App 把它复制到 `~/Library/Application Support/VibeBuddy/bin/vibebuddy-hook`，配置里的命令写作 `"<那个路径>" claude`；手工配置时也用这个路径，别指向 App 包内，App 挪位置会断（ADR-0005）。

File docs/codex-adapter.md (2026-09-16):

# Codex 实时适配器

## 能力边界

Codex 内置宠物的素材、动画状态机和任务卡片渲染没有公开为宠物 API，不能可靠地逐帧镜像到外部设备。可依赖的公开接口是 Codex 生命周期 Hook。

Vibe Buddy 使用以下映射：

| Codex Hook | Vibe Buddy 状态 |
| --- | --- |
| `UserPromptSubmit` | 工作中 |
| `PermissionRequest` | 需要确认 |
| `PostToolUse` | 恢复工作中 |
| `Stop`（回复正在等待用户回答） | 需要确认 |
| `Stop`（其他回复） | 完成 |
| `Interrupt` | 空闲，标题为 `INTERRUPTED`，不误报成功 |
| `SessionEnd` | 空闲 |

多会话由 `vibebuddyd` 聚合：任务卡按最近活动排序，最多 3 张；需要确认的会话优先控制宠物表情。活动身份由 `session_id` 与 `turn_id` 共同确定。每个已跟踪、且不等待用户回答的 turn，其 `Stop` 都会产生一次完成通知，即使画面仍需显示其他工作中的任务；同一 turn 的重复 `Stop` 不会重复播报。等待回答的 turn 保持为需要确认，用户提交下一条消息时再切回工作中。其他任务造成卡片刷新时，画面仍显示需要确认，但不会重复播放同一条输入提醒。

Codex 被强制结束时不会发送 `SessionEnd`，因此活动还必须能自行过期。`vibebuddyd` 每 60 秒扫描一次：工作中超过 30 分钟没有任何 Hook 事件即视为进程已消失，需要确认则保留 4 小时，以免用户离开期间丢失提醒。清空最后一个活动时发送标题为 `TIMED OUT` 的 `agent.idle`，不播放语音。

实机结论（2026-09-14）：临时把时限缩短到秒级后，被遗弃的工作中活动在超时后由后台扫描清除，设备回报 `TITLE TIMED OUT` 与 `DISPLAY STATE READY`，没有 `AUDIO QUEUED`；等待确认的活动跨过工作中时限的五次扫描仍然保留，直到超过自身时限才释放。固件未修改，也未重新烧录。

Codex Hook 没有直接提供“这条助手回复是否要求用户回答”的结构化字段。`Stop` 会提供 `last_assistant_message`，隐私过滤脚本仅在本机检查最后一段是否包含明确问题或回复指令，然后生成 `response_kind: input_required`。这是保守的文本规则，不是对回复正文做远端语义分析。

## 隐私边界

Hook 的原始 JSON 可能含 prompt、transcript 路径、工具输入和工具输出。`tools/codex-hook.py` 在发送 HTTP 前只保留：

- `session_id`
- `turn_id`
- `thread_id`（K2 导航目标；顶层会话等于 `session_id`，子 Agent 映射到拥有它的父会话）
- `hook_event_name`
- `cwd`

当且仅当 `Stop` 被本机规则判定为等待回答时，脚本还会加入派生字段 `response_kind`。`last_assistant_message` 本身不会发送给 daemon。

它只请求 `http://127.0.0.1:7331/v1/codex-hooks`，超时为 0.5 秒；daemon 未运行、载荷无效或连接失败时静默退出 0，不阻塞 Codex。不要改成直接 `curl --data-binary @-`，否则敏感字段会越过适配器边界。

## 安装与信任

用户级 `~/.codex/hooks.json` 为上述六个事件调用：

```text
/usr/bin/python3 /Users/dragon/workspace/vibe-buddy/tools/codex-hook.py
```

Hook 配置新增或变更后，Codex 会按精确定义哈希要求重新审查。打开 `/hooks`，核对脚本路径与六个事件后再信任；不要绕过信任机制。新会话或重新加载后的 Codex 才会使用新配置。

Codex 的子 Agent 有自己的生命周期 `session_id`，但这个内部线程不一定能被桌面端 deeplink 打开。Hook 脚本只读取 transcript 第一行的 `session_meta`，在本机把 `source.subagent.thread_spawn.parent_thread_id` 派生为 `thread_id`；正文和 transcript 路径都不会发给 `vibebuddyd`。活动去重仍使用子 Agent 的 `session_id + turn_id`，只有 K2 导航使用父线程，不能混用这两个身份。

## 后台运行

## 后台会话

Codex 会为自己的后台会话触发同一套 Hook，典型的是每个回合结束后生成 ambient suggestions 的那次运行：它没有工作目录，`~/.codex/state_5.sqlite` 的 `threads` 表里也没有它的 id。2026-09-16 实测它紧跟在一个真回合之后结束，于是设备连播两次"任务完成"，K2 又把它当作最近播报的那件事，打开 `codex://threads/<id>` 得到一个空白会话。

`vibebuddyd` 因此在入口处过滤：没有可用工作目录、且线程表里查不到的 Codex 会话一律忽略（记一行 info），不出卡片、不播报、不做 K2 落点。两个条件缺一不可——刚建立的真会话可能还没来得及写进线程表，但它有工作目录。K2 打开前还会再核对一次线程存在，不存在就跳到下一个候选。`tools/codex-hook.py` 另在 `~/Library/Logs/VibeBuddy/codex-hooks.log` 留一行不含 prompt 的诊断记录（事件名、会话与线程 id、目录、transcript 有无），下次再冒出来路不明的会话时用它看 Hook 到底收到了什么。

`vibebuddyd` 的 release binary 由 `~/Library/LaunchAgents/com.vibebuddy.vibebuddyd.plist` 在登录后自动启动，并在异常退出后重启。日志写入 `~/Library/Logs/VibeBuddy/vibebuddyd.log`。USB 设备暂时不存在时进程保持运行并定期重新发现，Hook 不需要感知拔插。

更新 daemon 后执行 `cargo build --release -p vibebuddyd`，再用 `launchctl kickstart -k gui/502/com.vibebuddy.vibebuddyd` 重启服务。烧录固件前先停止该服务，避免它占用串口。

## 为什么不抓 UI 或 transcript

- UI 像素和可访问性树不是生命周期协议，版本更新会改变。
- Codex 官方说明 transcript 格式不是 Hook 的稳定接口。
- Hook 直接给出语义事件，数据更少，延迟更低，也更容易测试。

未来若 Codex App Server 提供可附着的稳定桌面会话流，可增加第二种适配器以区分 `systemError`、等待审批和等待输入；当前桌面进程使用 stdio 子进程，不能假定外部 daemon 可以附着。

## vibebuddy-hook

2026-09-16 起 Hook 由 Rust 二进制 `vibebuddy-hook codex` 处理（源码在 `hook/`），它的前身 `tools/codex-hook.py` 已退役，测试用例逐条搬了过去。App 把它复制到 `~/Library/Application Support/VibeBuddy/bin/vibebuddy-hook`，配置里的命令写作 `"<那个路径>" codex`；手工配置时也用这个路径，别指向 App 包内，App 挪位置会断（ADR-0005）。

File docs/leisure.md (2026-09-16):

# 休闲模式

氛围小助手有三个模式，每个名字说的都是它此刻在替你做什么：**值班**盯着 Agent，有事叫你；**番茄钟**给你计时；**休闲**是值班时没事干够久了，自己去玩。值班和番茄钟之间由 K1 切换；休闲不用切，它自己来，也自己走。

## 无聊度

休闲不是一个开关，是一个很小的情绪模型：空闲时间越长越无聊，一有事就清零。行为按档位来：

| 空闲时长 | 档位 | 行为 |
| --- | --- | --- |
| 0 到 5 分钟 | 待命 | 值班画面里现有的呼吸、眨眼、轮播战绩 |
| 5 到 30 分钟 | 无聊 | 进入休闲模式；每 20 到 40 秒随机演一段小剧目，其余时间站着呼吸 |
| 30 分钟以上 | 困倦 | 以睡觉为主，画面整体转暗，隔两到五分钟说一段梦话或被自己吓醒一次 |
| 夜里 23 点到早上 7 点，空闲 90 分钟以上 | 熄灯 | 关掉背光，屏幕全黑 |

**空闲按状态算，不按消息算。** vibebuddyd 去重，一个任务跑二十分钟设备可能一条消息都收不到，但它明明在工作。所以只有同时满足这些条件才累计空闲：氛围小助手主状态是空闲且没有任务卡、番茄钟没在走、链路没断、最近没有按键。番茄钟待开始或暂停不算在走。待开始的一屏静止的 `25:00` 和值班空闲一样无聊，五分钟就切回值班、接着进休闲；暂停的是用户有意停在那里的，放了三十分钟没人动才当人已经走了。第一版两者都等三十分钟，实际用下来 dragon 在待开始的番茄钟前等不到精灵出来玩，改成现在这样。

**有事立刻回来。** Agent 任何一条状态消息、任何一个按键，都把无聊度清零并回到值班。按键是唤醒并执行，不是只唤醒：休闲没有遮住任何需要先看一眼再决定的东西，K2 要按两下才能打开来源只会显得设备迟钝。K1 短按从休闲直接去番茄钟；K0 从休闲直接开始专注。

**失联时不休闲。** 会动的画面看上去像还活着，正好与 `NO LINK` 相反。

**休闲不出声。** 语音在这台设备上是通知；一台桌上无缘无故哼歌的设备是骚扰，不是可爱。

**休闲不改变一眼可读的状态语义。** 顶部状态条保持值班时的空闲蓝，页脚照旧，睡着的精灵就等于“没有事等你”。

## 小剧目

无聊档随机演，不连着演同一出。全部用现有的方块、线条和字模画，8 fps。

| 剧目 | 内容 |
| --- | --- |
| 巡逻 | 走到右边，停下看你一眼，走到左边，再走回来。脚交替抬起 |
| 踢球 | 球从左边滚到脚边，一脚踢开，弹一下又滚回来，再一脚踢出画面。球始终在身体左侧，不穿过身体 |
| 看书 | 举着一本书一行行扫，隔五秒翻一页，中间被剧情吓一跳 |
| 数星星 | 夜色里几颗星闪，仰头数到七，越数越慢，数着数着睡着了 |
| 躲猫猫 | 溜到屏幕右边缘外只剩一只手在晃，探出半个身子看一眼，缩回去，最后走回来 |
| 被自己吓醒 | 睡着，突然一个感叹号跳起来，左右张望，打个哈欠，接着睡 |
| 梦话 | 睡着了，头顶冒出一串泡泡，泡泡里轮播今天的战绩 |

困倦档的底色是睡觉：闭眼、慢呼吸、一个飘起来的 `Z`，整个画面每个通道减半变暗。

## 昼夜与战绩

心跳里捎着 Mac 端的本地小时数（设备没有时钟，也不该为了这个去连 Wi-Fi）。夜里无聊档多演数星星和梦话、少巡逻踢球；不知道几点就当白天，宁可亮着也不要在下午关灯。

当日战绩里的完成数决定它的状态：今天一件没做，踢球的权重翻倍，无聊地踢石子；做了五件以上，累得梦多，困倦时不再被自己吓醒。梦话泡泡里念的就是战绩本身。

## K1 长按

长按 K1 一秒，氛围小助手立刻去休闲。这是给演示和验收用的：不必等五分钟。

## 实现

- 导演在 [`agent_leisure.c`](../firmware/main/agent_leisure.c)：无聊度、档位、剧目抽取、昼夜、战绩权重、熄灯判定，纯 C，不碰硬件。主机测试 `./tools/test-leisure.sh` 覆盖档位切换、活动清零、不连演、困倦只睡觉、熄灯只在夜里且有事即亮、计数回绕。
- 剧目绘制在 `agent_display.c`，氛围小助手参数化成可以指定位置、视线、眼睛、嘴、手臂、脚的姿势。`./tools/preview-display.sh` 把每个剧目渲染成 GIF，烧录前先看。
- 实机验收用时间压缩固件：`idf.py -B firmware/build-fast -DTIME_SCALE=60 build` 把五分钟压成五秒（番茄钟也同比压缩），几分钟内走完无聊、困倦、熄灯、被唤醒；`BUILD_DIR=firmware/build-fast tools/flash-bridge.sh <串口> partition app` 烧它。验收完再烧正式固件。
- 设备回报的诊断行：`MODE DUTY` / `POMODORO` / `LEISURE`，`LEISURE ALERT` / `BORED` / `SLEEPY`，`LEISURE SKIT <名>`，`LEISURE LIGHTS OUT` / `ON`，`CLOCK HOUR <n>`。

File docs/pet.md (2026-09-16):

# 氛围小助手：Vibe Buddy 的实体宠物

## 产品定义

氛围小助手不是 Codex 宠物的复制品，而是 Vibe Buddy 的原创像素角色。Codex、其他本地 Agent、训练任务和 CI 都可以驱动同一只宠物。角色动画、表情和声音在盒子上运行；Mac 只发送稀疏的状态事件。

## 状态语言

| 状态 | 画面 | 语音 |
| --- | --- | --- |
| 空闲 | 呼吸、眨眼 | 无 |
| 工作中 | 浮动、`>` 与循环点阵 | 无 |
| 需要确认 | `!?`、橙色强调 | “需要你确认”一次 |
| 完成 | 开心、跳动、绿色 | “任务完成”一次 |
| 失败/阻塞 | X 眼、下沉、红色 | “任务遇到问题”一次 |
| 失联 | 闭眼、画面转灰、`NO LINK` | 无 |

语音是注意力补充，不是持续状态通道；因此工作中和空闲保持安静。长按 K2 一秒可以把所有语音静掉（含番茄钟的铃），屏幕左上角显示 `MUTE`，再长按恢复；重启后恢复有声。

失联与失败不同：失败是任务的结果，失联是氛围小助手自己不知道结果。它必须能表达“我不知道”，否则在 daemon 崩溃或 USB 断开后，它会继续用鲜艳的颜色宣称一个早已过时的状态。失联不播报语音，因为拔线通常是用户自己的动作，而真正断线时用户多半不在旁边。

## 空闲屏

空闲是出现频率最高的一屏，因此它不能只有一句固定的话。氛围小助手在空闲时做两件事：

- **轮播当日战绩**：完成了几件、被要求确认了几次、累计忙了多久，每 3 秒换一行。
- **偶尔做个小动作**：每 20 秒左右轮流打盹（闭眼加一个飘起来的 `Z`）、左顾右盼、伸个懒腰。

小动作不是装饰。一台一直亮着、一直是同一帧的设备看上去更像卡住了而不是在待命；氛围小助手得先证明自己还醒着，`NO LINK` 才有意义。反过来，失联时不轮播也不做小动作：会动的画面看上去像还活着，正好与它要表达的意思相反。

## 页脚：构建标识

页脚常驻两行，分别是本机固件和心跳捎来的 Mac 端，格式是 `git describe` 加编译时刻：

```text
FW     9b642af 2026-09-14 17:41
APP    9b642af 2026-09-14 17:43
```

第二行标签原来叫 `DAEMON`；App 把 daemon 打包在身上之后两者是同一个构建，2026-09-16 起改叫 `APP`。链路断开时这两行不清掉，跟着整屏变灰：断开时最有价值的信息恰恰是"上次连的是哪个版本"。

用构建标识而不是语义版本号：两边都写着 `0.1.0`，却可以相差好几天，看不出任何问题。

**只显示，不判断。** 固件要插 USB、停 daemon 才能烧，daemon 改一行源码就重启，两边大部分时间本来就不在同一个 commit 上；把「不一致」当成告警，几天之内就会被彻底无视。真正会出事的是协议能力不匹配——固件多了一个要求而 Mac 端还没有满足它的那一半——那不是 commit 能回答的问题。

信息本身已经够用了：看到 `NO LINK` 时低头看一眼 `APP` 那行是三天前的，诊断就结束了。两行左对齐到同一列，因为逐字比对靠的是对齐，不是颜色。Mac 端太旧、根本不发这个字段时显示 `?`，这本身就是答案。

## 番茄钟徽章

值班不是氛围小助手唯一的模式：K1 可以切到番茄钟（见 [`pomodoro.md`](pomodoro.md)），值班空闲够久它会自己去休闲（见 [`leisure.md`](leisure.md)）。番茄钟在走而用户切回值班时，右上角有一个小徽章 `F 18:21`（专注）或 `B 04:59`（休息），暂停时闪烁。它只占一行小字，不改变氛围小助手的任何表情。

## 多任务卡片

- 最多显示 3 张活动任务卡，最近活动的任务在最上。
- 每张卡右下角显示它在当前状态里待了多久，秒、分、小时逐级收敛成三格字宽。等待确认时这个数字与状态同色点亮，其余情况灰显——这一栏回答的正是「它等了我多久」。
- 卡片顺序表达时间；氛围小助手的全局表情表达最需要用户处理的状态。
- 全局优先级为“需要确认 > 工作中”。因此旧任务等待确认时，即使上方出现了更新的工作任务，氛围小助手仍显示需要确认。
- 卡片第一行是会话名，第二行是状态、项目名和时长。同一个项目下同时跑几件事时，项目名分不开它们；会话名是 Agent 自己起的：Claude App 为每个会话自动生成的标题，Codex 里用户给线程起的名字，其次是线程记录的分支，再其次是工作目录所在的分支。都没有才退回项目名。仍然不读 prompt 或 transcript：这些名字本来就显示在两个 App 的侧栏里。Codex 线程表里的 `title` 列是原始首条消息，不用。
- 设备字库只有大写字母和数字。会话名滤掉画不出的字符后剩不到三个字母数字（典型是中文标题）就当不可用，退回下一个来源。

这个拆分比简单照搬桌面 UI 更适合小屏：卡片回答“有哪些任务”，宠物回答“我现在最需要你注意什么”。

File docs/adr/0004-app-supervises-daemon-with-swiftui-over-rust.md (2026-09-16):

---
status: accepted
---

# App 看管 daemon：SwiftUI 界面加 Rust helper

Mac 端此前只有 LaunchAgent 常驻的 `vibebuddyd`，配置靠环境变量，接入靠手改 JSON。我们决定做一个原生 SwiftUI 菜单栏 App，把 `vibebuddyd` 作为 helper 打包在里面并由 App 拉起、重启、随 App 退出；LaunchAgent 退役。daemon 与 Hook 仍是 Rust，两者通过本机 HTTP 加 SSE 通信。

## 被拒绝的方案

保留 LaunchAgent、App 只是设置窗：两个生命周期，升级要换两处二进制，崩溃重启与登录启动各管各的。Tauri：Rust 复用多，但菜单栏、Login Item、设置窗外观都要绕，与"像系统自带的那样"相悖。

## 后果

仓库多一门 Swift。原定 Xcode 工程入库，2026-09-16 实施时改为 SwiftPM 包（`app/Package.swift`）加装包脚本：本机只有命令行工具，`xcodebuild` 不可用，而 `swift build` 能编 SwiftUI 与 AppKit；装了 Xcode 可直接打开 Package.swift，决定本身（原生 SwiftUI 加 Rust helper）不变。退出 App 盒子就离线，是有意为之。仓库名、bundle id `com.vibebuddy.app`、Application Support 路径沿用旧名。

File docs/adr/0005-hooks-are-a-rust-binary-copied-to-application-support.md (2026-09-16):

---
status: accepted
---

# Hook 改为 Rust 单二进制，复制到 Application Support

Codex 与 Claude Code 的 Hook 目前是仓库里的两个 Python 脚本，用户配置写死其绝对路径。macOS 不保证有 `python3`，App 包一旦挪动路径也会失效。我们决定把两个脚本合成一个 Rust 二进制 `vibebuddy-hook`（隐私过滤规则照搬，测试沿用），App 启动时复制到 `~/Library/Application Support/VibeBuddy/bin/`，Hook 配置指向那里。

## 被拒绝的方案

配置直接引用 App 包内的脚本或二进制：用户把 App 从下载目录拖进应用程序文件夹后 Hook 就断了，而 Hook 的失败是静默的。

## 后果

Hook 的行为变化要同时改 Rust 与文档；Python 脚本在 App 接管后退役。Codex 的 `/hooks` 信任仍只能由人完成。

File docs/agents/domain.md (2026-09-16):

# 领域文档

各工程技能在探索代码库时应如何消费本仓库的领域文档。

## 探索之前先读这些

- 根目录的 **`CONTEXT.md`**；或者
- 根目录的 **`CONTEXT-MAP.md`**（若存在）：它指向每个上下文各自的 `CONTEXT.md`，把与主题相关的都读一遍。
- **`docs/adr/`**：读与你将要动的区域相关的 ADR。多上下文仓库里还要看 `src/<context>/docs/adr/` 下限定在该上下文的决定。

这些文件若不存在，**静默继续**。不要指出它们缺失，也不要一上来就建议创建。`/domain-modeling` 技能（经 `/grill-with-docs` 与 `/improve-codebase-architecture` 进入）会在术语或决定真正定下来时按需创建。

## 文件结构

单一上下文仓库（绝大多数仓库，本仓库也是）：

```
/
├── CONTEXT.md
├── docs/adr/
│   ├── 0001-claude-adapter-does-not-parse-transcript.md
│   └── 0002-both-adapters-share-the-waiting-heuristic.md
└── daemon/  firmware/  protocol/
```

多上下文仓库（根目录存在 `CONTEXT-MAP.md`）：

```
/
├── CONTEXT-MAP.md
├── docs/adr/                          ← 全系统的决定
└── src/
    ├── ordering/
    │   ├── CONTEXT.md
    │   └── docs/adr/                  ← 限定在该上下文的决定
    └── billing/
        ├── CONTEXT.md
        └── docs/adr/
```

## 用术语表的词汇

输出里提到领域概念时（issue 标题、重构提案、假设、测试名），用 `CONTEXT.md` 定义的那个词，不要滑向术语表明确回避的同义词。

需要的概念还不在术语表里，这本身是个信号：要么你在发明项目不用的语言（重新考虑），要么确实有空缺（记下来交给 `/domain-modeling`）。

## 标出与 ADR 的冲突

输出与已有 ADR 相悖时，明确指出来，不要悄悄覆盖：

> _与 ADR-0007（事件溯源的订单）相悖，但值得重开，因为……_

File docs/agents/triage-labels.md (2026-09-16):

# Triage 标签

各技能用五个规范的 triage 角色说话。本文件把这些角色映射到本仓库 issue tracker 里实际使用的标签字符串。

| mattpocock/skills 里的标签 | 本仓库的标签 | 含义 |
| --- | --- | --- |
| `needs-triage` | `needs-triage` | 维护者需要评估这个 issue |
| `needs-info` | `needs-info` | 等报告者补充信息 |
| `ready-for-agent` | `ready-for-agent`  | 规格完整，可交给无人值守的 Agent |
| `ready-for-human` | `ready-for-human`  | 需要人来实现 |
| `wontfix` | `wontfix` | 不会处理 |

技能提到某个角色时（例如「打上 AFK-ready 的 triage 标签」），用表中右列对应的字符串。

若你实际用的词汇不同，改右列即可。

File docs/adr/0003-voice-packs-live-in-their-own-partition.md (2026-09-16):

---
status: accepted
---

# 语音包放独立分区、走串口协议写入

用户要在 Mac 上挑播报音色，而五句 PCM 一直是编译进固件 app 分区的。我们决定新增一个 `voices` 数据分区存语音包，固件启动时读它、空则回落内置音色；换音色由 Mac 分块经现有串口协议发过去、固件自己写分区，不复位、不用 esptool。

## 被拒绝的方案

每种音色各编一个固件，换音色即烧固件：把固件版本和音色纠缠在一起，新增音色要重发所有固件，且换音色变成一次刷机。Mac 播放时实时传音频：违背"语音资产在固件里、番茄钟不依赖 Mac"的既有决定，桥接 115200 波特也传不动。

## 后果

分区表要改一次，老固件检出要删 `sdkconfig` 重建。写入在桥接下要三分钟，所以包头最后写，半途拔线等于没写。固件升级不得抹 `voices` 分区。

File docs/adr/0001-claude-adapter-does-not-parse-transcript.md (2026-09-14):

---
status: superseded by ADR-0002
---

# Claude Adapter 不解析 transcript，接受 `Stop` 的语义损失

Codex 的 `Stop` 提供 `last_assistant_message`，因此 Codex Adapter 能在本机判断助手是在提问还是已完成；Claude Code 的 `Stop` 只提供 `transcript_path`，要得到同样的信息必须读取会话文件。我们决定不读：Claude Adapter 把 `Stop` 一律映射为完成，"需要确认"完全依赖 `PermissionRequest` 这个显式信号。

## 与关键决定第 7 条的关系

架构第 7 条禁止解析不稳定的 transcript，其依据是 Codex 官方声明 transcript 格式不是 Hook 的稳定接口。Claude Code 的 `transcript_path` 是 Hook 载荷主动提供的字段，并无同类声明，因此第 7 条并不直接禁止这条路径。本决定不是受第 7 条约束的结果，而是独立的取舍。

## 被拒绝的方案

读取 `transcript_path` 的最后一条助手消息，复用 `codex-hook.py` 的文本规则。它能让两个 Adapter 行为一致，且解析失败可降级。拒绝的理由是它会把 issue #1 的猜测面积扩大一倍，并额外承担一份文件格式风险，而此时没有任何数据表明这种猜测是必要的。

## 后果

`PermissionRequest` 覆盖了 Claude Code 中绝大多数需要用户介入的场景，但纯对话式提问会被播报为"任务完成"。**这是静默失败**：用户以为工作结束，设备不会再次提醒。看到这个现象的人容易把它当作缺陷去"修复"，它是有意接受的代价。

由此两个 Adapter 的可靠性并不对称：Claude 侧的"需要确认"来自显式信号，比 Codex 侧的文本猜测更可靠；Claude 侧的"完成"则比 Codex 侧更容易误报。

重新评估的触发条件是实际误报造成困扰。届时应连同 `Notification` 的 `idle_prompt` 一起评估，并用真实样本检验文本规则。

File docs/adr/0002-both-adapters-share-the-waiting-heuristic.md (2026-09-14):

---
status: accepted
---

# 两个 Adapter 使用同一套等待判定

2026-09-14 的实测表明，Claude Code 的 `Stop` 事件提供 `last_assistant_message`，与 Codex 一致；`SubagentStop` 同样提供。因此 Claude Adapter 与 Codex Adapter 使用同一套本机文本规则判断助手是否在等待回答，并在此之上额外使用 `PermissionRequest` 这个显式信号。

## 为何取代 ADR-0001

ADR-0001 的前提是 Claude Code 的 `Stop` 只提供 `transcript_path`。该前提来自对官方文档缺失部分的推断，实测证明不成立。载荷里既然已有 `last_assistant_message`，就既不需要读取 transcript，也不必接受"提问被播报为完成"的静默失败。

## 后果

两个 Adapter 的可见行为一致，不存在可靠性不对称。Claude 侧的信息反而更全：权限请求有显式事件，对话式提问有文本判断。

代价是 issue #1 的文本规则从单一 Adapter 的局部问题变成两个 Adapter 的共同依赖，其误判会同时影响两条链路，重要性相应上升。

## 教训

对外部接口的事实必须实测，不能采信对文档的二手推断。文档没有写，不等于该字段不存在。

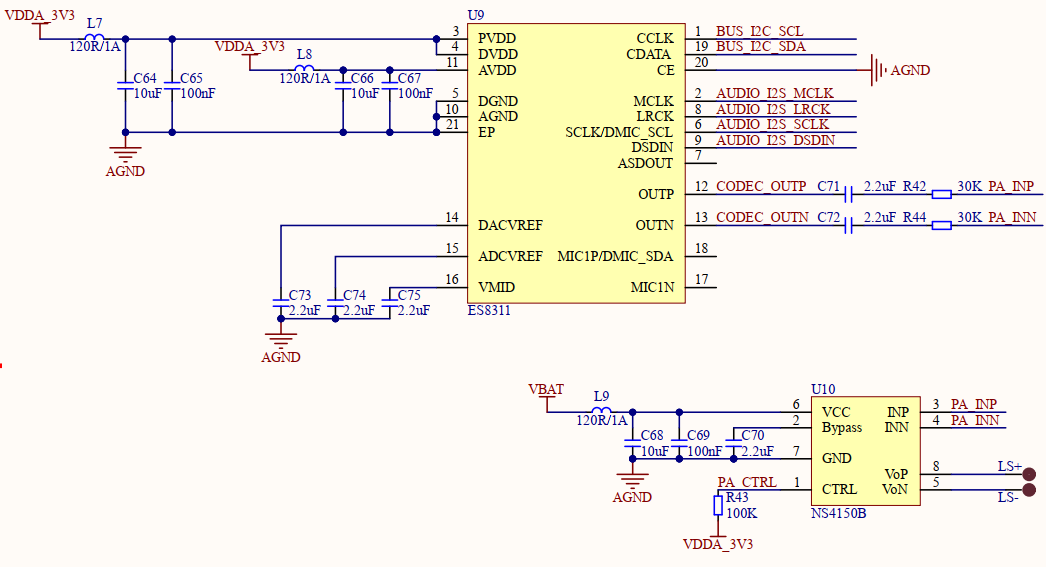
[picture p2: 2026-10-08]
docs/hardware-reference/atk-box3/z13.png

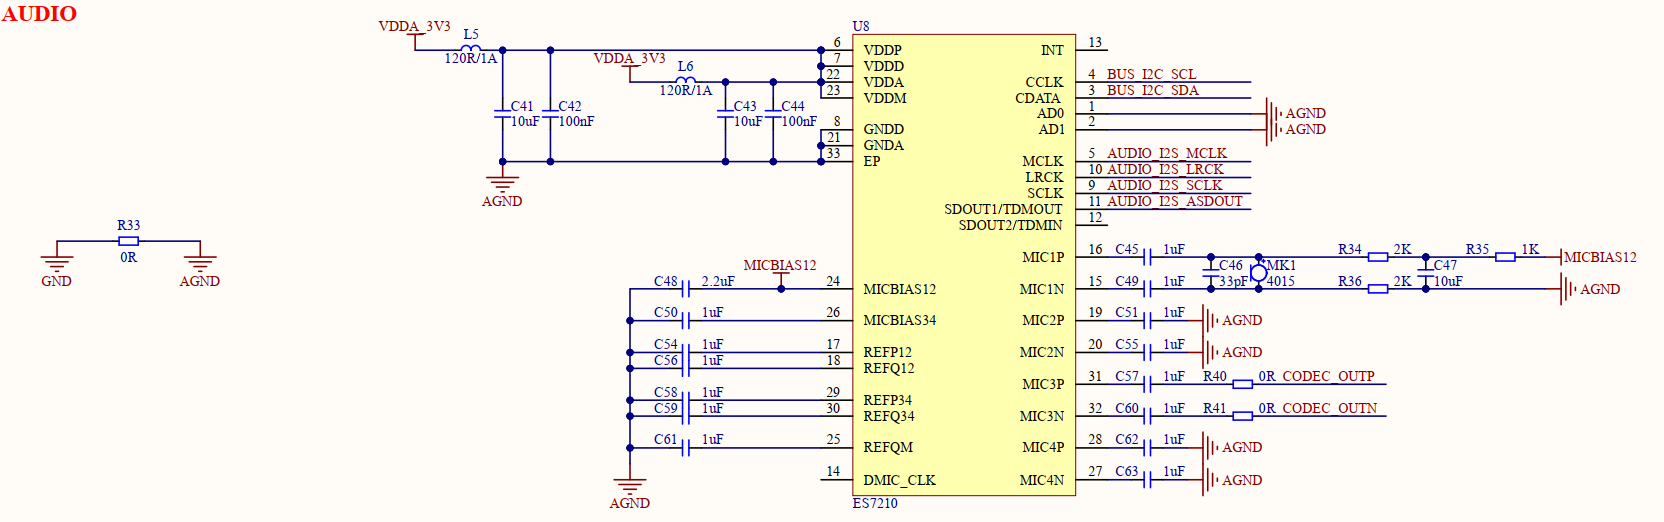
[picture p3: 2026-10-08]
docs/hardware-reference/atk-box3/ES7210.png

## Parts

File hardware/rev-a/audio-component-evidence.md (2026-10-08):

# Rev A 音频器件与逐脚证据

日期：2026-09-18。范围：ES7210 + ES8311 + NS4150B；不是老款 BOX 原装料号认定。

## 原始来源与资料优先级

- 正点原子官方 BOX3 [ES7210 原理图](https://github.com/openedv/openedv-wiki-boards-dnesp32s3b3/blob/c6f9797b64aef2666547206b4b274017d6d28a3d/example-idf/img/ES7210.png)、[播放原理图](https://github.com/openedv/openedv-wiki-boards-dnesp32s3b3/blob/c6f9797b64aef2666547206b4b274017d6d28a3d/example-idf/img/z13.png)。下列 BOX 元件值直接读图。
- [Everest ES7210 Rev22.0 May2023 原厂手册，由 Waveshare 托管](https://files.waveshare.com/wiki/common/ES7210-datasheet.pdf)，本地 `docs/hardware-reference/audio/ES7210.pdf`。
- Everest ES8311 Rev5.0 March2019、ES7210 User Guide 2018-06-07、纳芯威 NS4150B March2021 V1.1 原厂 PDF 从[固定版本镜像](https://github.com/numuly/box3-dev/tree/3f557c7cb8c0909c22e613d2f25e7e2311e55162/raw/sources)下载到 `docs/hardware-reference/audio/`。它是第三方托管的原厂文件，不是第三方文字总结。ES7210 老 User Guide 的应用图有引脚编号偏移，**引脚以 Rev22 数据表与官方 BOX3 图交叉一致值为准**。
- [纳芯威原厂 NS4150B 产品页](https://en.nsiway.com.cn/list_38/82.html)确认 MSOP8 产品。
- [Same Sky CMC-4015-40P 原厂规格书](https://www.sameskydevices.com/product/resource/cmc-4015-40p.pdf)、[CES-28266-24-L200 原厂规格书](https://www.sameskydevices.com/product/resource/ces-28266-24-l200.pdf)，均已本地归档。

## 器件选择与封装

|器件完整名称|封装或尺寸|依据与状态|
|---|---|---|
|Everest ES7210|QFN32，4×4 mm，间距0.4 mm，裸露焊盘2.8×2.8 mm|Rev22 p1订购名、p10图；EP记33，接地|
|Everest ES8311|QFN20，3×3 mm，间距0.4 mm，裸露焊盘1.7×1.7 mm|Rev5 p1、p11；EP记21，接地|
|Nsiway NS4150B|MSOP8，主体3×3 mm，间距0.65 mm，含脚总宽典型4.9 mm|p9；不要用SOP8封装替代|
|Same Sky CMC-4015-40P|驻极体模拟麦克风，直径4 mm、高1.5 mm，插针间距1.4±0.3 mm，脚直径0.4±0.1 mm|选作明确料号样机候选；不是BOX原装认定。端1正，端2负且与金属壳相连。按手册手焊，不假定可回流|
|Same Sky CES-28266-24-L200|带腔体4Ω、额定2W、引线200mm；28×26×约6mm|选作明确料号样机候选，机械图含胶与局部突出需另核；应固定到外壳，不把扬声器本体当PCB贴片件|

麦克风原厂规格：2V标准供电、最高10V、2.2kΩ负载、最大0.5mA、灵敏度-40±3dB、58dBA SNR。原厂测量电路为电源经2.2kΩ到端1、端2接地、端1经1µF输出。麦克风应按这个选定料号的电路设计，不能因为都叫4015就照搬未知麦克风偏置网络。Mouser页面存在该料号库存，但本轮未锁定采购；不假定嘉立创标准库有货。

扬声器原厂目录有 Stock Check/Buy 路径，但本轮未锁定现货与报价。候选是为原型提供完整规格，未证明符合最终低成本目标。

## ES7210 全引脚连接表

|脚|名称|Rev A 连接原则|
|---|---|---|
|1|AD0|地，地址0x40|
|2|AD1|地，地址0x40|
|3|CDATA|公共I2C SDA，上拉3.3V|
|4|CCLK|公共I2C SCL，上拉3.3V|
|5|MCLK|ESP32主时钟|
|6|VDDP|3.3V音频数字电源|
|7|VDDD|同上|
|8|GNDD|地|
|9|SCLK|公共音频BCLK|
|10|LRCK|公共音频WS|
|11|SDOUT1/TDMOUT|ESP32录音DIN|
|12|SDOUT2/TDMIN|不用则显式NC|
|13|INT|不用则显式NC|
|14|DMIC_CLK|模拟麦克风模式不用，NC|
|15|MIC1N|经1µF接麦克风地参考|
|16|MIC1P|经1µF接麦克风正端信号|
|17|REFP12|1µF到地，紧邻芯片|
|18|REFQ12|1µF到地，紧邻芯片|
|19|MIC2P|不用，经1µF接地，软件关闭该通道|
|20|MIC2N|不用，经1µF接地|
|21|GNDA|地|
|22|VDDA|3.3V音频模拟电源|
|23|VDDM|同上|
|24|MICBIAS12|麦克风偏置，2.2µF到地|
|25|REFQM|1µF到地|
|26|MICBIAS34|1µF到地；不用于喇叭参考供电|
|27|MIC4N|不用，经1µF接地|
|28|MIC4P|不用，经1µF接地，软件关闭该通道|
|29|REFP34|1µF到地|
|30|REFQ34|1µF到地|
|31|MIC3P|ES8311 OUTP经0Ω和1µF交流耦合|
|32|MIC3N|ES8311 OUTN经0Ω和1µF交流耦合|
|33|EP|地铜与散热过孔，不能悬空|

BOX3：6/7电源经120Ω@参考频率的磁珠共用10µF+100nF，22/23另磁珠共用10µF+100nF。Rev A 应为每个电源脚增加靠近引脚的100nF，保留各域储能电容。磁珠的“120R/1A”不是120Ω串联电阻，应落实具体料号/阻抗频率/直流电阻。所有供电使用3.3V；Rev22 p7要求VDDP/VDDD上下电相差建议不超过10ms，VDDA开时VDDD必须开。

MICBIAS：User Guide p23给出VDDM=3.3V时0x41[6:4]可选2.18～2.87V，默认110为2.78V；0x4B bit6关闭MICBIAS12。选定驻极体建议采用原厂2.2kΩ负载与1µF耦合、MICBIAS初始2.78V；样机实测静态电压和录音噪声后再定增益。BOX3原图另有2kΩ/1kΩ/2kΩ与10µF、33pF的未知4015网络，不认定对本候选最优。

播放参考取 **ES8311差分模拟输出、在功放前**，不是NS4150B的D类扬声器输出。保持ADC参考通道低增益（初始0dB），核算满量程，避免麦克风高增益也套给参考通道。该线路不包含功放失真，硬件连接本身不等于AEC已验证。

## ES8311 全引脚连接表

|脚|名称|Rev A 连接原则|
|---|---|---|
|1|CCLK|I2C SCL|
|2|MCLK|共享音频MCLK|
|3|PVDD|3.3V数字音频电源|
|4|DVDD|同上|
|5|DGND|地|
|6|SCLK/DMIC_SCL|共享BCLK|
|7|ASDOUT|不使用本芯片ADC，NC|
|8|LRCK|共享WS|
|9|DSDIN|ESP32播放DOUT|
|10|AGND|地|
|11|AVDD|3.3V模拟音频电源|
|12|OUTP|分支到ES7210参考及功放正输入|
|13|OUTN|分支到ES7210参考及功放负输入|
|14|DACVREF|2.2µF到地（BOX3值；原厂典型1µF）|
|15|ADCVREF|2.2µF到地|
|16|VMID|2.2µF到地|
|17|MIC1N|播放专用，按BOX3不用NC|
|18|MIC1P/DMIC_SDA|播放专用，按BOX3不用NC|
|19|CDATA|I2C SDA|
|20|CE|地（7位I2C0x18）|
|21|EP|地|

3/4共用磁珠后10µF+100nF；11另磁珠后10µF+100nF；Rev A每电源脚附近补100nF。12/13各经2.2µF再30kΩ到NS4150B 3/4，BOX3此值对应功放增益240k/30k=8倍。原厂ES8311额定差分输出和输入不能直接由供电电压代替，PCB定稿需按播放最大设置核算幅度与限幅。

## NS4150B 全引脚连接表

|脚|名称|连接|
|---|---|---|
|1|CTRL|MCU PA_EN；建议100kΩ下拉默认关，初始化后拉高（相对于BOX上拉的有意改动）|
|2|Bypass|1µF到地（数据表p2；BOX3用2.2µF）|
|3|INP|上文OUTP耦合+30kΩ|
|4|INN|上文OUTN耦合+30kΩ|
|5|VoN|扬声器负；不能接GND|
|6|VCC|稳压音频功率电源；近端1µF+10µF或更大，另100nF可保留|
|7|GND|功率回流，不经过麦克风回流|
|8|VoP|扬声器正|

**重要电源边界**：手册正常3.0～5.0V，绝对最大5.25V；USB-C VBUS不能无条件直接作功放电源。可采用足够电流的稳压3.3V功率轨（输出功率降低，重新核算散热/瞬态）或合规独立稳压轨。不要将BOX3的VBAT标签直接换成USB5V。功放3.3V供电时3.3V MCU控制兼容。输出为桥接D类，任何一端都不是地；测试应差分，不把示波器地夹夹到VoN。

## 绘图和发布前边界

- 从Rev22和BOX图确认的引脚可以用于KiCad建符号；老User Guide应用图不可自动抽取成引脚。
- QFN32、QFN20间距都是0.4mm，不能按常见0.5mm套用。
- ES7210与ES8311共享MCLK/BCLK/WS，但需配置相容I2S/TDM时序，确定麦克风+参考两通道输出方式；这是后续固件必须验证项。
- 地布局保持连续回流并让扬声器大电流避开麦克风/参考；不要因原理图AGND标签而随意切断USB或I2S下面的地平面。
- 麦克风/扬声器为完整型号候选，库存、成本、装配（手焊）、声孔与腔体位置需在生产BOM冻结前确定。不能因此声称全套音频设计已经实机验证。

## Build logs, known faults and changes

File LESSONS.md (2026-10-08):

# 经验教训

## 运行载体不等于用户要返回的产品界面

Claude Code 可以运行在 Ghostty 里，但这不代表 K2 应该把用户送回 terminal。首次实现把“进程在哪里运行”误当成“用户希望在哪里继续处理会话”，忽略了 Claude App 已能通过 `claude://resume?session=<UUID>` 导入并打开对应 Code 会话。

设计“打开来源”时先确定 canonical user surface：对话 Activity 返回其会话 App，CI 返回 run 页面，只有不存在会话界面时才退回 terminal。实现前必须检查目标 App 已注册的 deeplink 和本机消费者日志，不能因为 cwd 更容易取得就自行降低产品目标。

## 拉起应用不等于导航到目标资源

外部 `open` 命令返回 0，只能证明 macOS 接受了 URL 并激活应用，不能证明应用内部成功加载目标。K2 首次验收只看了 `vibebuddyd` 的“已打开”日志，遗漏了 Codex 消费端随后记录的 `thread not loaded`，因此把“打开应用”误报成了“打开对应会话”。

跨应用 deeplink 必须同时验收生产者与消费者：先确认命令调用成功，再检查目标应用的路由日志或可见页面。还要区分生命周期身份和导航身份；Codex 子 Agent 的 `session_id` 用于活动去重，但桌面导航必须使用拥有它的父 `thread_id`。

## 导航来源不能跟着瞬时活动一起销毁

K2 的用途是让用户回到刚才那件事，但首次实现把来源只挂在“工作中/等待输入”的活动上。`Stop` 删除活动后，屏幕还在显示 `DONE`，K2 却已经返回“没有可打开的活动”；daemon 重启也会丢掉同一定位。

活动状态和导航历史是两种生命周期。活动可以结束或过期，最近一次可定位的 Codex thread、Claude session 或 CI run 仍应单独保留，并持久化到本机状态文件。回归测试至少覆盖任务完成后和 daemon 重启后两条路径；实机验收必须在任务结束后再按一次 K2，而不能只在工作中验证。

## EIM 激活脚本不要从自动化脚本中直接 source

EIM 0.19.0 生成的 `activate_idf_v5.5.3.sh` 会读取调用者的 `$0`、`$1` 和 shell 变量来判断是否被 source。它从启用 `set -u` 的 Bash 脚本调用时，可能先因未定义的 `ZSH_VERSION` 失败；即使临时关闭 nounset，也会把调用脚本名误判为“直接执行”并 `exit 1`。

自动化脚本应执行激活脚本的 `-e` 模式读取环境变量，再用固定 Python 解释器调用 `$IDF_PATH/tools/idf.py`。交互式 shell 仍可正常 source 激活脚本。

## 跨组件传递 I2C 地址前先确认地址语义

ESP-IDF 原生 I2C API 使用 7 位设备地址，但 `esp_codec_dev` 1.6.2 的默认 I2C control 接收 8 位线地址，并在内部右移一位。用原生 API 在 `0x18` 探测到 ES8311，不代表可以把同一个数值原样传给音频组件；那会实际访问 `0x0c`。

硬件适配层接入第三方组件时，必须从组件实现确认地址约定，并通过可用的 USB 诊断通道分阶段报告初始化失败位置。

## 聚合状态不能吞掉一次性通知

Codex 的 `Stop` 表示一个 turn 结束，不是整个 session 结束。仅按 `session_id` 聚合并把 `Stop` 转换成剩余任务的状态快照，会吞掉并行任务的完成播报；后续事件又可能重建活动，造成延迟或重复播报。

Hook 生命周期必须用 `session_id + turn_id` 建模。画面属于可去重的持续状态，语音属于每个 turn 只消费一次的边沿通知，两者必须分别处理；重复的同一 `turn_id` 事件不得再次触发语音。

`Stop` 只表示助手停止生成，不等于业务任务成功。对话式提问也会触发 `Stop`；在播报成功前，必须先把“等待用户回答”和“已完成”分开。若上游没有结构化结果，应在隐私边界内做最小分类，只传派生状态，不传回复正文。

## 外部进程的生命周期事件不保证收尾

这是第二次在 Codex Hook 生命周期建模上出错。上一条是把 `Stop` 当成整个 session 结束；这次是假设每个活动最终都会收到 `SessionEnd`。Codex 被强制结束时不发送任何收尾事件，被遗弃的活动会永久占用任务卡，并把宠物钉在需要确认状态，只能重启 daemon 才能清除。

外部进程的生命周期事件是尽力而为的通知，不是事务。由外部事件创建的状态必须能自行过期，且清理要由定时器驱动，不能只在收到下一个事件时惰性触发——最后一个会话消失后不会再有事件到来。过期时限必须按状态语义分档：没有事件的“工作中”通常意味着进程已死，没有事件的“等待用户”只意味着用户还没回来，用同一个时限会在丢提醒和不清理之间二选一。

## 可见状态的“无变化”不等于“无活动”

去重让 `visible_activity` 在画面无变化时返回 `None`。把它与“没有任何活动”当作同一种情况（`visible_activity().or_else(idle)`），会在一个会话结束、而另一个 Agent 的画面恰好未变化时，把仍在运行的任务从屏幕上抹掉。

一个返回 `Option` 的函数若让 `None` 承载两种语义，调用方迟早会混淆其中之一；存在性判断必须直接查询集合，不能从“是否产生了输出”反推。这个缺陷在单 Agent 时期就已存在，直到两个 Agent 并存、同时存活的会话变多，才在实机上暴露。并发度是缺陷的显影剂，单元测试里只有一个会话时它不会现形。

## 构建目标必须写进版本控制，不能留在生成物里

在新建的 worktree 中烧录固件失败，编译产物指向 esp32 而非 esp32s3。原因是 `CONFIG_IDF_TARGET` 只存在于 `sdkconfig` 里，而它按 ESP-IDF 惯例被 gitignore；目标芯片这个项目事实，实际只活在某一台机器的未跟踪文件中。

生成物被忽略是对的，但凡是"换一台机器就必须重新做对"的决定，都必须记录在被跟踪的意图文件里，这里是 `sdkconfig.defaults`。判断方法很直接：删掉所有未跟踪文件后重新构建，结果若发生变化，就说明有事实泄漏在版本控制之外。

## 实机验收的必须是生产实际加载的那一个二进制

心跳与失联指示做完并"实机验收通过"之后，设备仍在无事发生的间隙反复跳 `NO LINK`。原因是验收跑的是 worktree 里的 `target/release/vibebuddyd`，而 LaunchAgent 加载的是主仓库的同名文件，后者从头到尾没有重新编译过。跑着的进程里 `device.heartbeat` 这个字符串出现 0 次。

于是固件端的 15 秒超时上线了，发心跳的那一半没有，功能被做反：一个用来揭穿过时状态的特性，自己变成了持续的假警报。

这类缺陷不会在任何测试里出现，因为代码本身是对的。验收一个跨进程特性时，先确认被观测的那个进程就是生产会加载的那个——查 PID 对应的可执行文件路径，或者直接在二进制里搜新加的字符串。多 worktree 的仓库尤其危险：同一个相对路径在不同 worktree 下是不同的文件。

同一天里同一类问题又出现了一次，位置换成了版本标签本身：`build.rs` 声明只在 `.git/HEAD` 变化时重跑，而 fast-forward 只改 `refs/heads/<branch>`，`HEAD` 的内容一个字节都不变。构建脚本不重跑，二进制里就留着上一个 commit 的 SHA。

共同的根因是构建产物与它所声称的源码状态悄悄脱节。凡是把源码状态刻进产物的机制——版本号、SHA、时间戳——都必须自己回答"它什么时候会过期"，并且要真的试一次：改一个不触发它的东西，再看那个值有没有跟着变。没试过的新鲜度就是假设，而这正是这类缺陷唯一的藏身处。

第三次出现在固件那一侧（2026-09-15）。页脚的 FW 时刻取自 `esp_app_desc.c` 的 `__TIME__`，那个文件只在自己被重编时更新；改了按键代码做增量构建再烧录，启动横幅报的仍是上一次全量构建的 11:44。当时正拿这行横幅当"烧进去的是新固件"的证据，差点被它误导，最后靠的是烧录时 ROM 端 MD5 与产物一致、且产物含新字符串这两条。修法是让本项目每次构建自己生成时刻头文件，不再借用别的组件的编译时刻。上一次记这条教训时只修了 daemon 那一半，没有回头检查固件是否同病——教训写成"这类机制都要试一次"，实际只试了当时出事的那一个。

## 没有对端的输出通道不能做无限等待

为了同时支持原生 USB 和 BOX 的 UART 桥，固件把每一行诊断同时写两路，其中 USB Serial/JTAG 那路用了 `portMAX_DELAY`。只接 UART 桥时，USB 口那头根本没有主机取数据，1025 字节的 tx ring buffer 累计填满后，主任务就永久阻塞在写函数里。画面定格在最后一帧，按键、失联检测、空闲动画跟着一起停摆，而设备看上去只是"没有任务"。

写成功只说明数据离开了本地缓冲，不说明对端存在。凡是可能没有对端的通道，等待时限必须有限；写不进去就丢掉这一段，诊断输出残缺远好过主循环冻结。

Mac 端整晚毫无察觉，是同一个错误的另一半：心跳只朝设备发，写进串口永远成功，于是这个专门用来揭穿过时状态的机制，最后只证明了它自己还活着。存活判断必须依赖对端产生的信号，不能依赖自己发送的动作。

引信长度也值得记：这个死锁要累计约 1KB 输出才触发，桌面上连着调试的几分钟凑不满，当晚验收全部通过，过夜才现形。凡是"缓冲填满才出事"的缺陷，验收就必须把缓冲填满，而不是验证功能走通。

## UART 桥烧录前先确认大块传输能过

修复要烧录，而 CH343 UART 桥在 esptool 默认块大小下握手正常、读芯片信息正常，一到 stub 上传（1536 字节块）就 `Checksum error`。`--no-stub` 同样在写第一个 flash block 时失败——但那时 flash 已经被擦掉了，设备当场变砖，`invalid header: 0xffffffff`。可用参数是 `--no-stub` 加 `FLASH_WRITE_SIZE = 0x100`，慢，但每一块都过校验。

擦除发生在写入之前，所以"能不能连上"完全不能预测"能不能写完"。换了连接方式之后第一次烧录，应当先用一个小分区（例如分区表）试写，确认整条路径能过大块，再动 bootloader。否则一次失败的烧录留下的不是原状，是砖。

这套参数当时只留在了这段文字里，下一次要烧时得重新拼命令；现在固化在 `tools/flash-bridge.sh`，先写分区表、再写 app 的顺序也在脚本的用法里。

## 打开成功不等于打开对了

K2 打开 Claude 会话的功能在 roadmap 里记着"两条 deeplink 均已单独验证"，验证依据是应用日志出现 `Resume deep link: importing CLI session …`、随后跳进了 `/epitaxy/local_<session_id>` 页面。第二天早上按 K2，打开的是一个内容停在前一天的会话；连按八次，每次都把整份 5.4 MB 的 transcript 重新导入一遍。

根因是把外部系统的 id 当成了主键。Hook 报的是 **CLI** 的 session id，而 Claude App 的桌面会话 id 是另一个 UUID 空间，两者一对多：worktree 被删除后会话迁回主仓库、fork、以及每一次 resume 导入，都会多出一条指向同一个 CLI 会话的桌面记录。`claude://resume` 拿这个 id 去磁盘上认领 transcript，同一个 id 在多个项目目录下各有一份时它只能挑一个。

最险的地方是当初那条证据看起来完全吻合：`local_<session_id>` 这个拼接之所以对得上，正是因为导入动作自己就用这个规则造了一个新会话——错误的机制生成了一个长得和预期一模一样的结果。日志里其实已经写明了它在做什么，`importing` 不是 `navigating`，但那句话当时是被当作成功证据读的。外部返回的字眼要照字面理解，它描述的是对方实际执行的动作，不是你希望它执行的动作。

验证跳转、打开、聚焦这类动作，必须核对落点的身份，不能只确认"有反应"。这次可用的判据是目标会话的 `lastFocusedAt` 前移且不产生导入日志；换个场景可能是窗口标题、页面里的一条独有内容。和"写成功不说明对端存在"是同一个家族的错误：验证停在机制层——调用返回了、页面动了——没有走到语义层——到达的是不是那一个。凡是能被一个笼统的"成功"信号蒙混过去的验收，都还没有验收。

## Hook 脚本跑在系统解释器里，不是开发环境里

加 K2 功能时给 `tools/codex-hook.py` 写了一个 `-> str | None` 的签名。本机开发用的 Python 有 3.11，跑得好好的；而 `~/.codex/hooks.json` 里写的是 `/usr/bin/python3`，macOS 自带的是 3.9，PEP 604 的联合类型在 `def` 执行时就求值，模块连导入都过不去。从那次提交起，Codex 的每一个事件都死在 `TypeError` 上，设备上再没出现过 CX 卡片。

失败之所以无声，是两层设计叠加的结果：hook 脚本自己把所有异常都吞掉，以免干扰 Codex 主流程；而这次崩溃发生在导入阶段，根本没走到那段 try。Codex 那边也只看到一个非零退出码，不会替你喊。于是"不打扰主流程"这个正确的设计，同时也保证了故障永远不会被报告。

写给外部宿主调用的脚本，运行时解释器由宿主的配置决定，和你终端里的 `python3` 无关。要么在脚本里消除版本依赖——`from __future__ import annotations` 一行就够——要么就用宿主实际会用的那个解释器跑一遍。判断方法很直接：把配置文件里那条命令原样复制出来，喂一份真实 payload 执行，看退出码。

同一次提交还留下了另一处问题（见上一条）。共同点是改动落在一条自己不常走的路径上，而验收只覆盖了常走的那条。改共享入口时，调用方有几个就要验几个。

## 新建的生成目录先确认被忽略，再 `git add -A`

为休闲模式的实机验收用 `idf.py -B firmware/build-fast` 建了第二个构建目录，`.gitignore` 里只有 `build/`，它不匹配 `build-fast`。功能做完后一句 `git add -A` 把 1485 个构建产物、23 万行连同功能一起提交，推到了分支和 main，直到最后核对 `git show --stat` 才发现，只能改写提交、`--force-with-lease` 重推。

`git status --short | wc -l` 当时显示的数字本来就该引起怀疑，但它只被用来确认"提交后为零"，没有在提交前看一眼"为什么有这么多"。凡是自己新建的目录，尤其名字是从某个已忽略目录派生出来的，提交前先 `git check-ignore` 确认一次；`git add -A` 之前看一眼 `git status` 的条数和前几行，数字异常就停下来。忽略规则也要按模式写：这次补的是 `build-*/`。

K2 在并行任务下跳错了会话：一个任务结束会播报，同时另一个还在跑，而结束的活动已经被移出卡片栈，于是按下 K2 时重新计算焦点，只可能落在还活着的那个——用户刚听到的那件事，恰恰是唯一选不中的。第一版修法是记住刚播报的来源并给它 30 秒有效期，被指出不对。

30 秒是凭空拍的，而且方向就错了：这台设备的全部意义在于人不在电脑前。去接杯水回来再按 K2，窗口早过了，落点又飘回当前任务——恰好在设备最该起作用的场景里失效。正确的规则是让落点由事件接力：一直指向最近一次播报过的那件事，直到下一次播报把它换掉。

判断方法：给一个交互加时间窗之前，先问"用户一定在场吗"。在场才有意义的窗口（防抖、连击合并）可以用时钟；而"帮用户找回刚才那件事"这类功能，用户离场的时长本来就是不可预测的输入，任何固定窗口都是在假设他没走开。

反过来也值得记：还在跑的任务一直显示在屏幕上，用户抬眼就能看见，并不需要一个按键帮他定位；真正需要定位的恰恰是已经从屏幕上消失的东西。做"快捷跳转"这类功能时，先问它到底在替用户省掉哪一步，而不是默认指向"当前最新"。

## UART 桥一次吞不下一整行：先做对照实验再改设备

2026-09-16 写语音包时，经 CH343 桥发往设备的行超过约两百字节就会收错：长度不变，每 384 字节有 32 字节被后面的 32 字节顶替。先后怀疑了 IDF 串口驱动的中断阈值、环形缓冲、主任务栈，改了三轮固件都没用，还顺手把主任务栈撑爆过一次。真正定位靠两步：让设备原样回显收到的字符串逐字节比对（`device.echo`），再换一条完全绕开驱动、直接轮询硬件 FIFO 的接收路径做对照——错误一模一样，说明字节在到达 ESP32 之前已经错了，问题在桥或 macOS 驱动。回看 vibebuddyd 日志，设备早已累计报过三百多次 `invalid_json`，只是短行居多没人在意。

修法在发送端：桥接时按线速分段写（每 128 字节等它在线上走完），原生 USB 口不受影响；烧录同理，espflash 固定 1 KB 写块过不了这条桥，只能自己实现 ROM 协议用 256 字节块。以后遇到"数据内容错但长度对"的链路问题，第一步是找到能证明字节在哪一段出错的对照实验，而不是在最顺手的那一层改参数。

## 改写别人的配置文件之前，先弄清对方怎么对待"改过"

2026-09-16 改名迁移时，App 启动即自动把 `~/.codex/hooks.json` 里六条 hook 的路径从 AgentBeacon 换成 VibeBuddy，代码注释写着"是我们自己写的，直接换，不用再问"。Codex 却在 `config.toml` 的 `[hooks.state]` 里给每条 hook 记着一份 `trusted_hash`，文件一变哈希对不上，条目被判为"改过、待审核"，静默不再运行，直到人在 Codex 里用 `/hooks` 重新信任。从 14:04 起盒子对 Codex 再没出过声，四个小时后才由人发现。同一时段 Claude Code 一切正常，因为它没有这道审核，新会话直接读新配置。

App 自己的接入页当时显示的是橙点加"等待第一次事件…（记得在 Codex 的 /hooks 页面信任这份配置）"。这句话在健康和故障两种情形下一字不差，于是它不是状态，是装饰。现在改成：配置文件的修改时间比 daemon 报的最近一次事件新，就标红并直说去哪做什么；迁移改写了 Codex 配置就当场弹通知。App 不去重算 Codex 的哈希——那是对方的内部格式，跟着版本变——只看"写入之后有没有收到过事件"这一个自己能观测的事实。

这是 Codex hook 第三次无声死亡（前两次：Python 3.9 导入失败、`Stop` 语义）。共同点是 Codex 那头对 hook 的失败与停用都不喊，所以只能由我们这头负责发现。两条规则：往别的程序的配置里写东西，先查它对"文件改了"有什么反应（信任、哈希、缓存、需要重启）；凡是要人补一步才生效的写入，写入的那一刻就要告诉人，而不是留一句常驻小字等他自己想起来。

定位过程也值得记：先手动把一条 Codex payload 喂给 hook 二进制，daemon 立刻记到事件，二进制与 daemon 这段随即出清；再按十分钟分桶统计 hook 日志的调用密度，断点精确落在 14:04，与迁移提交时刻重合。把链路切成能各自证明清白的段，比在最顺手的一层改参数快得多。

## 接线照片看不清不能判错，生成图片不能作为孔位证据

面包板迁移中，先把已插入的短跳线武断称为“散线”，随后生成的原图标注又改变了丝印、孔位和线端落点，导致用户反复质疑本来可能正确的接线。外观交叉不等于电气相连，看不清线端也不等于没插好。

接线核对必须逐条记录原照片中的两端、所在孔排及对应丝印；遮挡项标为未确认，只要求补该处近照或断电测通断，不要求整套拆线重接。生成图出现硬件几何或丝印漂移就作废，不能以附注代替准确性，更不能作为上电依据。标注需保留原始照片证据，通断检查优先于推测隐藏插孔。

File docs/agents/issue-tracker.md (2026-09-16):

# Issue tracker：GitHub

本仓库的 issue 与规格都以 GitHub issue 的形式存在，所有操作用 `gh` CLI。

## 约定

- **建 issue**：`gh issue create --title "..." --body "..."`，多行正文用 heredoc。
- **读 issue**：`gh issue view <number> --comments`，用 `jq` 过滤评论并顺带取标签。
- **列 issue**：`gh issue list --state open --json number,title,body,labels,comments --jq '[.[] | {number, title, body, labels: [.labels[].name], comments: [.comments[].body]}]'`，按需加 `--label` 与 `--state`。
- **评论**：`gh issue comment <number> --body "..."`
- **加 / 去标签**：`gh issue edit <number> --add-label "..."` / `--remove-label "..."`
- **关闭**：`gh issue close <number> --comment "..."`

仓库从 `git remote -v` 推断；在检出目录里运行时 `gh` 会自动识别。

## PR 作为 triage 入口

**PR 作为需求入口：否。** _（若本仓库把外部 PR 当作功能请求处理，改为「是」；`/triage` 会读这个开关。）_

设为「是」时，PR 走与 issue 相同的标签与状态，用 `gh pr` 的对应命令：

- **读 PR**：`gh pr view <number> --comments`，diff 用 `gh pr diff <number>`。
- **列待 triage 的外部 PR**：`gh pr list --state open --json number,title,body,labels,author,authorAssociation,comments`，只保留 `authorAssociation` 为 `CONTRIBUTOR`、`FIRST_TIME_CONTRIBUTOR` 或 `NONE` 的（去掉 `OWNER`、`MEMBER`、`COLLABORATOR`）。
- **评论 / 标签 / 关闭**：`gh pr comment`、`gh pr edit --add-label`/`--remove-label`、`gh pr close`。

GitHub 的 issue 与 PR 共用一个编号空间，裸写的 `#42` 可能是任一种：先 `gh pr view 42`，不行再 `gh issue view 42`。

## 技能说「发布到 issue tracker」时

建一个 GitHub issue。

## 技能说「取相关 ticket」时

运行 `gh issue view <number> --comments`。

## Wayfinding 操作

供 `/wayfinder` 使用。**地图**是一个 issue，**子项**是作为 ticket 的子 issue。

- **地图**：一个打了 `wayfinder:map` 标签的 issue，正文放 Notes / Decisions-so-far / Fog。`gh issue create --label wayfinder:map`。
- **子 ticket**：以 GitHub sub-issue 的方式挂在地图下（走 `gh api` 的 sub-issues 端点）。sub-issue 不可用时，把子项加进地图正文的任务列表，并在子项正文顶部写 `Part of #<map>`。标签：`wayfinder:<type>`（`research`/`prototype`/`grilling`/`task`）。认领后把 ticket 指派给负责的开发者。
- **阻塞**：用 GitHub **原生 issue 依赖**，这是界面可见的规范表示。加一条边：`gh api --method POST repos/<owner>/<repo>/issues/<child>/dependencies/blocked_by -F issue_id=<blocker-db-id>`，其中 `<blocker-db-id>` 是阻塞方的数字**数据库 id**（`gh api repos/<owner>/<repo>/issues/<n> --jq .id`，_不是_ `#number` 或 `node_id`）。GitHub 通过 `issue_dependencies_summary.blocked_by` 报告仍开着的阻塞方，那就是实时的门。依赖不可用时，退回到子项正文顶部一行 `Blocked by: #<n>, #<n>`。所有阻塞方都关闭时 ticket 才解除阻塞。
- **前沿查询**：列出地图的开放子项（`gh issue list --state open`，限定在地图的 sub-issue / 任务列表内），去掉仍有开放阻塞方（`issue_dependencies_summary.blocked_by > 0`，或 `Blocked by` 行里有开放 issue）或已有指派人的，按地图顺序取第一个。
- **认领**：`gh issue edit <n> --add-assignee @me`，是会话的第一次写入。
- **解决**：`gh issue comment <n> --body "<answer>"`，然后 `gh issue close <n>`，再把上下文指针（gist 加链接）追加到地图的 Decisions-so-far。

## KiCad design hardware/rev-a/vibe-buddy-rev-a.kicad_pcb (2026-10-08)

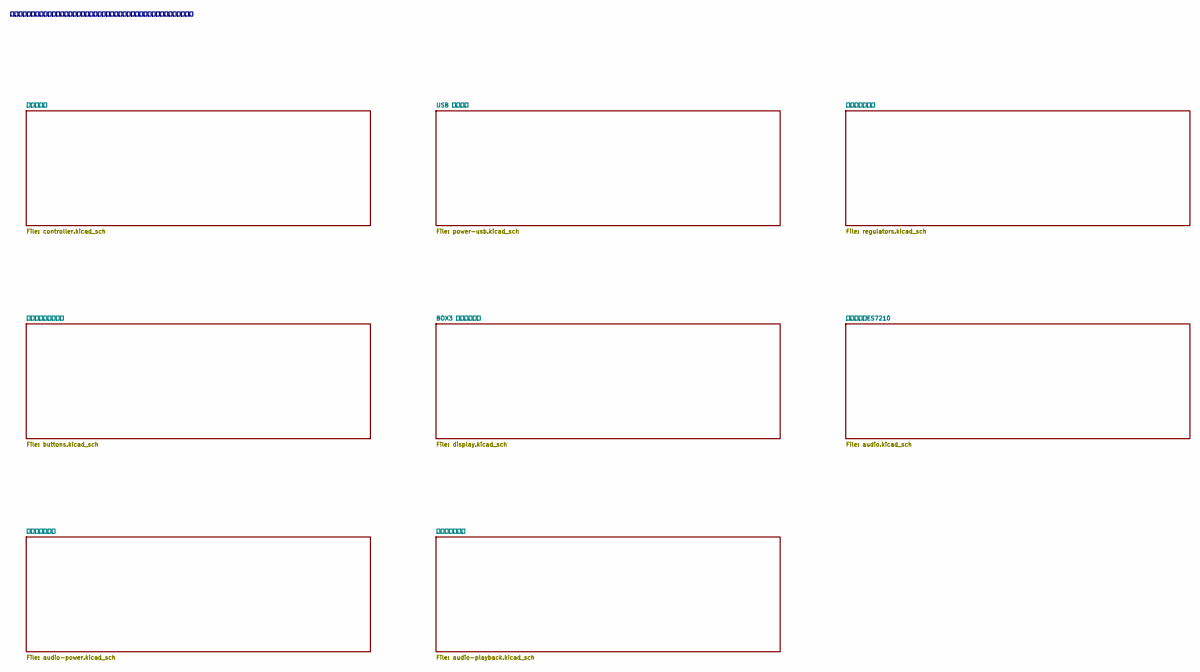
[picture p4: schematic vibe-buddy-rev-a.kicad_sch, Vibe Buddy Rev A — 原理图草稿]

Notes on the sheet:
所有页面使用同名全局网络连接。已有未布线工程布局；机械配合与电源预算尚待验证，禁止投产。

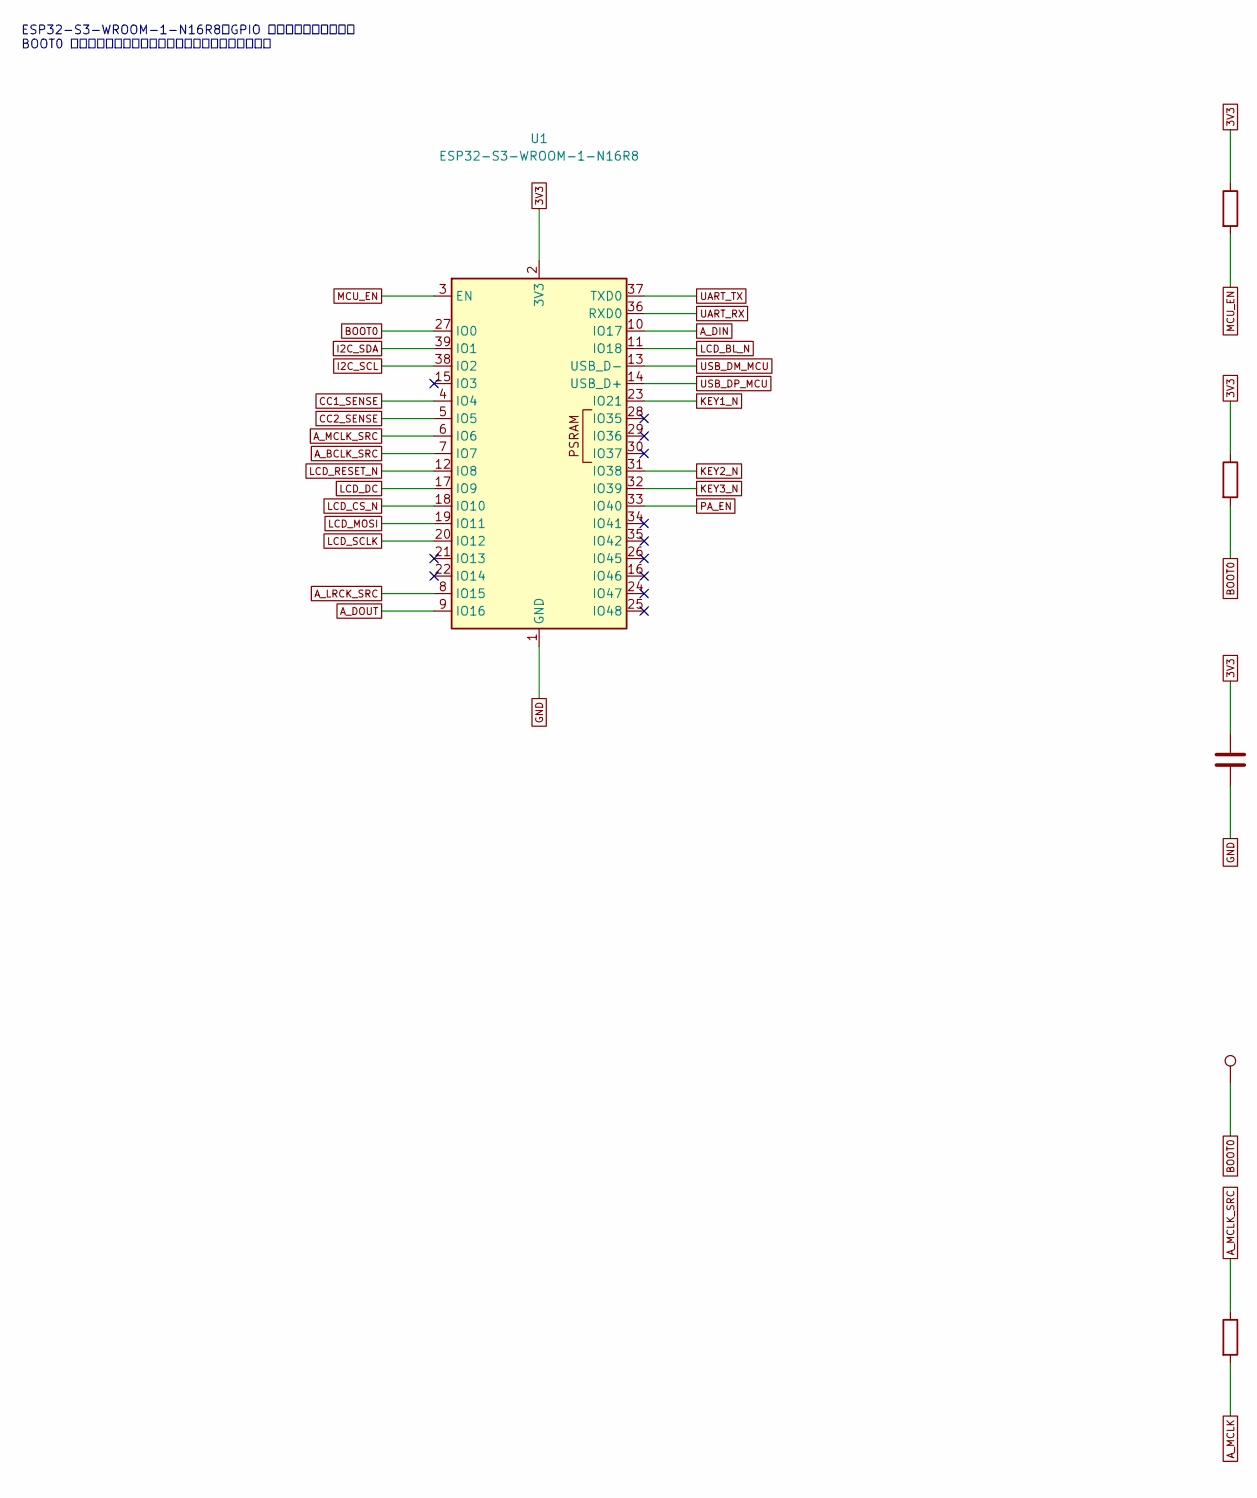
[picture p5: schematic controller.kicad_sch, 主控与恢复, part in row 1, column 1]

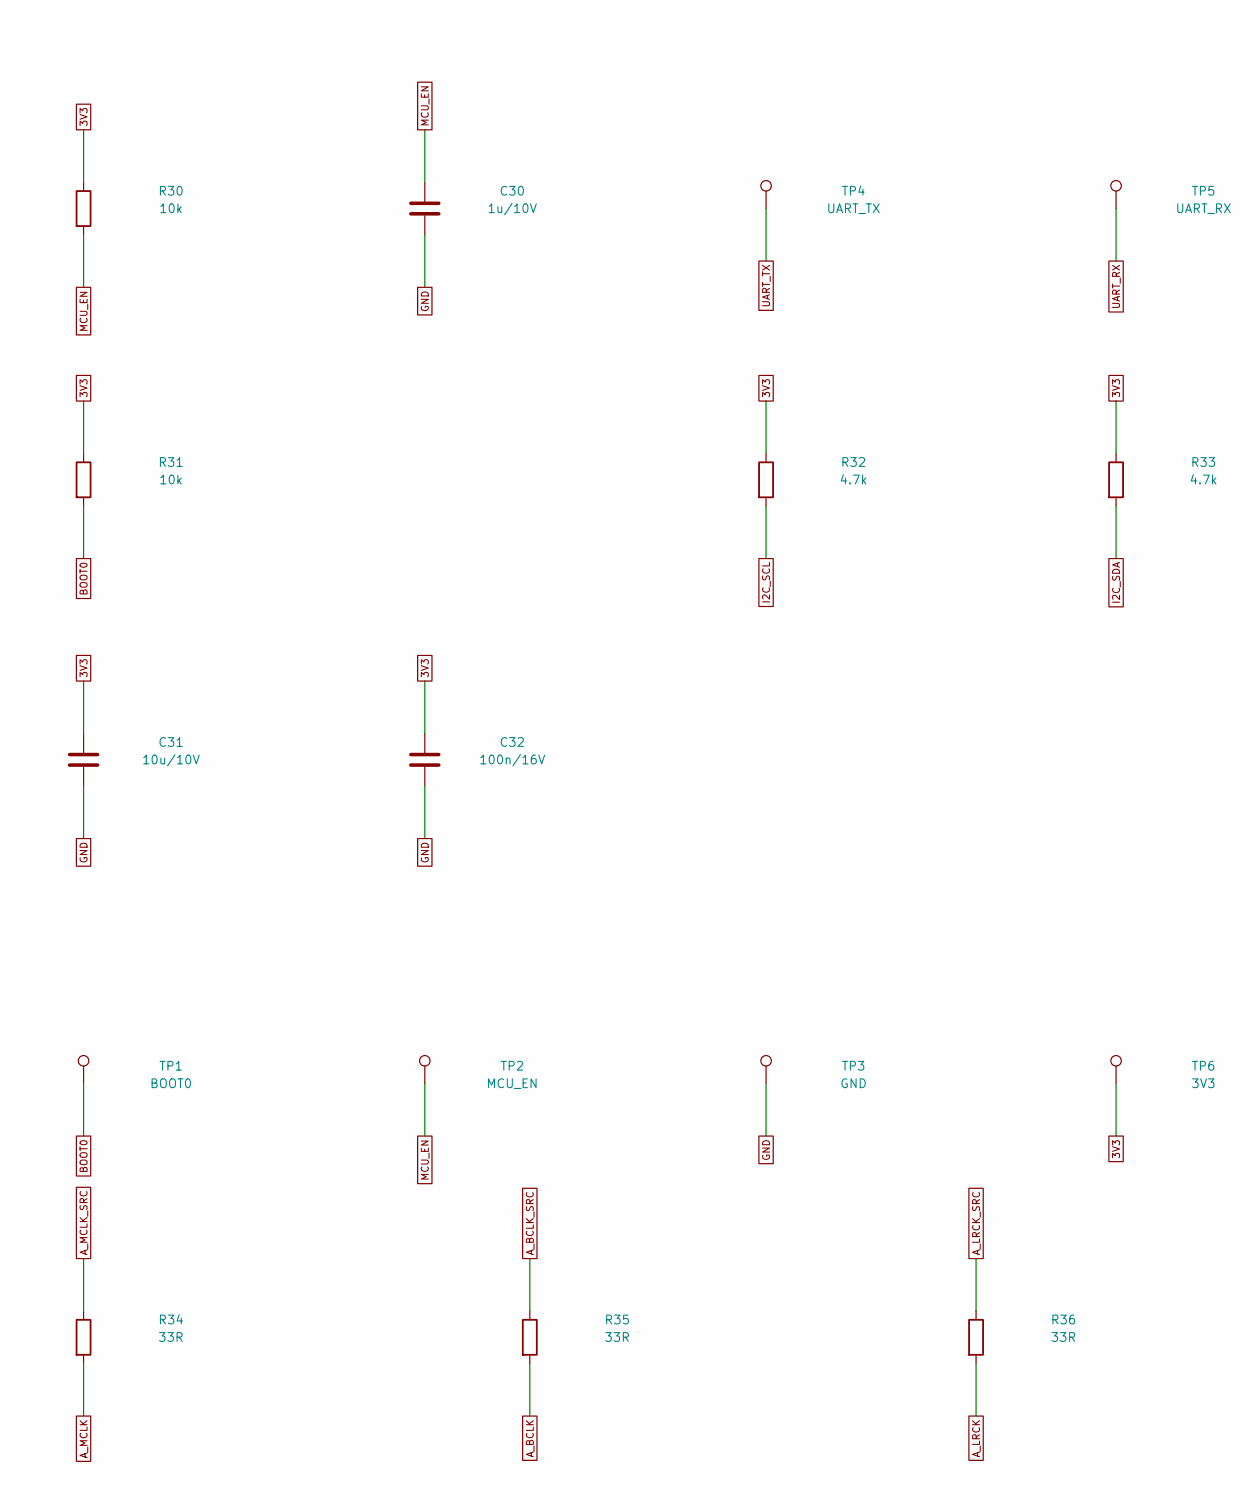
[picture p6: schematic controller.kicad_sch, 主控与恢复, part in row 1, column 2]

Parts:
C30: 1u/10V; C_0603_1608Metric
C31: 10u/10V; C_0805_2012Metric
C32: 100n/16V; C_0603_1608Metric
R30, R31: 10k; R_0603_1608Metric
R32, R33: 4.7k; R_0603_1608Metric
R34, R35, R36: 33R; R_0603_1608Metric
TP1: BOOT0; TestPoint_Pad_D1.5mm
TP2: MCU_EN; TestPoint_Pad_D1.5mm
TP3: GND; TestPoint_Pad_D1.5mm
TP4: UART_TX; TestPoint_Pad_D1.5mm
TP5: UART_RX; TestPoint_Pad_D1.5mm
TP6: 3V3; TestPoint_Pad_D1.5mm
U1: ESP32-S3-WROOM-1-N16R8; ESP32-S3-WROOM-1; MPN ESP32-S3-WROOM-1-N16R8

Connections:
3V3: C31.1, C32.1, R30.1, R31.1, R32.1, R33.1, TP6.1, U1.2 (3V3); also elsewhere on the board
A_BCLK: R35.2; also elsewhere on the board
A_BCLK_SRC: R35.1, U1.7 (IO7)
A_DIN: U1.10 (IO17); also elsewhere on the board
A_DOUT: U1.9 (IO16); also elsewhere on the board
A_LRCK: R36.2; also elsewhere on the board
A_LRCK_SRC: R36.1, U1.8 (IO15)
A_MCLK: R34.2; also elsewhere on the board
A_MCLK_SRC: R34.1, U1.6 (IO6)
BOOT0: R31.2, TP1.1, U1.27 (IO0)
CC1_SENSE: U1.4 (IO4); also elsewhere on the board
CC2_SENSE: U1.5 (IO5); also elsewhere on the board
GND: C30.2, C31.2, C32.2, TP3.1, U1.1 (GND), U1.40 (GND), U1.41 (GND); also elsewhere on the board
I2C_SCL: R32.2, U1.38 (IO2); also elsewhere on the board
I2C_SDA: R33.2, U1.39 (IO1); also elsewhere on the board
KEY1_N: U1.23 (IO21); also elsewhere on the board
KEY2_N: U1.31 (IO38); also elsewhere on the board
KEY3_N: U1.32 (IO39); also elsewhere on the board
LCD_BL_N: U1.11 (IO18); also elsewhere on the board
LCD_CS_N: U1.18 (IO10); also elsewhere on the board
LCD_DC: U1.17 (IO9); also elsewhere on the board
LCD_MOSI: U1.19 (IO11); also elsewhere on the board
LCD_RESET_N: U1.12 (IO8); also elsewhere on the board
LCD_SCLK: U1.20 (IO12); also elsewhere on the board
MCU_EN: C30.1, R30.2, TP2.1, U1.3 (EN); also elsewhere on the board
PA_EN: U1.33 (IO40); also elsewhere on the board
UART_RX: TP5.1, U1.36 (RXD0)
UART_TX: TP4.1, U1.37 (TXD0)
USB_DM_MCU: U1.13 (USB_D-); also elsewhere on the board
USB_DP_MCU: U1.14 (USB_D+); also elsewhere on the board

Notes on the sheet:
ESP32-S3-WROOM-1-N16R8；GPIO 分配为本自研板专用。 BOOT0 测试点拉低后按复位进入恢复下载；无外露下载键。

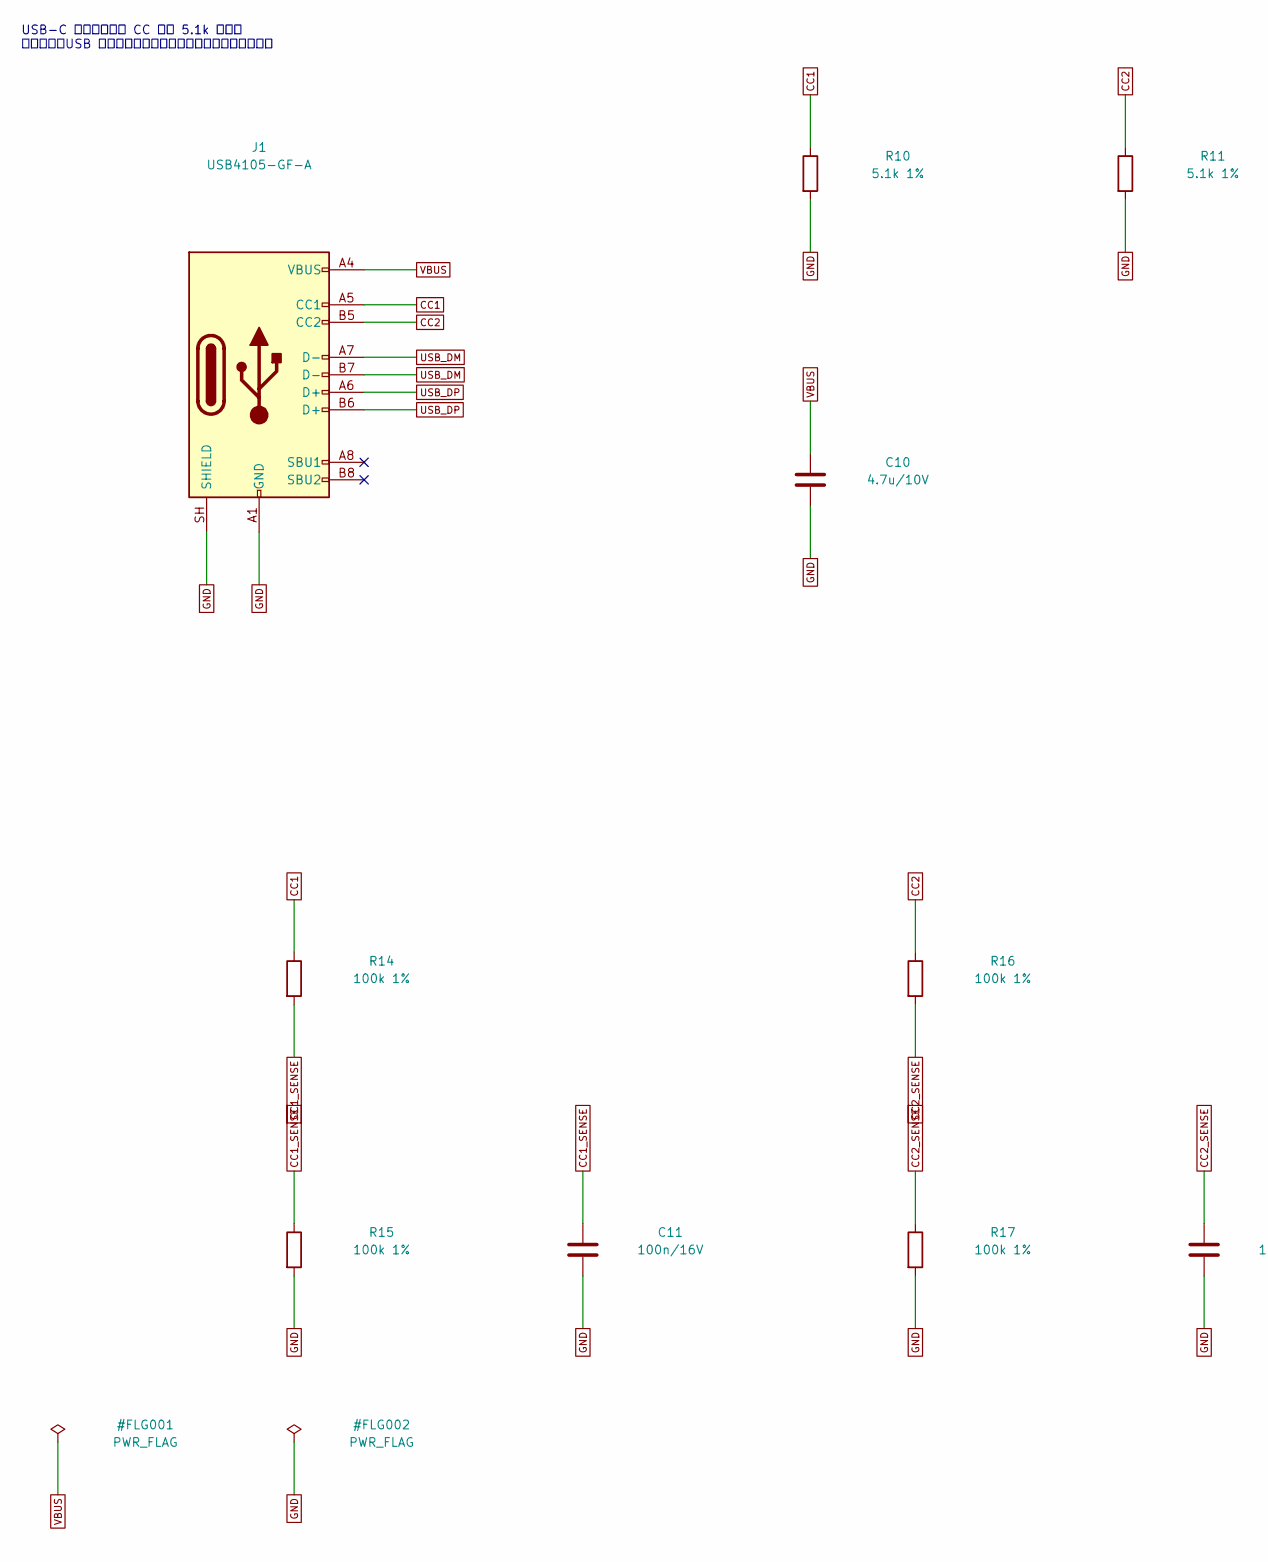
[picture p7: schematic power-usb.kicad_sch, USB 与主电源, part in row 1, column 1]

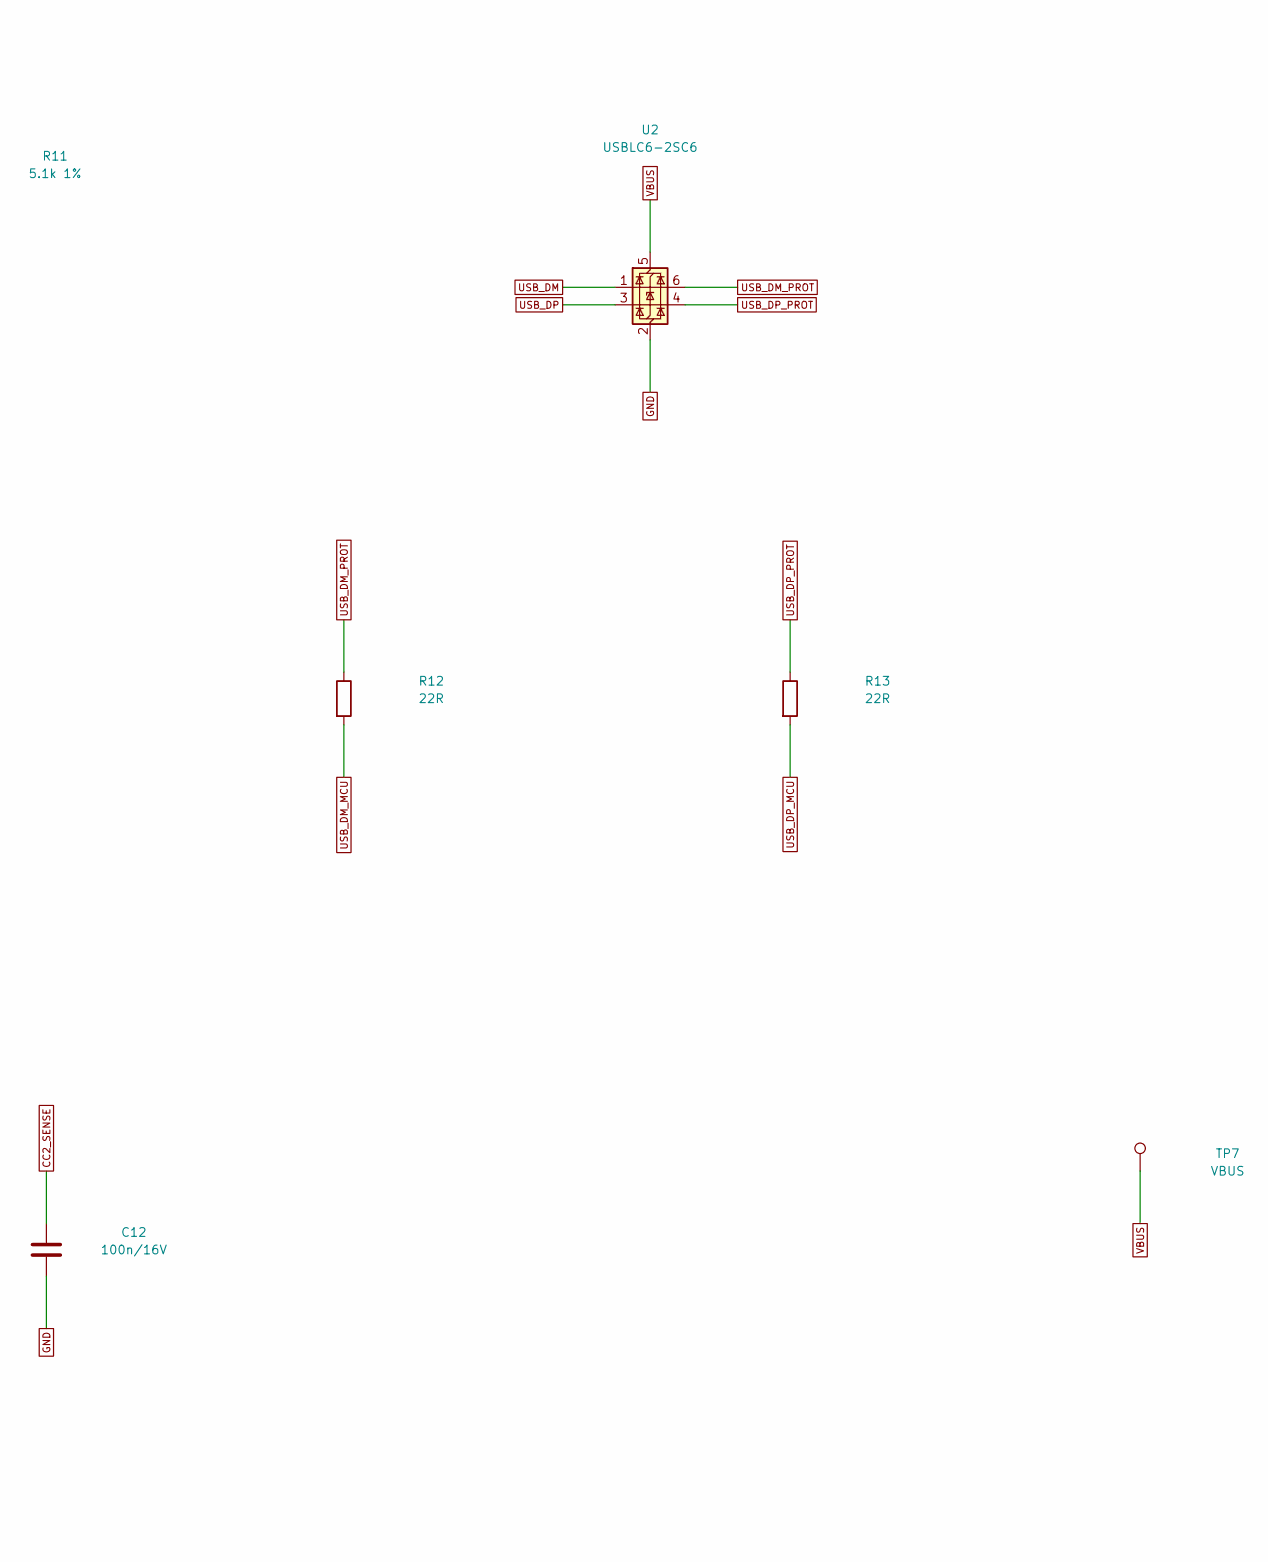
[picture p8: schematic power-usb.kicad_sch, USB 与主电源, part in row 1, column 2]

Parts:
C10: 4.7u/10V; C_0603_1608Metric
C11, C12: 100n/16V; C_0603_1608Metric
J1: USB4105-GF-A; USB_C_Receptacle_GCT_USB4105-xx-A_16P_TopMnt_Horizontal; MPN USB4105-GF-A
R10, R11: 5.1k 1%; R_0603_1608Metric
R12, R13: 22R; R_0603_1608Metric
R14, R15, R16, R17: 100k 1%; R_0603_1608Metric
TP7: VBUS; TestPoint_Pad_D1.5mm
U2: USBLC6-2SC6; SOT-23-6; MPN USBLC6-2SC6

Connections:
CC1: J1.A5 (CC1), R10.1, R14.1
CC1_SENSE: C11.1, R14.2, R15.1; also elsewhere on the board
CC2: J1.B5 (CC2), R11.1, R16.1
CC2_SENSE: C12.1, R16.2, R17.1; also elsewhere on the board
GND: C10.2, C11.2, C12.2, J1.A1 (GND), J1.A12 (GND), J1.B1 (GND), J1.B12 (GND), J1.SH (SHIELD), R10.2, R11.2, R15.2, R17.2, U2.2 (GND); also elsewhere on the board
USB_DM: J1.A7 (D-), J1.B7 (D-), U2.1 (I/O1)
USB_DM_MCU: R12.2; also elsewhere on the board
USB_DM_PROT: R12.1, U2.6 (I/O1)
USB_DP: J1.A6 (D+), J1.B6 (D+), U2.3 (I/O2)
USB_DP_MCU: R13.2; also elsewhere on the board
USB_DP_PROT: R13.1, U2.4 (I/O2)
VBUS: C10.1, J1.A4 (VBUS), J1.A9 (VBUS), J1.B4 (VBUS), J1.B9 (VBUS), TP7.1, U2.5 (VBUS); also elsewhere on the board

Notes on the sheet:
USB-C 设备端；两路 CC 各自 5.1k 下拉。 输入浪涌、USB 枚举前功耗和限流策略仍属发布前待验证项。

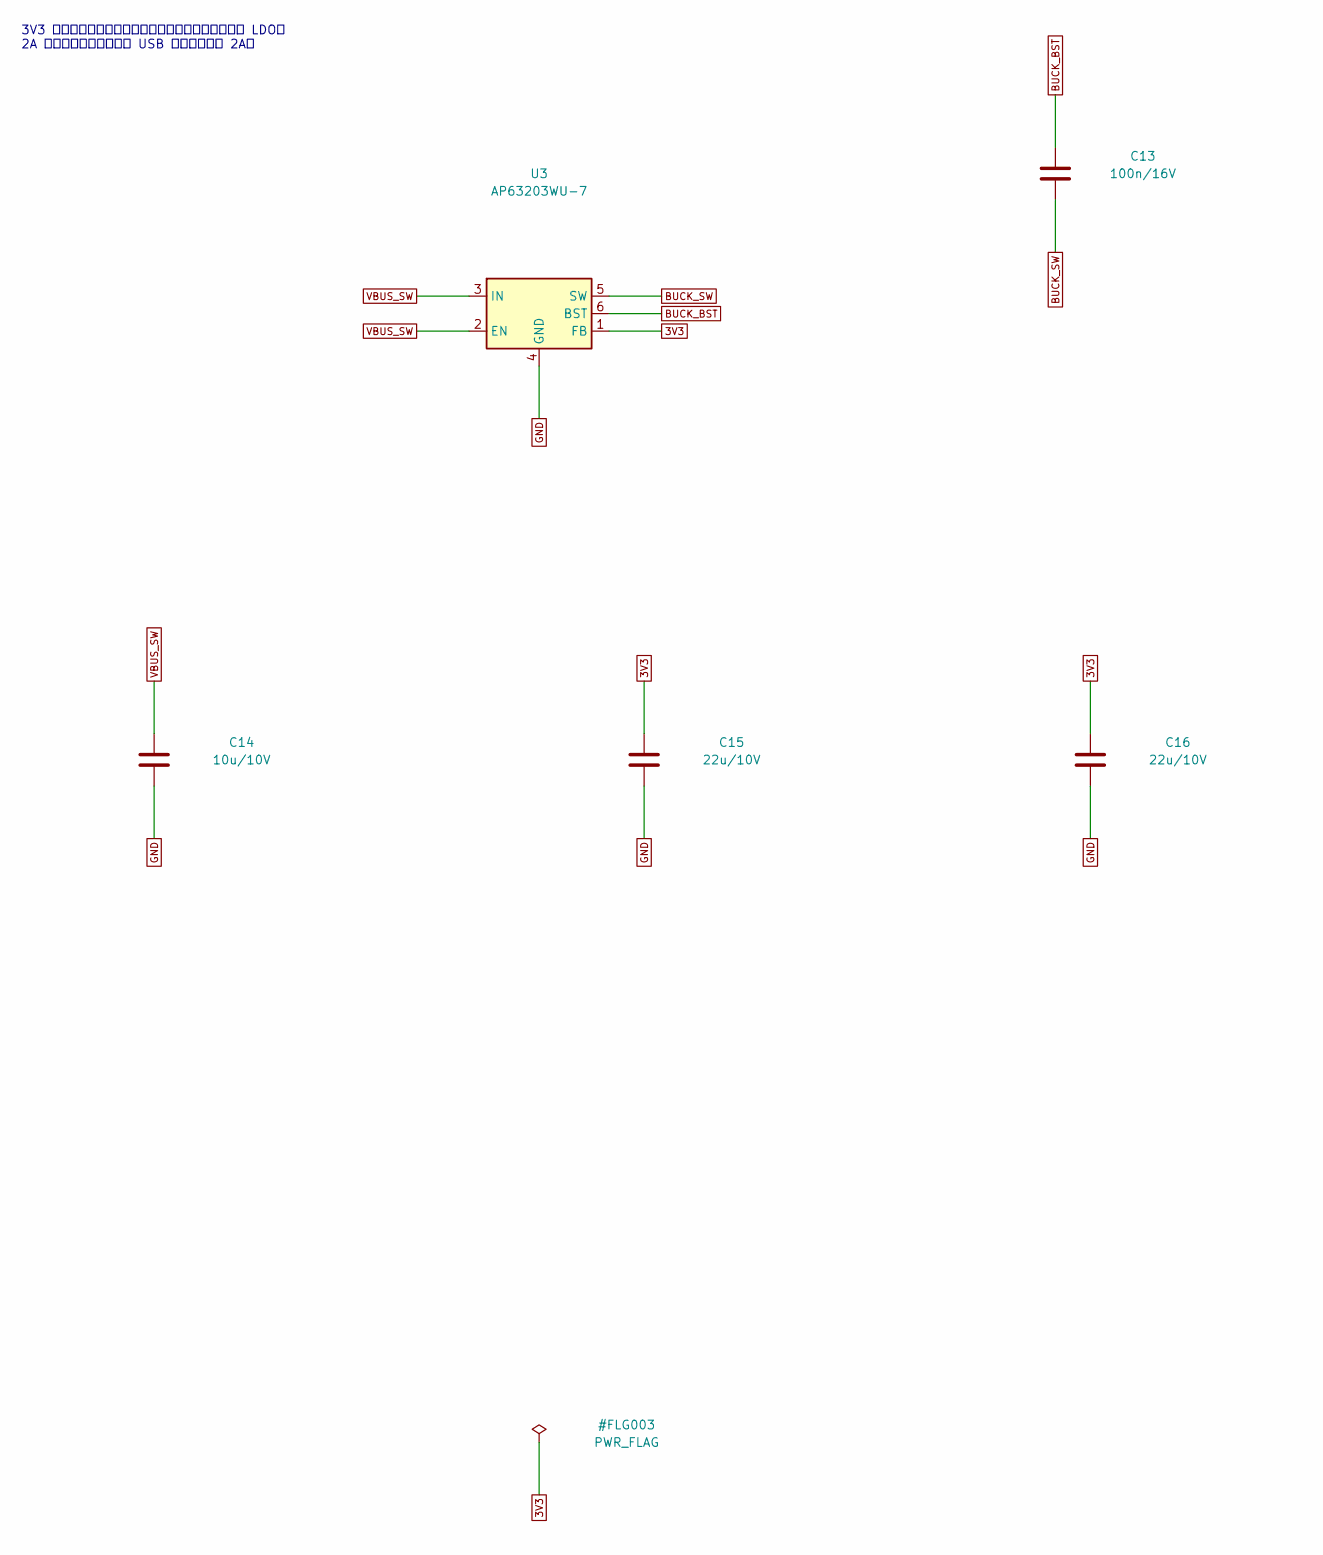
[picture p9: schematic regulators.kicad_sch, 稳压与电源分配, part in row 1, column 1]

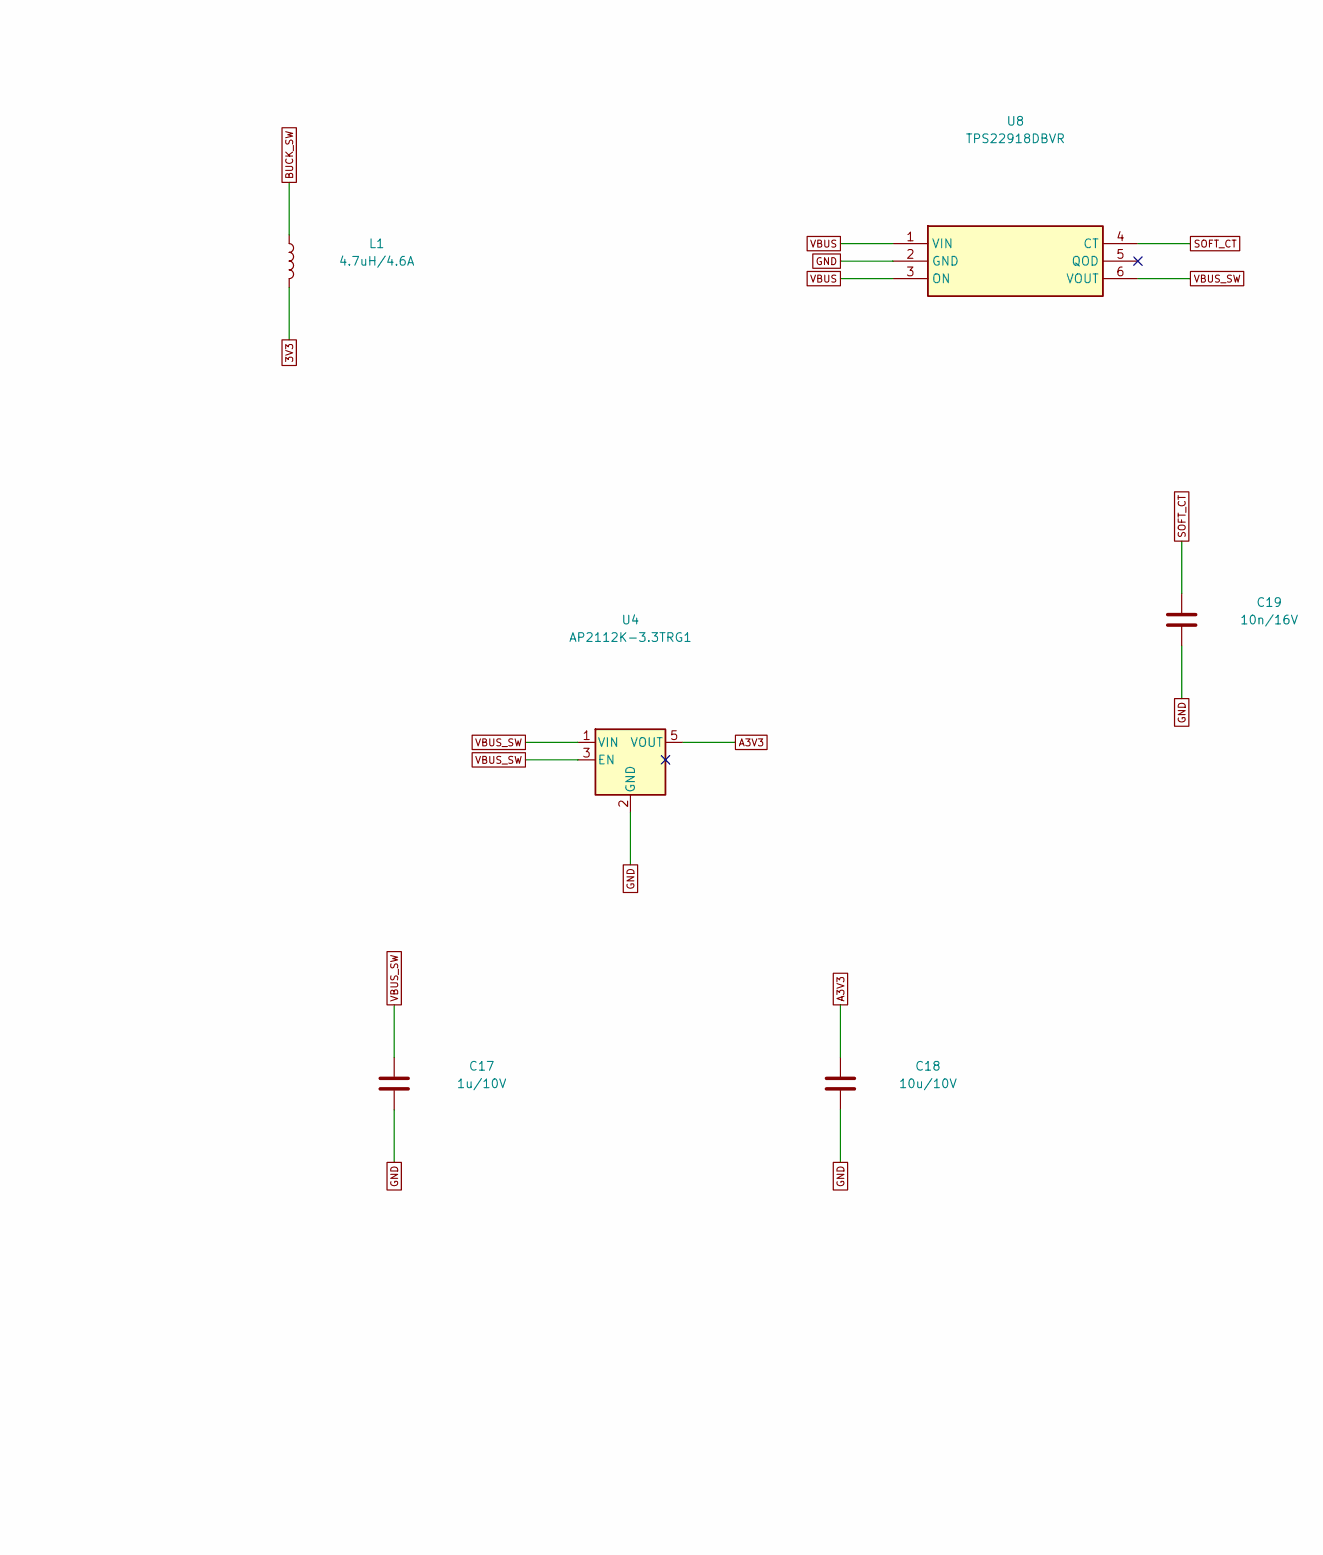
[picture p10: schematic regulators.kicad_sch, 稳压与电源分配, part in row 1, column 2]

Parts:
C13: 100n/16V; C_0603_1608Metric
C14, C18: 10u/10V; C_0805_2012Metric
C15, C16: 22u/10V; C_0805_2012Metric
C17: 1u/10V; C_0603_1608Metric
C19: 10n/16V; C_0603_1608Metric
L1: 4.7uH/4.6A; L_Bourns_SRP5030T; MPN SRP5030T-4R7M
U3: AP63203WU-7; TSOT-23-6; MPN AP63203WU-7
U4: AP2112K-3.3TRG1; SOT-23-5; MPN AP2112K-3.3TRG1
U8: TPS22918DBVR; SOT-23-6; MPN TPS22918DBVR

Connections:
3V3: C15.1, C16.1, L1.2, U3.1 (FB); also elsewhere on the board
A3V3: C18.1, U4.5 (VOUT); also elsewhere on the board
BUCK_BST: C13.1, U3.6 (BST)
BUCK_SW: C13.2, L1.1, U3.5 (SW)
GND: C14.2, C15.2, C16.2, C17.2, C18.2, C19.2, U3.4 (GND), U4.2 (GND), U8.2 (GND); also elsewhere on the board
SOFT_CT: C19.1, U8.4 (CT)
VBUS: U8.1 (VIN), U8.3 (ON); also elsewhere on the board
VBUS_SW: C14.1, C17.1, U3.2 (EN), U3.3 (IN), U4.1 (VIN), U4.3 (EN), U8.6 (VOUT)

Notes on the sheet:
3V3 开关稳压供主控、屏幕与功放；模拟电路使用独立 LDO。 2A 是稳压器能力，不代表 USB 主机允许取用 2A。

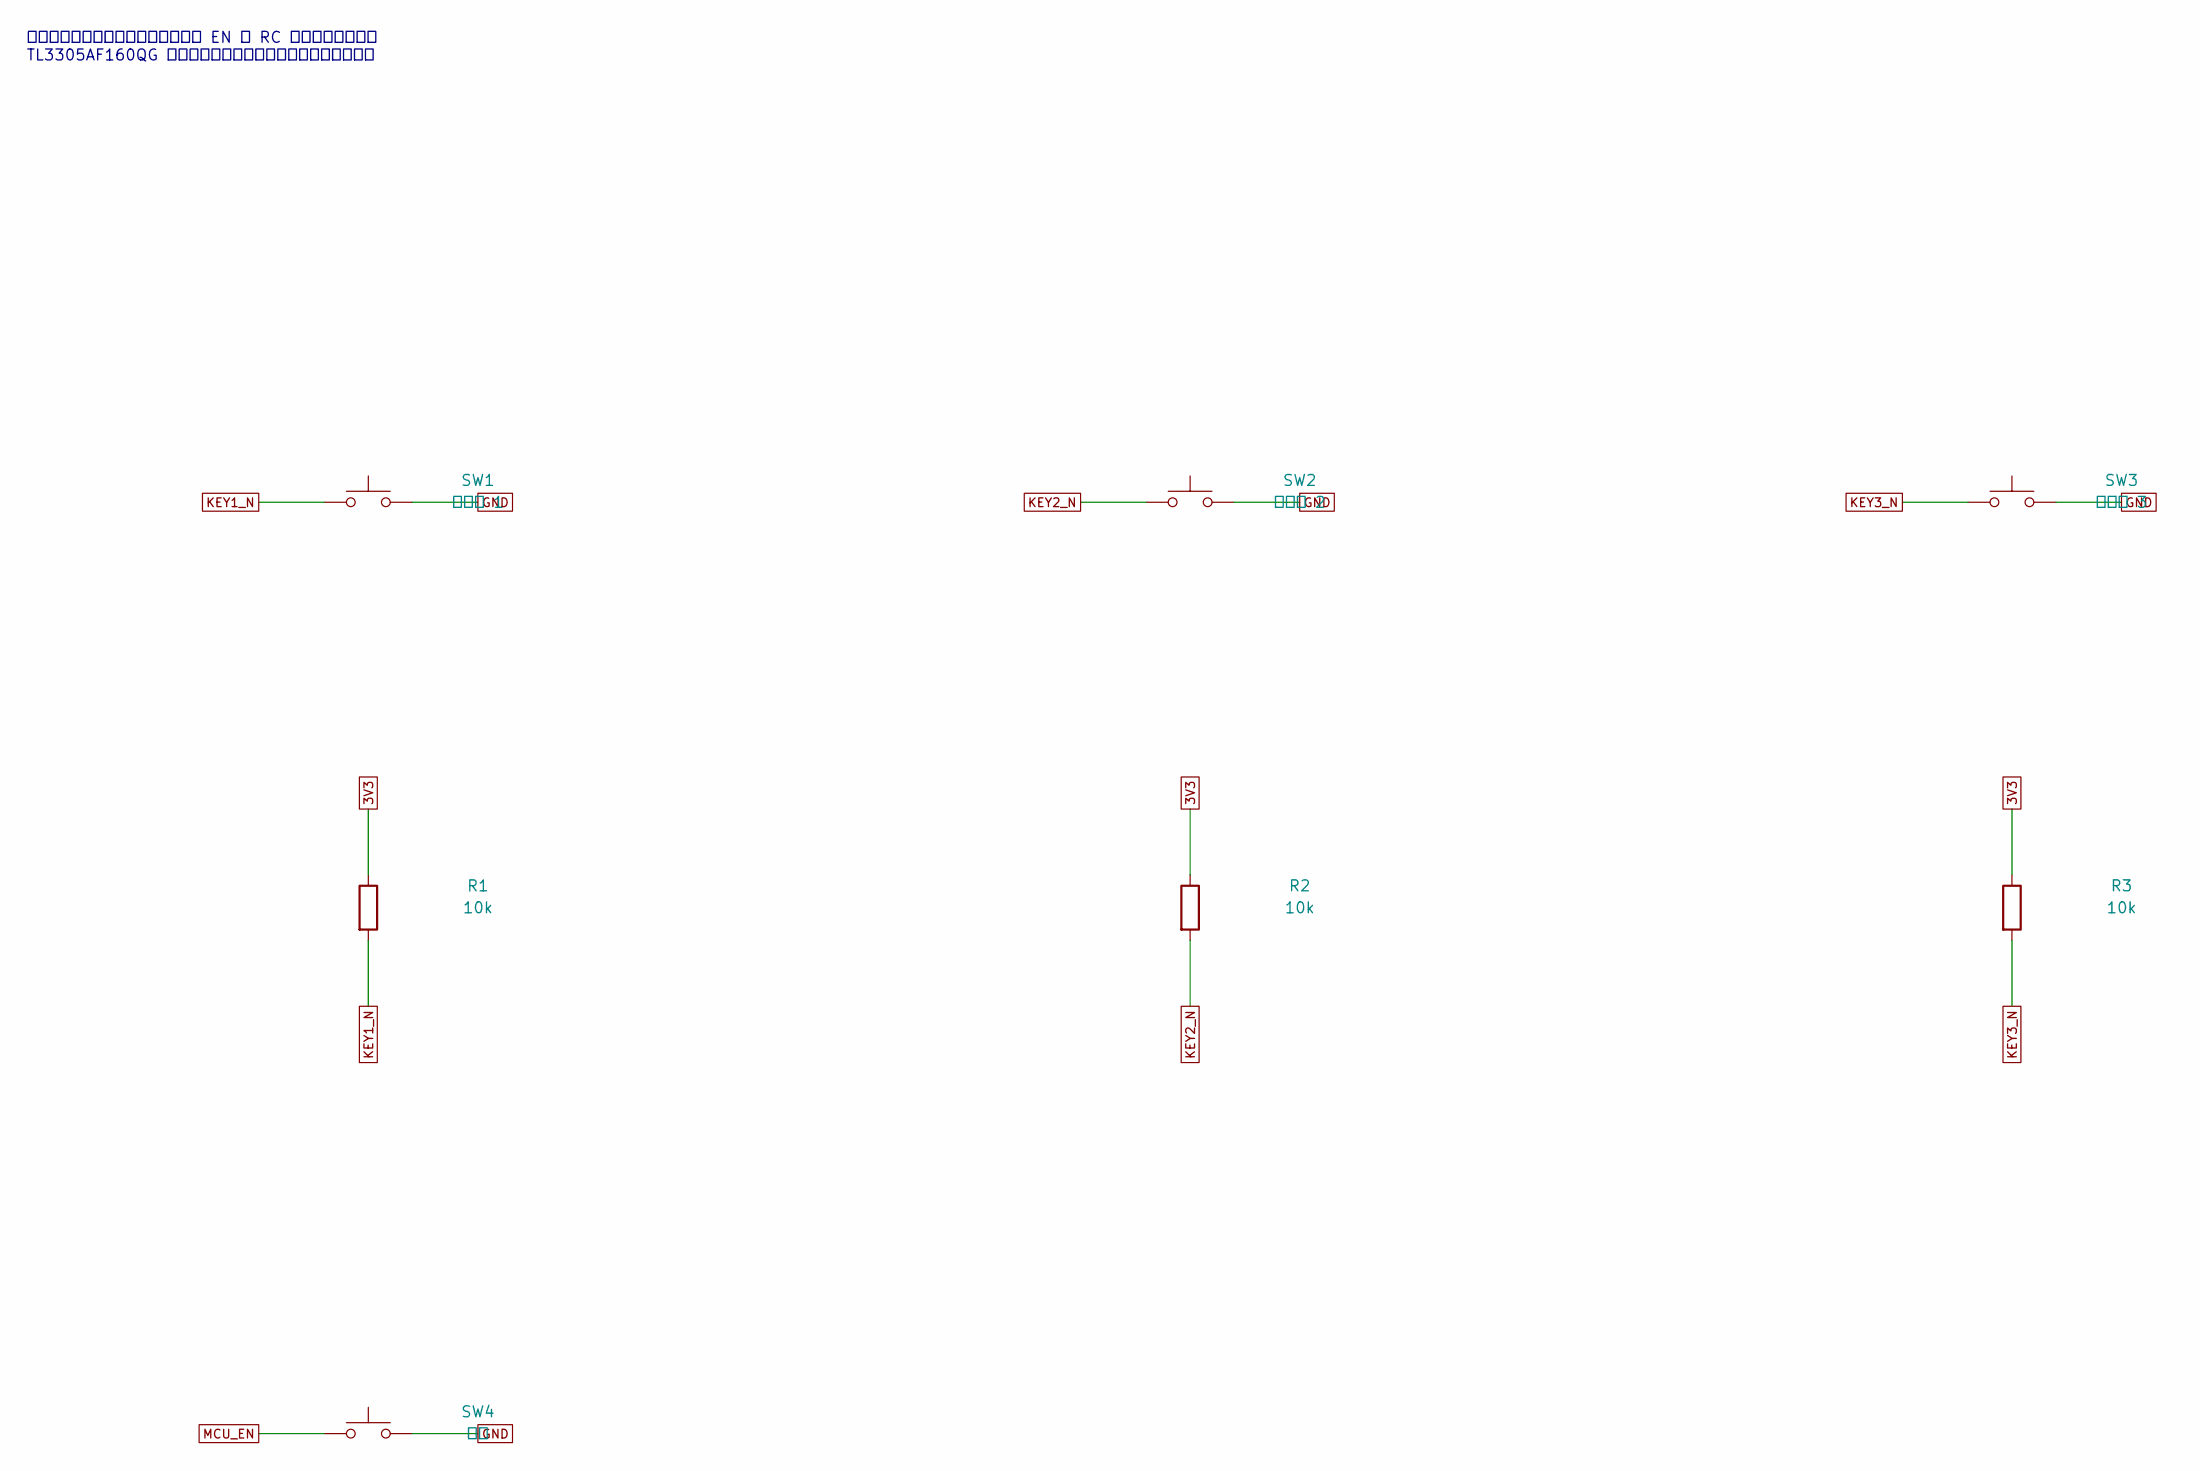
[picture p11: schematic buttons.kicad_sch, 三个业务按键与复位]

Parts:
R1, R2, R3: 10k; R_0603_1608Metric
SW1: 业务键 1; SW_SPST_TL3305A; MPN TL3305AF160QG
SW2: 业务键 2; SW_SPST_TL3305A; MPN TL3305AF160QG
SW3: 业务键 3; SW_SPST_TL3305A; MPN TL3305AF160QG
SW4: 复位; SW_SPST_TL3305A; MPN TL3305AF160QG

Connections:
3V3: R1.1, R2.1, R3.1; also elsewhere on the board
GND: SW1.2, SW2.2, SW3.2, SW4.2; also elsewhere on the board
KEY1_N: R1.2, SW1.1; also elsewhere on the board
KEY2_N: R2.2, SW2.1; also elsewhere on the board
KEY3_N: R3.2, SW3.1; also elsewhere on the board
MCU_EN: SW4.1; also elsewhere on the board

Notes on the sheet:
业务键低电平有效，固件消抖。复位 EN 的 RC 网络位于主控页。 TL3305AF160QG 上按式工程候选；按帽高度与装配待验证。

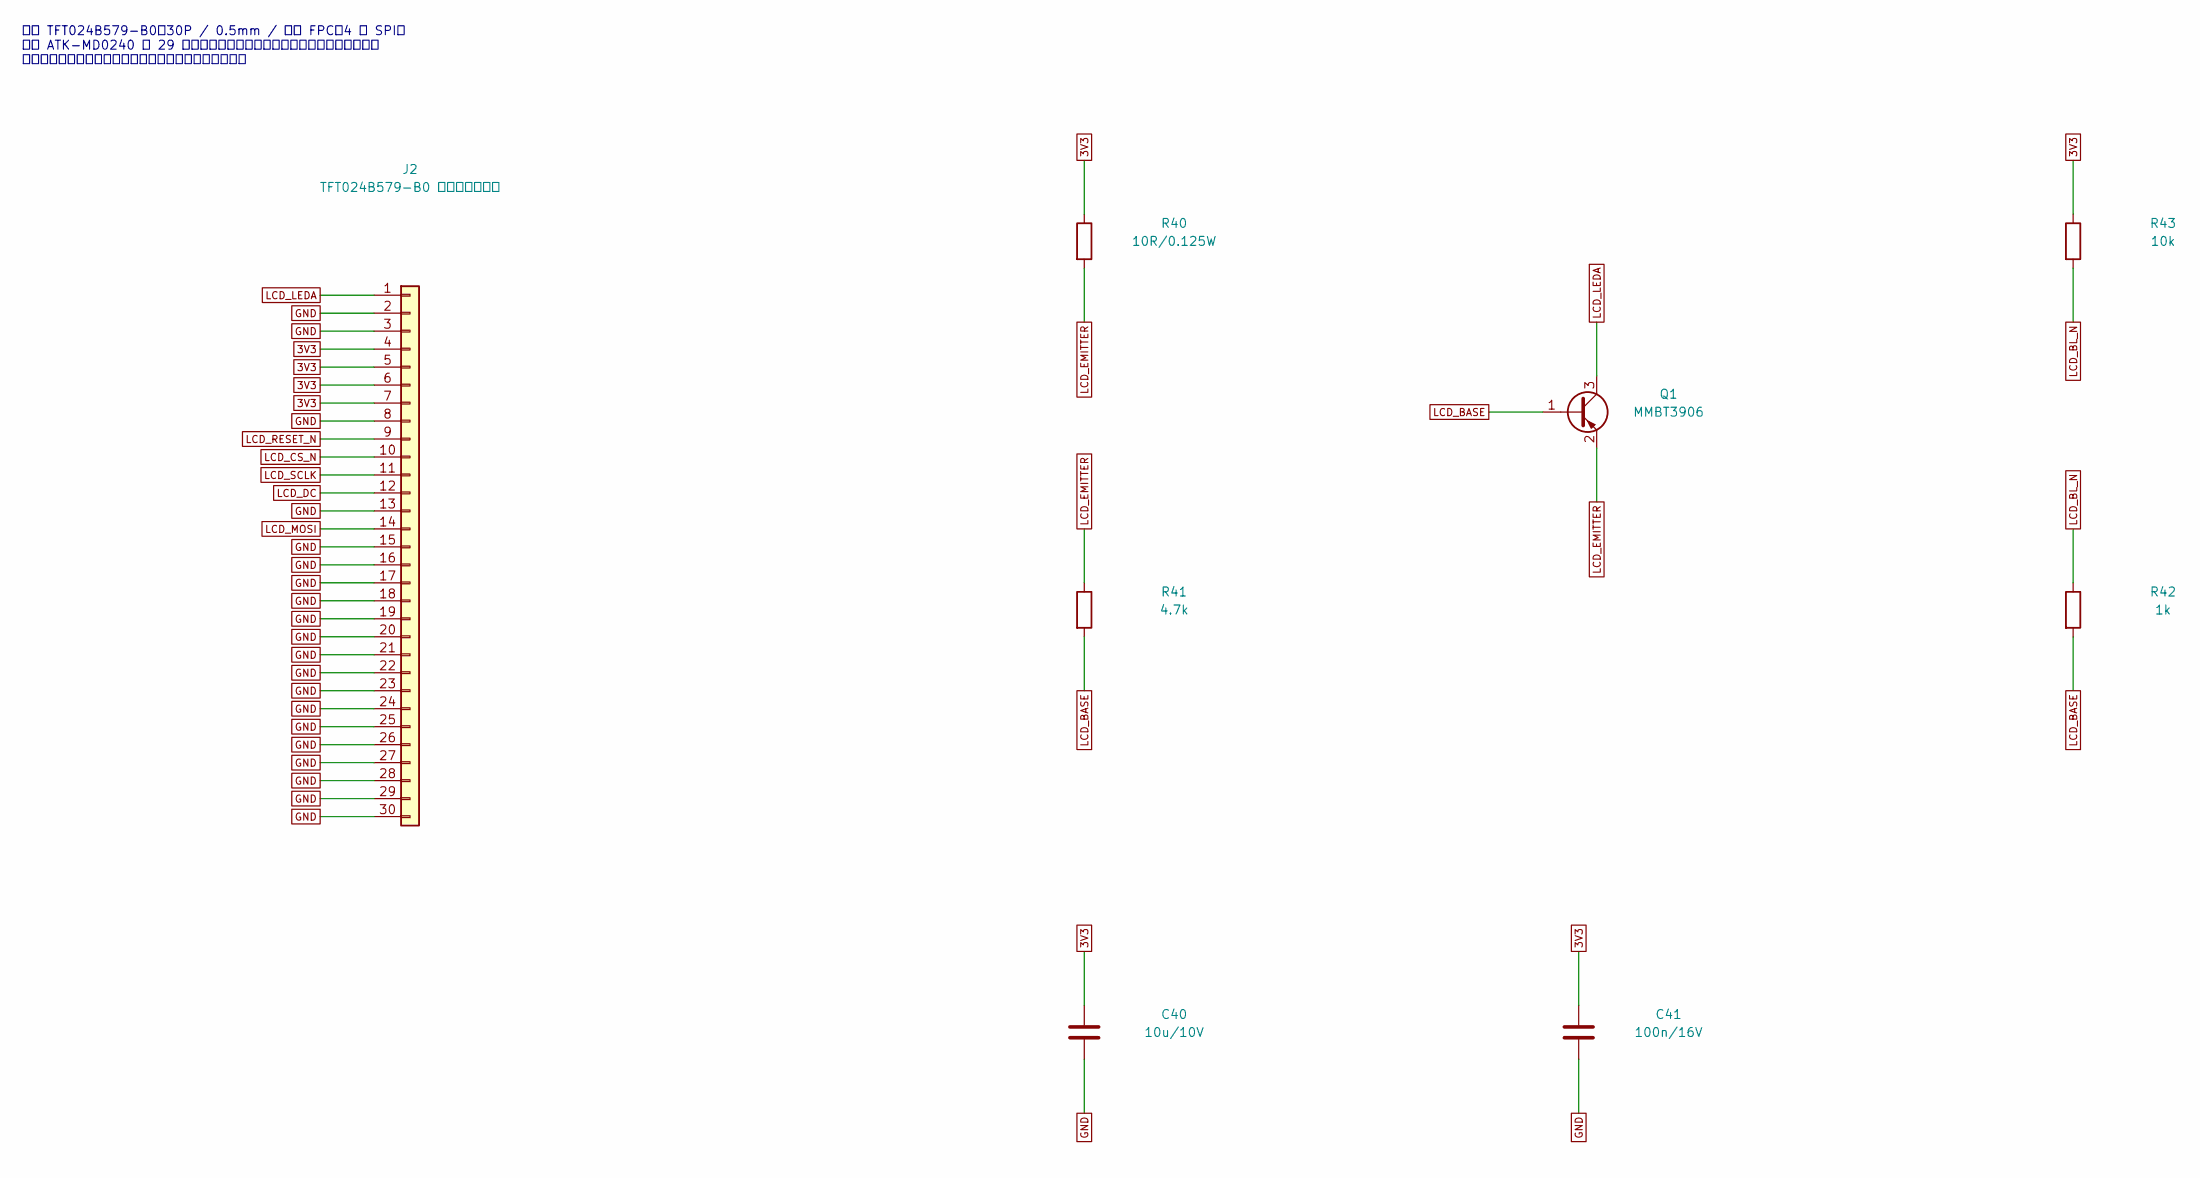
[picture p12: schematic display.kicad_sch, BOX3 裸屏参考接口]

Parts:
C40: 10u/10V; C_0805_2012Metric
C41: 100n/16V; C_0603_1608Metric
J2: TFT024B579-B0 接口（待核实）; Hirose_FH12-30S-0.5SH_1x30-1MP_P0.50mm_Horizontal; MPN FH12-30S-0.5SH(55)
Q1: MMBT3906; SOT-23; MPN MMBT3906
R40: 10R/0.125W; R_0603_1608Metric
R41: 4.7k; R_0603_1608Metric
R42: 1k; R_0603_1608Metric
R43: 10k; R_0603_1608Metric

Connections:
3V3: C40.1, C41.1, J2.4, J2.5, J2.6, J2.7, R40.1, R43.1; also elsewhere on the board
GND: C40.2, C41.2, J2.2, J2.3, J2.8, J2.13, J2.15, J2.16, J2.17, J2.18, J2.19, J2.20, J2.21, J2.22, J2.23, J2.24, J2.25, J2.26, J2.27, J2.28, J2.29, J2.30; also elsewhere on the board
LCD_BASE: Q1.1 (B), R41.2, R42.2
LCD_BL_N: R42.1, R43.2; also elsewhere on the board
LCD_CS_N: J2.10; also elsewhere on the board
LCD_DC: J2.12; also elsewhere on the board
LCD_EMITTER: Q1.2 (E), R40.2, R41.1
LCD_LEDA: J2.1, Q1.3 (C)
LCD_MOSI: J2.14; also elsewhere on the board
LCD_RESET_N: J2.9; also elsewhere on the board
LCD_SCLK: J2.11; also elsewhere on the board

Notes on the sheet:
参考 TFT024B579-B0：30P / 0.5mm / 下接 FPC，4 线 SPI。 不是 ATK-MD0240 的 29 针裸屏。屏幕采购、排线厚度和机械图仍需确认。 不使用触摸；背光电流按原厂屏幕规格复核后才能冻结。

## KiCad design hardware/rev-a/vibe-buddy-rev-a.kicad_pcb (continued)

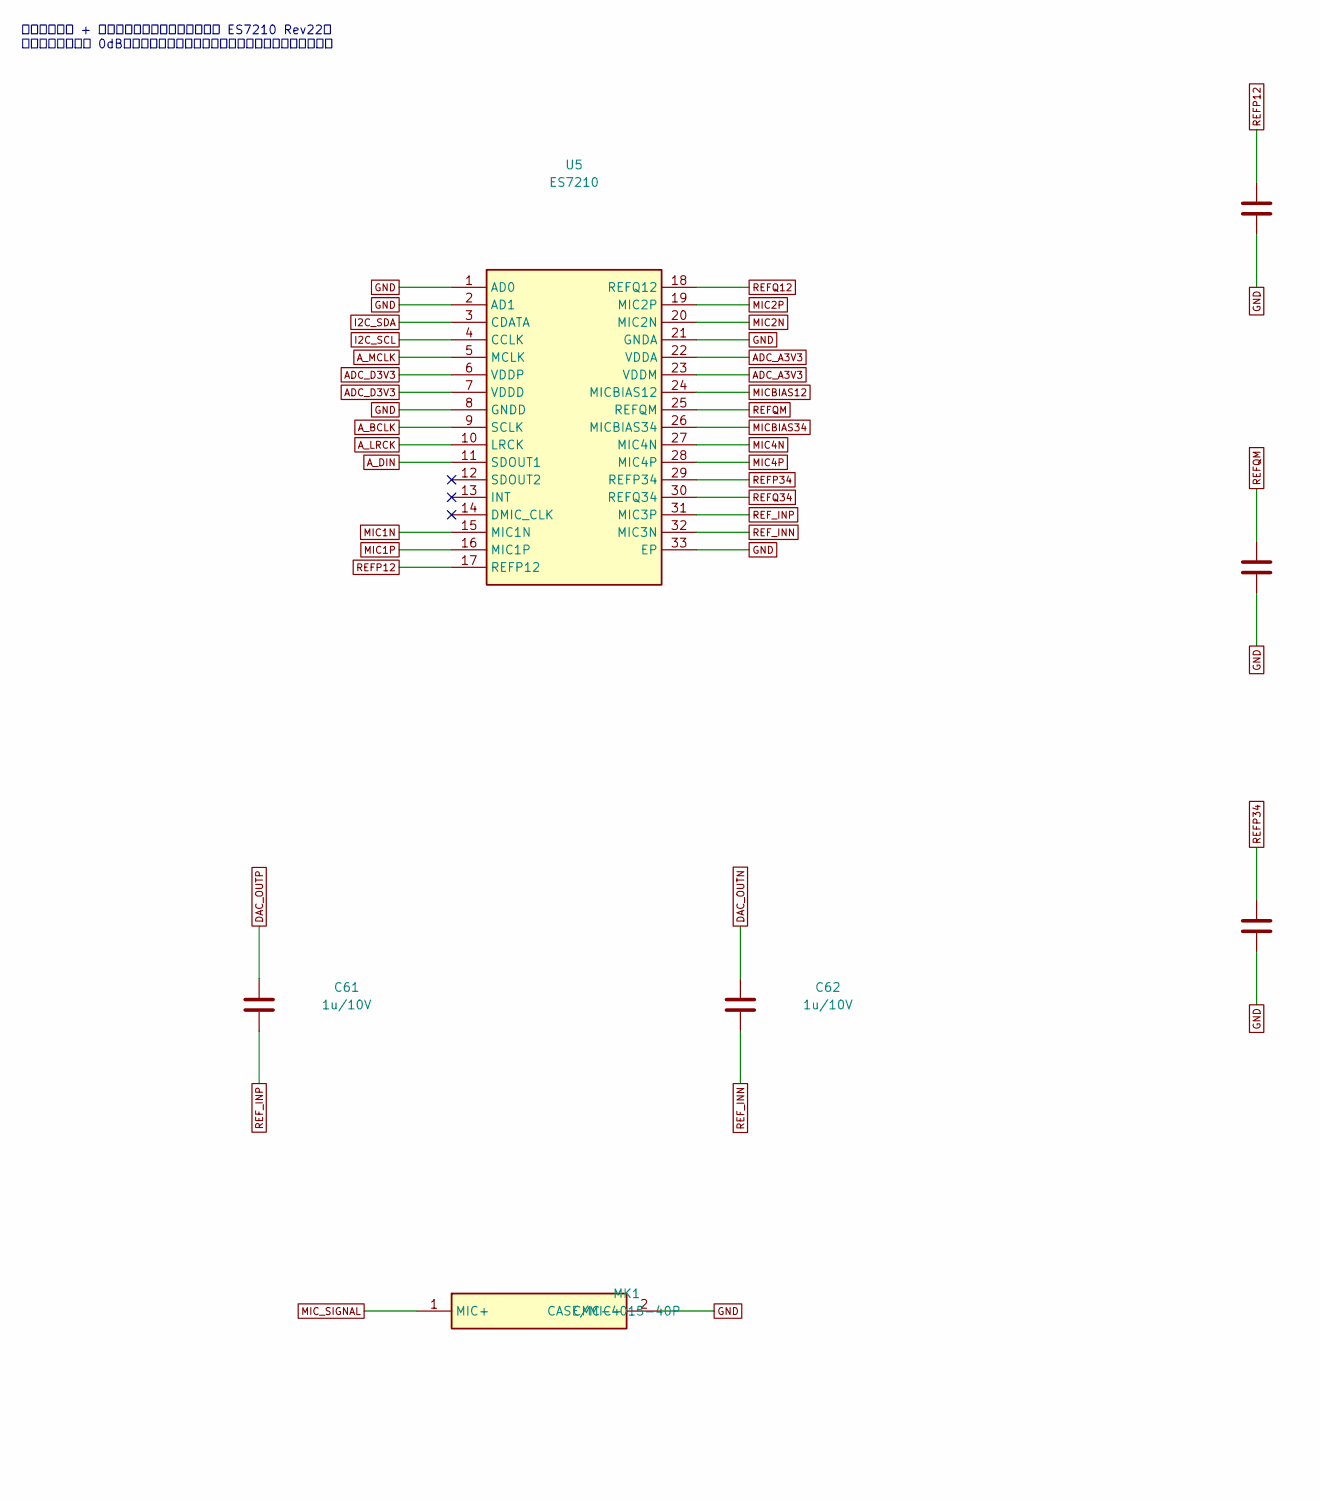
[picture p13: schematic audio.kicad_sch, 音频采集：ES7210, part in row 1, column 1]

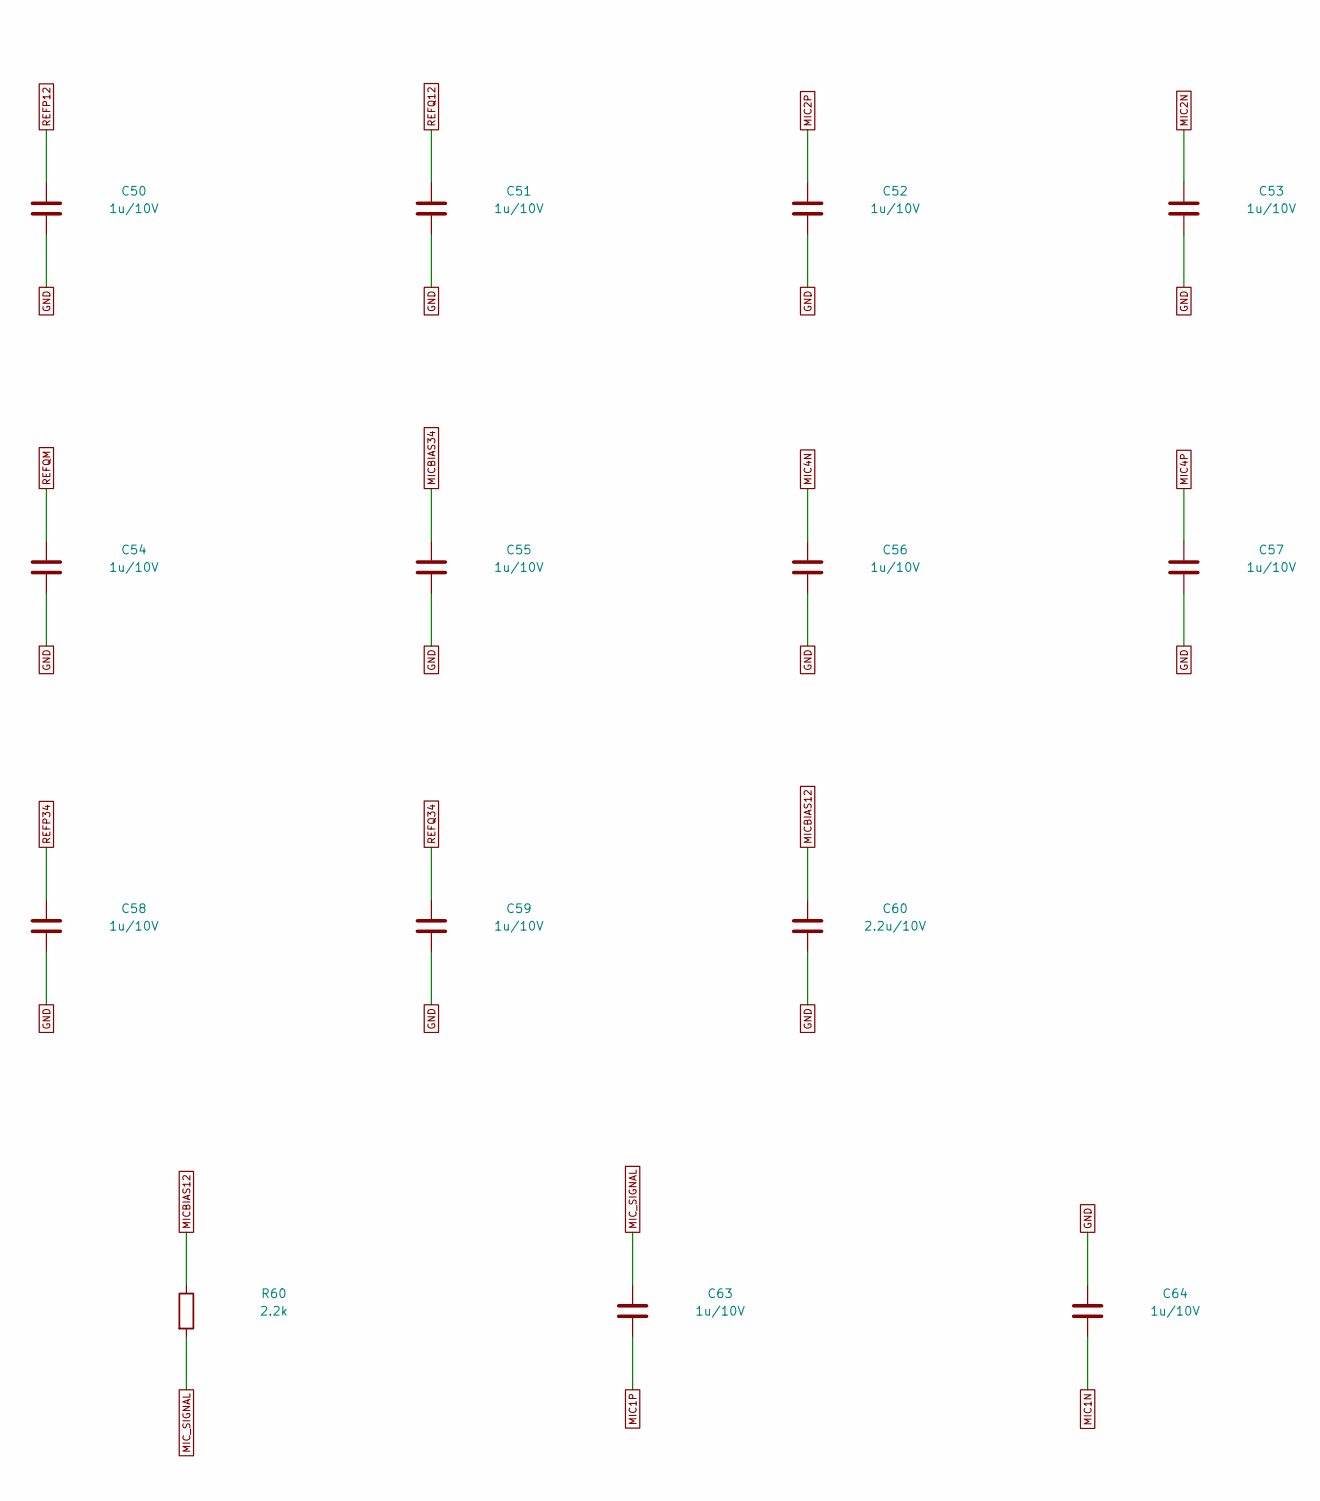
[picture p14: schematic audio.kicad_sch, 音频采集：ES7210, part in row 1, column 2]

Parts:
C50, C51, C52, C53, C54, C55, C56, C57, C58, C59, C61, C62, C63, C64: 1u/10V; C_0603_1608Metric
C60: 2.2u/10V; C_0603_1608Metric
MK1: CMC-4015-40P; MPN CMC-4015-40P
R60: 2.2k; R_0603_1608Metric
U5: ES7210; VQFN-32-1EP_4x4mm_P0.4mm_EP2.8x2.8mm; MPN ES7210

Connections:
ADC_A3V3: U5.22 (VDDA), U5.23 (VDDM); also elsewhere on the board
ADC_D3V3: U5.6 (VDDP), U5.7 (VDDD); also elsewhere on the board
A_BCLK: U5.9 (SCLK); also elsewhere on the board
A_DIN: U5.11 (SDOUT1); also elsewhere on the board
A_LRCK: U5.10 (LRCK); also elsewhere on the board
A_MCLK: U5.5 (MCLK); also elsewhere on the board
DAC_OUTN: C62.1; also elsewhere on the board
DAC_OUTP: C61.1; also elsewhere on the board
GND: C50.2, C51.2, C52.2, C53.2, C54.2, C55.2, C56.2, C57.2, C58.2, C59.2, C60.2, C64.1, MK1.2 (CASE/MIC-), U5.1 (AD0), U5.2 (AD1), U5.8 (GNDD), U5.21 (GNDA), U5.33 (EP); also elsewhere on the board
I2C_SCL: U5.4 (CCLK); also elsewhere on the board
I2C_SDA: U5.3 (CDATA); also elsewhere on the board
MIC1N: C64.2, U5.15 (MIC1N)
MIC1P: C63.2, U5.16 (MIC1P)
MIC2N: C53.1, U5.20 (MIC2N)
MIC2P: C52.1, U5.19 (MIC2P)
MIC4N: C56.1, U5.27 (MIC4N)
MIC4P: C57.1, U5.28 (MIC4P)
MICBIAS12: C60.1, R60.1, U5.24 (MICBIAS12)
MICBIAS34: C55.1, U5.26 (MICBIAS34)
MIC_SIGNAL: C63.1, MK1.1 (MIC+), R60.2
REFP12: C50.1, U5.17 (REFP12)
REFP34: C58.1, U5.29 (REFP34)
REFQ12: C51.1, U5.18 (REFQ12)
REFQ34: C59.1, U5.30 (REFQ34)
REFQM: C54.1, U5.25 (REFQM)
REF_INN: C62.2, U5.32 (MIC3N)
REF_INP: C61.2, U5.31 (MIC3P)

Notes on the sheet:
单模拟麦克风 + 功放前播放参考。原理图引脚按 ES7210 Rev22。 参考通道初始增益 0dB，避免与麦克风高增益混用；固件需配置双通道时序。

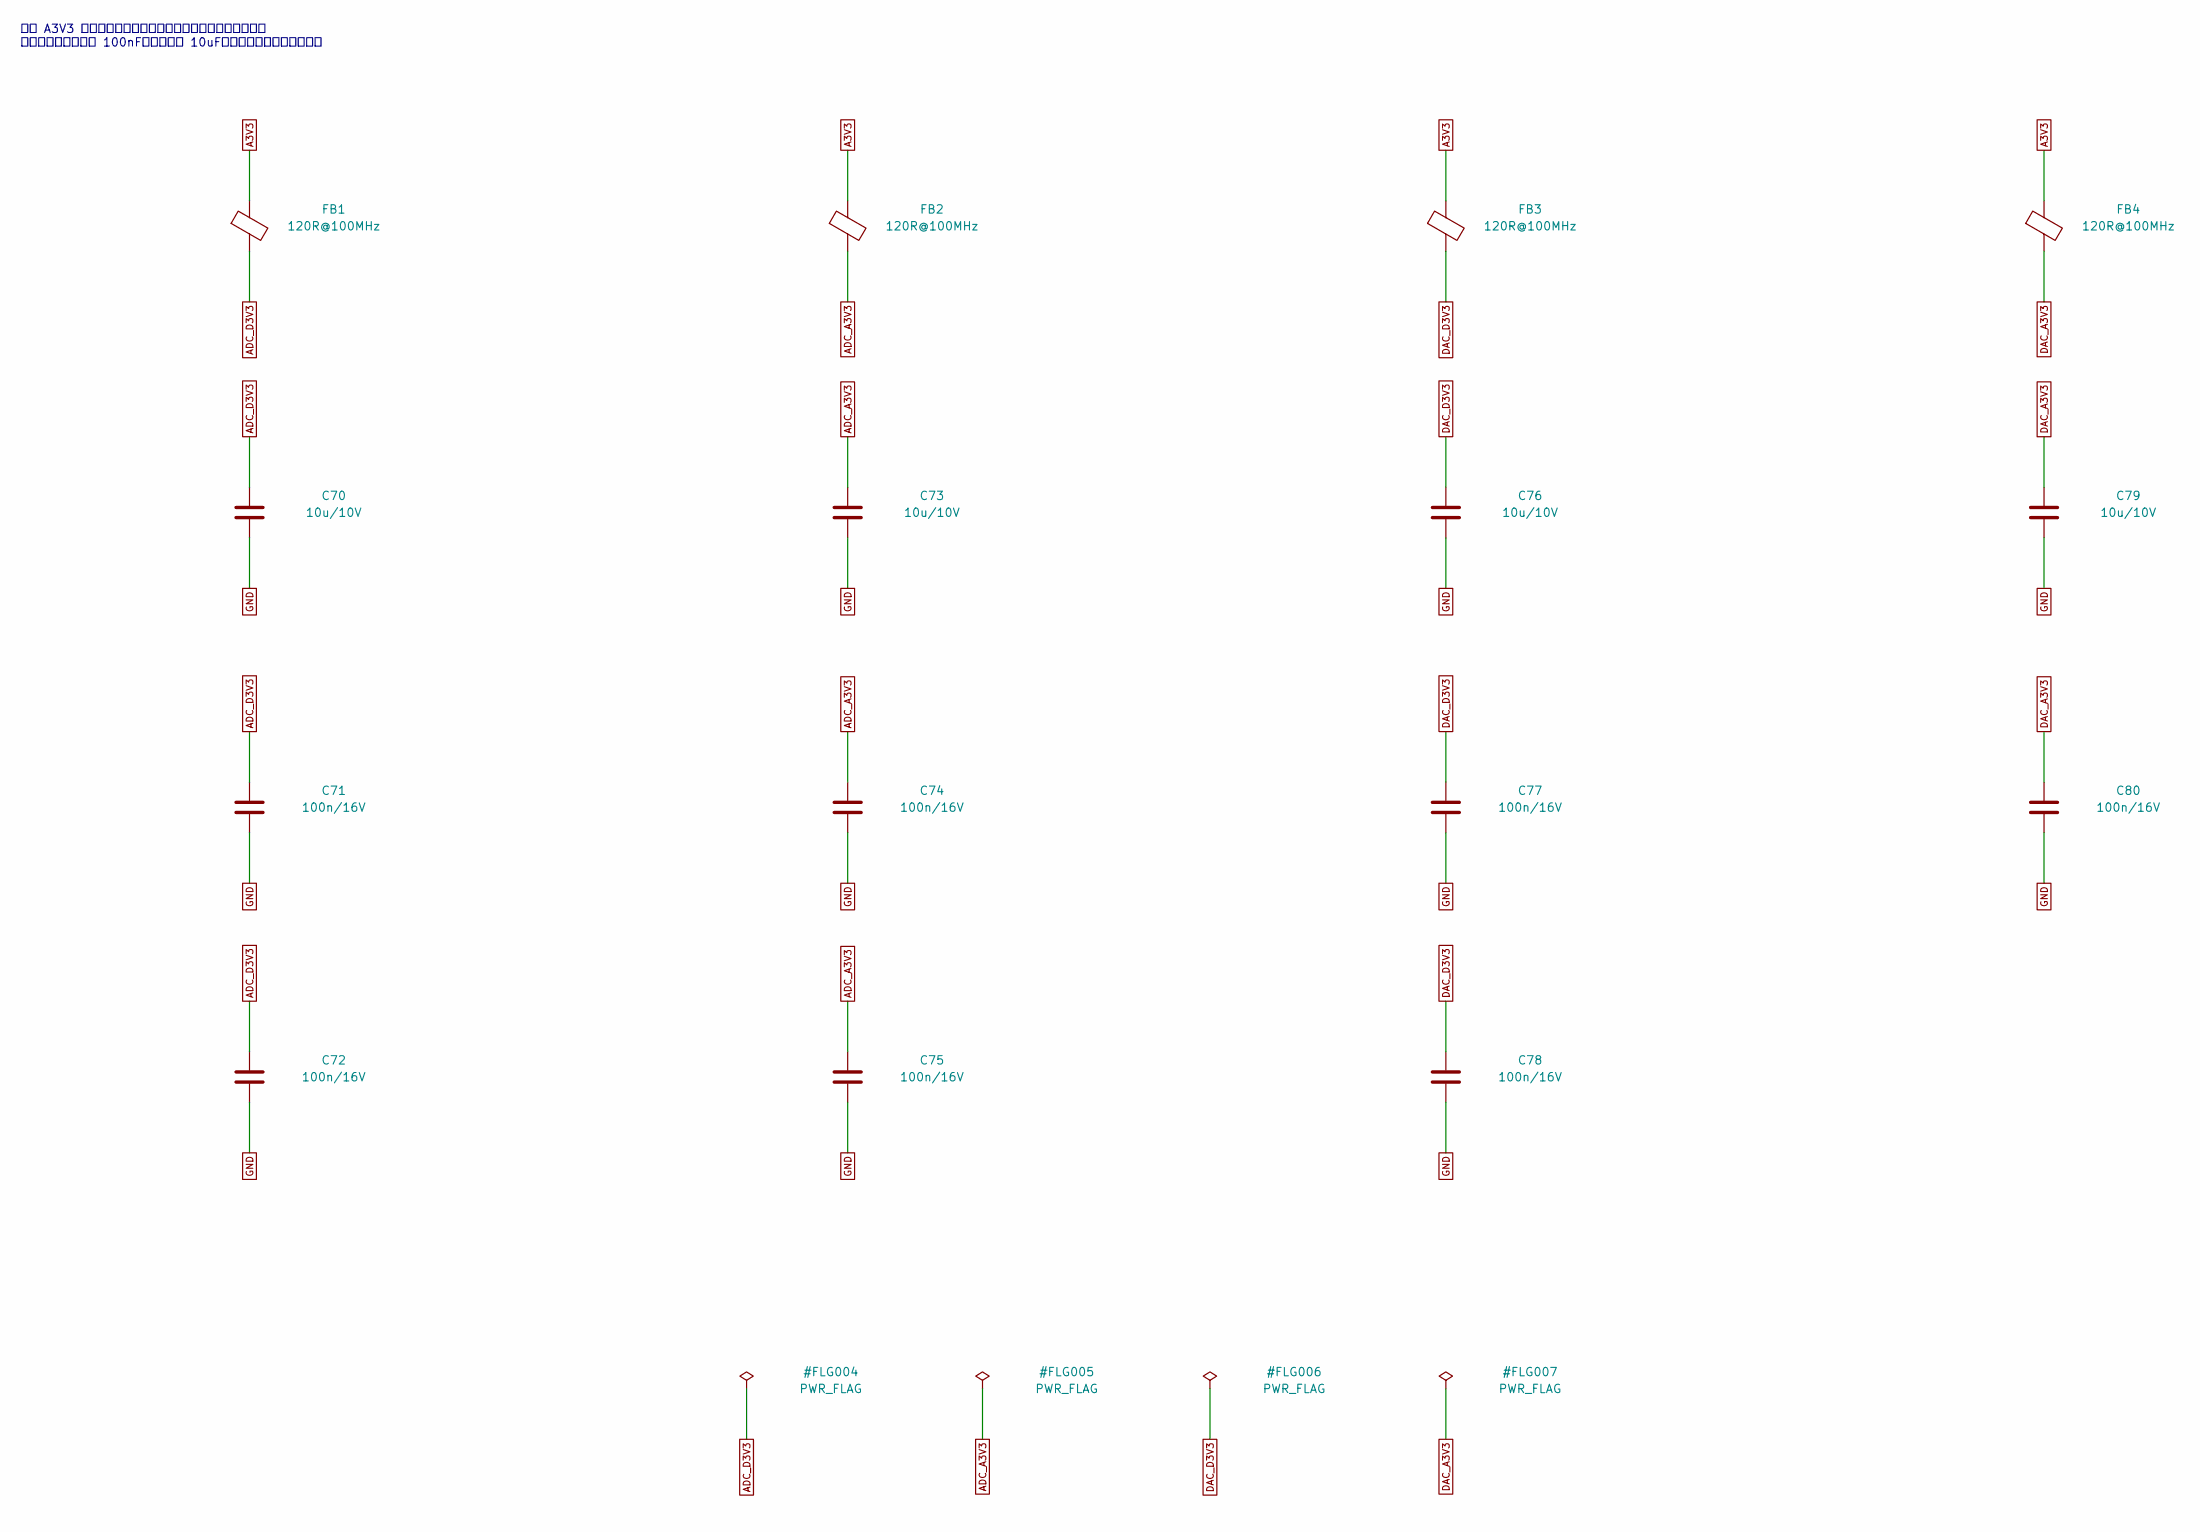
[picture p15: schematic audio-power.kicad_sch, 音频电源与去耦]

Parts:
C70, C73, C76, C79: 10u/10V; C_0805_2012Metric
C71, C72, C74, C75, C77, C78, C80: 100n/16V; C_0603_1608Metric
FB1, FB2, FB3, FB4: 120R@100MHz; L_0603_1608Metric; MPN BLM18PG121SN1D

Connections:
A3V3: FB1.1, FB2.1, FB3.1, FB4.1; also elsewhere on the board
ADC_A3V3: C73.1, C74.1, C75.1, FB2.2; also elsewhere on the board
ADC_D3V3: C70.1, C71.1, C72.1, FB1.2; also elsewhere on the board
DAC_A3V3: C79.1, C80.1, FB4.2; also elsewhere on the board
DAC_D3V3: C76.1, C77.1, C78.1, FB3.2; also elsewhere on the board
GND: C70.2, C71.2, C72.2, C73.2, C74.2, C75.2, C76.2, C77.2, C78.2, C79.2, C80.2; also elsewhere on the board

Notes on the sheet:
独立 A3V3 经磁珠分域；保持完整地平面，不将地切成孤岛。 每个音频电源脚就近 100nF；各域另有 10uF。封装与布局复核后发布。

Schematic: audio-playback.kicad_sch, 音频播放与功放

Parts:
C90, C91, C92, C93, C94: 2.2u/10V; C_0603_1608Metric
C95: 1u/10V; C_0603_1608Metric
C96: 10u/10V; C_0805_2012Metric
C97: 100n/16V; C_0603_1608Metric
FB5: 120R@100MHz; L_0603_1608Metric; MPN BLM18PG121SN1D
J3: 扬声器 4R/2W; JST_PH_B2B-PH-K_1x02_P2.00mm_Vertical; MPN B2B-PH-K-S
R61, R62: 30k; R_0603_1608Metric
R63: 100k; R_0603_1608Metric
U6: ES8311; VQFN-20-1EP_3x3mm_P0.4mm_EP1.7x1.7mm; MPN ES8311
U7: NS4150B; MSOP-8_3x3mm_P0.65mm; MPN NS4150B

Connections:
3V3: FB5.1; also elsewhere on the board
ADCVREF: C91.1, U6.15 (ADCVREF)
A_BCLK: U6.6 (SCLK); also elsewhere on the board
A_DOUT: U6.9 (DSDIN); also elsewhere on the board
A_LRCK: U6.8 (LRCK); also elsewhere on the board
A_MCLK: U6.2 (MCLK); also elsewhere on the board
DACVREF: C90.1, U6.14 (DACVREF)
DAC_A3V3: U6.11 (AVDD); also elsewhere on the board
DAC_D3V3: U6.3 (PVDD), U6.4 (DVDD); also elsewhere on the board
DAC_OUTN: C94.1, U6.13 (OUTN); also elsewhere on the board
DAC_OUTP: C93.1, U6.12 (OUTP); also elsewhere on the board
GND: C90.2, C91.2, C92.2, C95.2, C96.2, C97.2, R63.2, U6.5 (DGND), U6.10 (AGND), U6.20 (CE), U6.21 (EP), U7.7 (GND); also elsewhere on the board
I2C_SCL: U6.1 (CCLK); also elsewhere on the board
I2C_SDA: U6.19 (CDATA); also elsewhere on the board
PA_3V3: C96.1, C97.1, FB5.2, U7.6 (VCC)
PA_ACN: C94.2, R62.1
PA_ACP: C93.2, R61.1
PA_BYPASS: C95.1, U7.2 (BYPASS)
PA_EN: R63.1, U7.1 (CTRL); also elsewhere on the board
PA_INN: R62.2, U7.4 (INN)
PA_INP: R61.2, U7.3 (INP)
SPK_N: J3.2, U7.5 (VoN)
SPK_P: J3.1, U7.8 (VoP)
VMID: C92.1, U6.16 (VMID)

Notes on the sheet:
ES8311 输出分支：送 ES7210 采集播放参考，另经耦合电容和电阻到功放。 功放采用稳压 3V3，不直接连接 USB VBUS；PA_EN 下拉，默认关闭。 扬声器两端都是驱动输出，负端不能接地。
外接扬声器候选 CES-28266-24-L200；配线束/端子另确认。

Board: 4 copper layers, 109 parts (0 on the bottom side), 78 nets, no tracks yet.

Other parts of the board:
H1, H2, H3, H4: M2; MountingHole_2.2mm_M2

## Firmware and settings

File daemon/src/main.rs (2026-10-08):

mod activity;
mod ci;
mod claude_hooks;
mod codex_hooks;
mod config;
mod rom_flasher;
mod screenshot;
mod serial_transport;
mod session_titles;
mod source_opener;
mod status;
mod voice_writer;

use std::convert::Infallible;
use std::env;
use std::net::SocketAddr;
use std::path::PathBuf;
use std::sync::Arc;
use std::time::Duration;

use activity::{ActivitySource, ActivityTracker};
use axum::body::Bytes;
use axum::extract::{DefaultBodyLimit, State};
use axum::http::StatusCode;
use axum::response::sse::{Event as SseEvent, KeepAlive, Sse};
use axum::routing::{get, post};
use axum::{Json, Router};
use vibebuddy_protocol::{Event, VERSION};
use chrono::Timelike;
use ci::CiWatcher;
use claude_hooks::ClaudeHook;
use codex_hooks::CodexHook;
use config::Config;
use serde::Serialize;
use serial_transport::{DeviceMessage, SerialConfig, SerialTransport, Transport, TransportError};
use session_titles::SessionTitles;
use status::{DaemonInfo, DeviceState, HooksSeen, Operation, OperationKind, OperationState, Status};
use tokio::sync::{Mutex, broadcast};
use tokio_stream::StreamExt;
use tokio_stream::wrappers::BroadcastStream;
use tracing::{info, warn};
use tracing_subscriber::EnvFilter;

/// 最后一个会话僵死后不会再有 Hook 事件，只能靠定时扫描释放画面。
const SWEEP_INTERVAL: Duration = Duration::from_secs(60);
/// 心跳间隔。设备按这个节奏判断链路是否还活着，固件的超时是它的三倍。
const HEARTBEAT_INTERVAL: Duration = Duration::from_secs(5);
/// 构建时的 git 描述，由 `build.rs` 写入。
const BUILD_REVISION: &str = env!("VIBEBUDDY_BUILD");

#[derive(Clone)]
struct AppState {
    transport: Arc<dyn Transport>,
    /// 所有 Agent 共享一个聚合器：设备只有一块屏幕和一只小灯灵。
    activities: Arc<Mutex<ActivityTracker>>,
    /// 会话标题的查询与缓存：Claude App 的会话标题、Codex 的线程名。
    titles: Arc<Mutex<SessionTitles>>,
    /// 设备此刻的样子，从诊断行里拼出来。
    device: Arc<Mutex<DeviceState>>,
    hooks_seen: Arc<Mutex<HooksSeen>>,
    config: Arc<Mutex<Config>>,
    config_path: Option<PathBuf>,
    /// 正在写语音包或烧固件；同一时刻只有一个。
    operation: Arc<Mutex<Option<Operation>>>,
    /// 设备消息的广播：写语音包、截图这些要等回执的操作各自订阅。
    device_bus: broadcast::Sender<DeviceMessage>,
    /// 状态变了就叫一声，状态流据此推一份新快照。
    status_changed: broadcast::Sender<()>,
    /// App 的版本，随心跳报给设备；没有 App 时为 None。
    app_version: Option<String>,
    /// 真正的串口 worker，烧固件时要让它让出端口；测试里没有。
    serial: Option<Arc<SerialTransport>>,
}

impl AppState {
    fn new(
        transport: Arc<dyn Transport>,
        activities: ActivityTracker,
        titles: SessionTitles,
        config_path: Option<PathBuf>,
    ) -> Self {
        let config = config_path
            .as_deref()
            .map(Config::load)
            .unwrap_or_default();
        let (device_bus, _) = broadcast::channel(1024);
        let (status_changed, _) = broadcast::channel(64);
        Self {
            transport,
            activities: Arc::new(Mutex::new(activities)),
            titles: Arc::new(Mutex::new(titles)),
            device: Arc::new(Mutex::new(DeviceState::default())),
            hooks_seen: Arc::new(Mutex::new(HooksSeen::default())),
            config: Arc::new(Mutex::new(config)),
            config_path,
            operation: Arc::new(Mutex::new(None)),
            device_bus,
            status_changed,
            app_version: env::var("VIBEBUDDY_APP_VERSION").ok().filter(|value| !value.is_empty()),
            serial: None,
        }
    }

    fn notify_status(&self) {
        let _ = self.status_changed.send(());
    }

    async fn snapshot(&self) -> Status {
        Status {
            daemon: DaemonInfo {
                build: build_identity(self.app_version.as_deref()),
                app_version: self.app_version.clone(),
            },
            device: self.device.lock().await.clone(),
            today: self.activities.lock().await.today(),
            hooks: self.hooks_seen.lock().await.clone(),
            operation: self.operation.lock().await.clone(),
            config: self.config.lock().await.clone(),
        }
    }

    async fn set_operation(&self, operation: Option<Operation>) {
        *self.operation.lock().await = operation;
        self.notify_status();
    }

    async fn save_config(&self, change: impl FnOnce(&mut Config)) {
        let snapshot = {
            let mut config = self.config.lock().await;
            change(&mut config);
            config.clone()
        };
        if let Some(path) = &self.config_path
            && let Err(error) = snapshot.save(path)
        {
            warn!(%error, path = %path.display(), "配置保存失败");
        }
        self.notify_status();
    }
}

#[derive(Serialize)]
struct ApiResponse {
    accepted: bool,
    message: String,
}

#[tokio::main]
async fn main() {
    let log_filter = env::var("RUST_LOG")
        .ok()
        .filter(|value| !value.trim().is_empty())
        .and_then(|value| EnvFilter::try_new(value).ok())
        .unwrap_or_else(|| EnvFilter::new("vibebuddyd=info"));
    tracing_subscriber::fmt().with_env_filter(log_filter).init();

    let bind_address = env::var("VIBEBUDDY_BIND")
        .unwrap_or_else(|_| "127.0.0.1:7331".to_owned())
        .parse::<SocketAddr>()
        .unwrap_or_else(|error| panic!("VIBEBUDDY_BIND 无效：{error}"));
    let serial_config = SerialConfig::from_env();
    let (serial_transport, device_events) = SerialTransport::spawn(serial_config);
    let serial_transport = Arc::new(serial_transport);
    let transport: Arc<dyn Transport> = serial_transport.clone();
    let activities = match stats_file() {
        Some(path) => ActivityTracker::with_stats_file(path),
        None => ActivityTracker::default(),
    };
    let mut state = AppState::new(
        transport,
        activities,
        SessionTitles::from_home(),
        config::config_file(),
    );
    state.serial = Some(serial_transport);
    tokio::spawn(watch_parent());
    tokio::spawn(sweep_expired_activities(state.clone()));
    tokio::spawn(send_heartbeats(state.clone()));
    tokio::spawn(poll_ci(state.clone()));
    tokio::spawn(handle_device_events(state.clone(), device_events));
    let app = app(state);
    let listener = tokio::net::TcpListener::bind(bind_address)
        .await
        .unwrap_or_else(|error| panic!("无法监听 {bind_address}：{error}"));

    info!(address = %bind_address, "vibebuddyd 已启动");
    axum::serve(listener, app)
        .await
        .unwrap_or_else(|error| panic!("HTTP server 失败：{error}"));
}

/// 设备到 Mac 的事件目前只开放 K2 单击。优先打开当前活动；空闲时返回最近
/// 一次可定位的 Agent/CI 来源。
async fn handle_device_events(
    state: AppState,
    mut events: tokio::sync::mpsc::Receiver<DeviceMessage>,
) {
    while let Some(message) = events.recv().await {
        publish_device_message(&state, message).await;
    }
}

/// 每条设备消息都走这里：更新设备状态、广播给等回执的操作，K2 则去开来源。
/// 测试也从这里注入设备消息，所以它不能依赖串口。
async fn publish_device_message(state: &AppState, message: DeviceMessage) {
    if state.device.lock().await.apply(&message) {
        state.notify_status();
    }
    let _ = state.device_bus.send(message.clone());
    // 刚连上先问一声，设备会把模式、固件构建号、音色重报一遍。
    if matches!(message, DeviceMessage::Connected { .. }) {
        send_event(state, device_command("device.hello"));
    }
    let DeviceMessage::Event(event) = message else {
        return;
    };
    if is_k2_press(&event) {
        open_k2_source(state).await;
    } else if !event.event.starts_with("voice.") && event.event != "echo" {
        info!(event = %event.event, "忽略未绑定的设备事件");
    }
}

async fn open_k2_source(state: &AppState) {
    {
        let sources = state.activities.lock().await.focus_sources();
        if sources.is_empty() {
            info!("K2 已按下，但当前没有可打开的活动");
            return;
        }
        for source in sources {
            // Codex 线程要先确认还在：打开一个不存在的线程得到的是空白会话。
            if let ActivitySource::Codex { thread_id } = &source
                && state.titles.lock().await.codex_thread_known(thread_id) == Some(false)
            {
                warn!(%thread_id, "K2 跳过不存在的 Codex 线程");
                continue;
            }
            match source_opener::open(source).await {
                // 记下链接本身：跳错地方时，日志要能直接说出跳去了哪儿。
                Ok(link) => {
                    info!(%link, "K2 已打开当前活动来源");
                    break;
                }
                Err(error) => warn!(%error, "K2 打开来源失败，试下一个候选"),
            }
        }
    }
}

fn is_k2_press(event: &Event) -> bool {
    event.event == "button"
        && event.extra.get("button").and_then(|value| value.as_str()) == Some("K2")
        && event.extra.get("action").and_then(|value| value.as_str()) == Some("press")
}

/// App 看管时它把自己的 pid 放在 VIBEBUDDY_PARENT_PID 里。App 被强杀后 daemon
/// 会被 launchd 收养，父 pid 变成 1；那就跟着退出，别占着串口和端口等下一个
/// App 起不来。macOS 没有 prctl(PR_SET_PDEATHSIG)，只能轮询。
async fn watch_parent() {
    let Some(expected) = env::var("VIBEBUDDY_PARENT_PID")
        .ok()
        .and_then(|value| value.parse::<u32>().ok())
    else {
        return;
    };
    let mut ticker = tokio::time::interval(Duration::from_secs(2));
    loop {
        ticker.tick().await;
        if std::os::unix::process::parent_id() != expected {
            info!(expected, "看管我的 App 已经不在，跟着退出");
            std::process::exit(0);
        }
    }
}

/// daemon 的构建标识：git 描述加上二进制自己的时间戳。
///
/// 时间戳取可执行文件的 mtime，不用编译期常量。`build.rs` 只在它声明的依赖
/// 变化时才重跑；改一行源码重新链接时，编译期写下的时刻不会更新，正好在你
/// 最需要它准的时候骗你。
fn build_identity(app_version: Option<&str>) -> String {
    let built = std::env::current_exe()
        .and_then(|path| path.metadata())
        .and_then(|metadata| metadata.modified())
        .ok()
        .map(|time| {
            chrono::DateTime::<chrono::Local>::from(time)
                .format("%Y-%m-%d %H:%M")
                .to_string()
        })
        .unwrap_or_default();
    build_identity_from(app_version, BUILD_REVISION, &built)
}

/// App 在时它的版本号排最前：设备页脚那一行就是 App 版本加构建号。
fn build_identity_from(app_version: Option<&str>, revision: &str, built: &str) -> String {
    let mut parts = Vec::new();
    if let Some(version) = app_version {
        parts.push(version);
    }
    parts.push(revision);
    parts.push(built);
    parts.join(" ").trim_end().to_owned()
}

/// 当日战绩的存放位置。缺少 `HOME` 时退回内存计数，不让 daemon 起不来。
fn stats_file() -> Option<PathBuf> {
    if let Ok(path) = env::var("VIBEBUDDY_STATS_FILE") {
        return Some(PathBuf::from(path));
    }
    let home = env::var("HOME").ok()?;
    Some(PathBuf::from(home).join("Library/Application Support/VibeBuddy/stats.json"))
}

fn app(state: AppState) -> Router {
    Router::new()
        .route("/v1/events", post(post_event))
        .route("/v1/codex-hooks", post(post_codex_hook))
        .route("/v1/claude-hooks", post(post_claude_hook))
        .route("/v1/status", get(get_status))
        .route("/v1/status/stream", get(status_stream))
        .route("/v1/config", get(get_config).put(put_config))
        .route("/v1/device/identify", post(post_identify))
        .route("/v1/device/volume", post(post_volume))
        .route(
            "/v1/device/voice-pack",
            post(post_voice_pack).layer(DefaultBodyLimit::max(4 * 1024 * 1024)),
        )
        .route("/v1/device/screenshot", post(post_screenshot))
        .route("/v1/device/firmware", post(post_firmware))
        .route("/v1/daemon/restart", post(post_restart))
        .with_state(state)
}

/// 截一张盒子当前画面，回 PNG。写语音包或烧固件时不截：截图行会挤掉回执。
async fn post_screenshot(State(state): State<AppState>) -> axum::response::Response {
    use axum::response::IntoResponse;
    if matches!(&*state.operation.lock().await, Some(current) if current.state == OperationState::Running) {
        return (StatusCode::CONFLICT, "设备上有操作在进行").into_response();
    }
    let bus = state.device_bus.subscribe();
    match screenshot::capture(state.transport.clone(), bus).await {
        Ok(frame) => match screenshot::encode_png(&frame) {
            Ok(png) => ([(axum::http::header::CONTENT_TYPE, "image/png")], png).into_response(),
            Err(error) => (StatusCode::INTERNAL_SERVER_ERROR, error).into_response(),
        },
        Err(error) => (StatusCode::BAD_GATEWAY, error).into_response(),
    }
}

async fn get_status(State(state): State<AppState>) -> Json<Status> {
    Json(state.snapshot().await)
}

/// SSE：连上先推一份，之后状态一变再推一份完整快照。
async fn status_stream(
    State(state): State<AppState>,
) -> Sse<impl tokio_stream::Stream<Item = Result<SseEvent, Infallible>>> {
    let changes = BroadcastStream::new(state.status_changed.subscribe()).map(|_| ());
    let stream = tokio_stream::once(()).chain(changes).then(move |()| {
        let state = state.clone();
        async move {
            let status = state.snapshot().await;
            let data = serde_json::to_string(&status).unwrap_or_default();
            Ok(SseEvent::default().event("status").data(data))
        }
    });
    Sse::new(stream).keep_alive(KeepAlive::default())
}

async fn get_config(State(state): State<AppState>) -> Json<Config> {
    Json(state.config.lock().await.clone())
}

async fn put_config(State(state): State<AppState>, Json(config): Json<Config>) -> Json<Config> {
    state.save_config(|current| *current = config).await;
    Json(state.config.lock().await.clone())
}

fn device_command(name: &str) -> Event {
    Event::named(name)
}

/// 设备上同一时刻只能有一个操作：占上位就返回 None，否则回给调用方 409。
async fn begin_operation(
    state: &AppState,
    kind: OperationKind,
    message: String,
) -> Option<(StatusCode, Json<ApiResponse>)> {
    let mut operation = state.operation.lock().await;
    if matches!(&*operation, Some(current) if current.state == OperationState::Running) {
        return Some((
            StatusCode::CONFLICT,
            Json(ApiResponse { accepted: false, message: "设备上已有操作在进行".to_owned() }),
        ));
    }
    *operation = Some(Operation { kind, state: OperationState::Running, progress: 0.0, message });
    drop(operation);
    state.notify_status();
    None
}

/// 从阻塞线程或写入循环里报进度。只在操作还在跑时写：完成后迟到的回调
/// 不能把 100% 改回去。
fn report_progress(state: &AppState, fraction: f32, message: Option<String>) {
    let state = state.clone();
    tokio::spawn(async move {
        if let Some(operation) = state.operation.lock().await.as_mut()
            && operation.state == OperationState::Running
        {
            operation.progress = fraction;
            if let Some(message) = message {
                operation.message = message;
            }
        }
        state.notify_status();
    });
}

async fn post_identify(State(state): State<AppState>) -> (StatusCode, Json<ApiResponse>) {
    post_event(State(state), Json(device_command("device.identify"))).await
}

/// 与固件 `AGENT_AUDIO_VOLUME_MIN/MAX` 一致：下限不到零，静音另有按键且不持久化。
const VOLUME_RANGE: std::ops::RangeInclusive<u8> = 20..=100;

#[derive(serde::Deserialize)]
struct VolumeRequest {
    level: u8,
    /// 让盒子用新音量播一句"任务完成"，滑块才不是盲调。
    #[serde(default)]
    preview: bool,
}

/// 调音量：越界直接拒绝而不是替用户改数。设备应用后回 `VOLUME` 行，
/// 状态里的音量随之更新，App 显示的始终是盒子上的值。
async fn post_volume(
    State(state): State<AppState>,
    Json(request): Json<VolumeRequest>,
) -> (StatusCode, Json<ApiResponse>) {
    if !VOLUME_RANGE.contains(&request.level) {
        return (
            StatusCode::BAD_REQUEST,
            Json(ApiResponse {
                accepted: false,
                message: format!("音量要在 {} 到 {} 之间", VOLUME_RANGE.start(), VOLUME_RANGE.end()),
            }),
        );
    }
    let mut event = device_command("device.volume");
    event.extra.insert("level".to_owned(), request.level.into());
    if request.preview {
        event.extra.insert("preview".to_owned(), true.into());
    }
    post_event(State(state), Json(event)).await
}

/// 写语音包：请求体就是包本身。写入在后台跑，进度在状态流里。
async fn post_voice_pack(
    State(state): State<AppState>,
    body: Bytes,
) -> (StatusCode, Json<ApiResponse>) {
    let Some(voice) = voice_writer::voice_id_of(&body) else {
        return (
            StatusCode::BAD_REQUEST,
            Json(ApiResponse { accepted: false, message: "请求体不是语音包".to_owned() }),
        );
    };
    if let Some(refused) = begin_operation(&state, OperationKind::VoicePack, format!("正在写入 {voice}")).await {
        return refused;
    }
    let bus = state.device_bus.subscribe();
    let pack = body.to_vec();
    let task_state = state.clone();
    tokio::spawn(async move {
        let progress_state = task_state.clone();
        let result = voice_writer::write_pack(task_state.transport.clone(), bus, pack, move |fraction| {
            report_progress(&progress_state, fraction, None);
        })
        .await;
        match result {
            Ok(written) => {
                info!(voice = %written, "语音包已写入设备");
                task_state.save_config(|config| config.voice = Some(written.clone())).await;
                task_state
                    .set_operation(Some(Operation {
                        kind: OperationKind::VoicePack,
                        state: OperationState::Done,
                        progress: 1.0,
                        message: format!("已写入 {written}"),
                    }))
                    .await;
            }
            Err(error) => {
                warn!(%error, "语音包写入失败");
                task_state
                    .set_operation(Some(Operation {
                        kind: OperationKind::VoicePack,
                        state: OperationState::Failed,
                        progress: 0.0,
                        message: error,
                    }))
                    .await;
            }
        }
    });
    (
        StatusCode::ACCEPTED,
        Json(ApiResponse { accepted: true, message: format!("开始写入 {voice}") }),
    )
}

#[derive(serde::Deserialize)]
struct FirmwareRequest {
    #[serde(default)]
    board: Option<String>,
    bootloader: PathBuf,
    partition_table: PathBuf,
    app: PathBuf,
}

/// 烧固件：三件套的路径由 App 给出（都在它的包里）。串口 worker 让出端口，
/// ROM 协议逐段写并校验，完了硬复位、worker 重连。进度走状态流。
async fn post_firmware(
    State(state): State<AppState>,
    Json(request): Json<FirmwareRequest>,
) -> (StatusCode, Json<ApiResponse>) {
    let mut segments = Vec::new();
    for (address, path) in [(0x0_u32, &request.bootloader), (0x8000, &request.partition_table), (0x10000, &request.app)] {
        match std::fs::read(path) {
            Ok(data) if !data.is_empty() => segments.push(rom_flasher::Segment { address, data }),
            _ => {
                return (
                    StatusCode::BAD_REQUEST,
                    Json(ApiResponse { accepted: false, message: format!("读不到固件文件 {}", path.display()) }),
                );
            }
        }
    }
    let (port, bridge) = {
        let device = state.device.lock().await;
        // 旧 App 的请求没有板型，只兼容原 BOX。新板禁止误刷旧包。
        let requested_board = request.board.as_deref().unwrap_or("alientek-box");
        if device.board.as_deref().unwrap_or("alientek-box") != requested_board {
            return (
                StatusCode::CONFLICT,
                Json(ApiResponse { accepted: false, message: "固件板型与连接设备不匹配".to_owned() }),
            );
        }
        match &device.port {
            Some(port) if device.connected => (port.clone(), device.bridge),
            _ => {
                return (
                    StatusCode::CONFLICT,
                    Json(ApiResponse { accepted: false, message: "没有连着的盒子".to_owned() }),
                );
            }
        }
    };
    let Some(serial) = state.serial.clone() else {
        return (
            StatusCode::NOT_IMPLEMENTED,
            Json(ApiResponse { accepted: false, message: "没有串口 worker".to_owned() }),
        );
    };
    if let Some(refused) = begin_operation(&state, OperationKind::Firmware, "让出串口".to_owned()).await {
        return refused;
    }
    let task_state = state.clone();
    tokio::spawn(async move {
        serial.set_suspended(true);
        // 等 worker 真把端口放掉。
        tokio::time::sleep(Duration::from_millis(800)).await;
        let progress_state = task_state.clone();
        let result = tokio::task::spawn_blocking(move || {
            let mut report = |fraction: f32, message: &str| {
                report_progress(&progress_state, fraction, Some(message.to_owned()));
            };
            rom_flasher::flash(&port, bridge, &segments, &mut report)
        })
        .await
        .unwrap_or_else(|error| Err(format!("烧录任务崩溃：{error}")));
        serial.set_suspended(false);
        let operation = match result {
            Ok(()) => {
                info!("固件已烧录，等设备重启");
                Operation { kind: OperationKind::Firmware, state: OperationState::Done, progress: 1.0, message: "烧录完成，设备重启中".to_owned() }
            }
            Err(error) => {
                warn!(%error, "固件烧录失败");
                Operation { kind: OperationKind::Firmware, state: OperationState::Failed, progress: 0.0, message: error }
            }
        };
        task_state.set_operation(Some(operation)).await;
    });
    (StatusCode::ACCEPTED, Json(ApiResponse { accepted: true, message: "开始烧录".to_owned() }))
}

/// App 看管 daemon：退出即重启。先把响应发出去再退。
async fn post_restart() -> (StatusCode, Json<ApiResponse>) {
    tokio::spawn(async {
        tokio::time::sleep(Duration::from_millis(200)).await;
        info!("按 App 的要求退出，等它重新拉起");
        std::process::exit(0);
    });
    (StatusCode::ACCEPTED, Json(ApiResponse { accepted: true, message: "daemon 即将重启".to_owned() }))
}

/// 定期告诉设备链路还活着。
///
/// 没有心跳时，daemon 崩溃或串口断开后设备会一直显示最后一个状态，
/// 看上去任务仍在进行。状态设备最严重的失败是显示过时状态而不自知。
async fn send_heartbeats(state: AppState) {
    let build = build_identity(state.app_version.as_deref());
    info!(build = %build, "Mac 端构建标识");
    let mut ticker = tokio::time::interval(HEARTBEAT_INTERVAL);
    loop {
        ticker.tick().await;
        let now = chrono::Local::now();
        let heartbeat = heartbeat_event(&build, now.hour(), local_day(&now));
        match heartbeat.to_ndjson() {
            // 队列满意味着设备已经收不到东西，这时心跳没有意义，丢弃即可。
            Ok(frame) => drop(state.transport.send(frame)),
            Err(error) => warn!(%error, "心跳编码失败"),
        }
    }
}
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

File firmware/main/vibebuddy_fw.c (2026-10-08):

#include <stdbool.h>
#include <stddef.h>
#include <stdint.h>
#include <stdio.h>
#include <string.h>

#include "agent_audio.h"
#ifdef AGENT_BOARD_BREADBOARD
#include "agent_mic.h"
#endif
#include "agent_build_stamp.h"
#include "agent_buttons.h"
#include "agent_display.h"
#include "agent_leisure.h"
#include "agent_pomodoro.h"
#include "agent_tally.h"
#include "agent_voice_pack.h"
#include "agent_voices.h"
#include "cJSON.h"
#include "driver/uart.h"
#include "esp_app_desc.h"
#include "driver/usb_serial_jtag.h"
#include "esp_check.h"
#include "esp_random.h"
#include "freertos/FreeRTOS.h"
#include "freertos/task.h"

#define MAX_LINE_BYTES 1024
#define LINE_BUFFER_BYTES (MAX_LINE_BYTES + 2)
#define IO_BUFFER_BYTES 256
/// 串口驱动的接收环形缓冲：语音包的一行接近 1 KB，给它留出几行的余量。
/// 连续长行在 UART 桥上会被冲坏，那是 Mac 端按线速分段发送来解决的，
/// 设备侧的驱动与中断路径已经用直接轮询 FIFO 的对照实验证明无辜。
#define UART_RX_BUFFER_BYTES 4096

static bool ready_scheduled;
static TickType_t ready_deadline;
/// 超过这个时间没有收到任何消息，就认为与 Mac 端失联。
#define LINK_TIMEOUT_MS 15000
static TickType_t last_message_tick;
static bool link_lost;
/// 上一次报给 Mac 端的档位、关灯状态与小时数，只在变化时各报一行。
static agent_leisure_tier_t reported_tier = AGENT_LEISURE_ALERT;
static bool reported_lights_out;
static int reported_hour = -1;

// 两条输出都只是诊断通道，谁都不许拖住主循环。接 BOX 的 UART 桥时，USB
// Serial/JTAG 那头没有主机取数据，tx ring buffer 填满后任何等待都是永久的：
// 主任务停摆，画面定格，失联检测也一起死掉，而 Mac 端的心跳照样写得进串口，
// 两边都看不出设备已经没了。写不进去就丢掉这一段。
static void transport_write_all(const char *data, size_t length) {
  uart_write_bytes(UART_NUM_0, data, length);
  usb_serial_jtag_write_bytes(data, length, 0);
}

static void transport_write_literal(const char *text) {
  transport_write_all(text, strlen(text));
}

static void transport_write_value_line(const char *label, const char *value) {
  transport_write_literal(label);
  while (*value != '\0') {
    char output = (*value == '\r' || *value == '\n') ? ' ' : *value;
    transport_write_all(&output, 1);
    value++;
  }
  transport_write_literal("\n");
}

static void handle_voice_event(const cJSON *message, const char *event);
static void announce_state(void);

static uint32_t clock_ms(void) {
  return xTaskGetTickCount() * (uint32_t)portTICK_PERIOD_MS;
}

static void write_shot_line(const char *line) {
  transport_write_literal(line);
  transport_write_literal("\n");
}

static const char *mode_name(agent_mode_t mode) {
  switch (mode) {
    case AGENT_MODE_POMODORO:
      return "POMODORO";
    case AGENT_MODE_LEISURE:
      return "LEISURE";
    default:
      return "DUTY";
  }
}

static void set_mode(agent_mode_t mode) {
  if (agent_display_mode() == mode) {
    return;
  }
  agent_display_set_mode(mode);
  transport_write_value_line("MODE ", mode_name(mode));
}

static void set_link_lost(bool lost) {
  link_lost = lost;
  agent_display_set_link_lost(lost);
}

static void report_pomodoro(const char *what) {
  transport_write_value_line("POMODORO ", what);
}

/// 静音：长按 K2 翻转，不持久化。开会静了音忘记开回来，设备就哑好几天；
/// 重启恢复有声比记住更安全，屏幕上的 MUTE 标记负责提醒。
static bool muted;

/// 所有语音都从这里出去，静音时只记一行日志。
static void play_prompt(agent_audio_prompt_t prompt, const char *label) {
  if (muted) {
    transport_write_value_line("AUDIO MUTED ", label);
    return;
  }
  if (agent_audio_play(prompt) != ESP_OK) {
    transport_write_literal("AUDIO ERROR\n");
  } else {
    transport_write_value_line("AUDIO QUEUED ", label);
  }
}

/// 音量是设备自己的事实，App 的滑块只是遥控：改完报一行，hello 也报。
static void announce_volume(void) {
  char text[24];
  snprintf(text, sizeof(text), "VOLUME %u\n", agent_audio_volume() % 1000u);
  transport_write_literal(text);
}

/// 当日记录变了就存一次，并报一行给 Mac 端。一天只有几次，NVS 不在乎。
static void save_tally(void) {
  agent_pomodoro_tally_t tally;
  agent_pomodoro_tally(&tally);
  char text[48];
  snprintf(text, sizeof(text), "POMODORO TODAY %u %uS DAY %u\n",
           tally.completed % 10000u, (unsigned)(tally.focus_s % 1000000u),
           (unsigned)(tally.day % 100000000u));
  transport_write_literal(text);
  if (agent_tally_save(&tally) != ESP_OK) {
    transport_write_literal("TALLY SAVE ERROR\n");
  }
}

/// 把番茄钟推到前面来；已经在前面就只重绘。
static void show_pomodoro(void) {
  if (agent_display_mode() == AGENT_MODE_POMODORO) {
    agent_display_refresh();
  } else {
    set_mode(AGENT_MODE_POMODORO);
  }
}

/// 三个键各管一件事，与模式无关：K0 是番茄钟的键，K1 在值班与番茄钟之间
/// 切换（长按去休闲），K2 交给 Mac 端去打开来源。休闲模式里任何键先把
/// 小灯灵叫回值班，再执行本职：休闲没有遮住任何需要先看一眼的东西。
static void on_button(agent_button_event_t event) {
  uint32_t now = clock_ms();
  agent_mode_t mode_before = agent_display_mode();
  agent_leisure_note_activity(now);
  if (mode_before == AGENT_MODE_LEISURE) {
    (void)agent_leisure_tick(now);
    set_mode(AGENT_MODE_DUTY);
  }

  if (event == AGENT_BUTTON_K2_SHORT) {
    transport_write_literal(
        "{\"version\":1,\"event\":\"button\",\"button\":\"K2\",\"action\":\"press\"}\n");
    return;
  }
  if (event == AGENT_BUTTON_K2_LONG) {
    muted = !muted;
    agent_display_set_muted(muted);
    transport_write_literal(muted ? "MUTE ON\n" : "MUTE OFF\n");
    return;
  }
  if (event == AGENT_BUTTON_K1_SHORT) {
    set_mode(mode_before == AGENT_MODE_POMODORO ? AGENT_MODE_DUTY
                                                : AGENT_MODE_POMODORO);
    return;
  }
  if (event == AGENT_BUTTON_K1_LONG) {
    agent_leisure_force_bored(now);
    (void)agent_leisure_tick(now);
    set_mode(AGENT_MODE_LEISURE);
    return;
  }

  agent_pomodoro_view_t before;
  agent_pomodoro_view(now, &before);
  bool break_phase = before.phase == AGENT_POMODORO_BREAK;
  if (event == AGENT_BUTTON_K0_LONG) {
    if (agent_pomodoro_is_idle(&before)) {
      return;
    }
    agent_pomodoro_stop();
    report_pomodoro(break_phase && before.run == AGENT_POMODORO_PENDING
                        ? "BREAK SKIPPED"
                        : "STOPPED");
    agent_display_refresh();
    return;
  }
  agent_pomodoro_toggle(now);
  if (before.run == AGENT_POMODORO_PENDING) {
    report_pomodoro(break_phase ? "BREAK START" : "FOCUS START");
    // 开始一个阶段时把番茄钟推到前面：圆环开始走就是反馈。
    show_pomodoro();
    return;
  }
  // 暂停与继续不换场景，小灯灵场景右上角的徽章会跟着闪。
  report_pomodoro(before.run == AGENT_POMODORO_PAUSED ? "RESUMED" : "PAUSED");
  agent_display_refresh();
}

/// 阶段结束是只消费一次的边沿：播一次语音，并把番茄钟推到前面来——
/// 这正是用户该看一眼的时刻。下一阶段停在待开始，等用户按 K0。
static void handle_pomodoro_transition(agent_pomodoro_transition_t transition) {
  if (transition == AGENT_POMODORO_NOTHING) {
    return;
  }
  bool focus_ended = transition == AGENT_POMODORO_FOCUS_ENDED;
  report_pomodoro(focus_ended ? "FOCUS END" : "BREAK END");
  if (focus_ended) {
    save_tally();
  }
  play_prompt(focus_ended ? AGENT_AUDIO_FOCUS_DONE : AGENT_AUDIO_BREAK_DONE,
              focus_ended ? "FOCUS_DONE" : "BREAK_DONE");
  agent_display_pomodoro_ended();
  show_pomodoro();
}
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

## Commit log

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2026-09-13 fix(tools): capture required serial device lists
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2026-09-14 fix: preserve per-turn completion announcements
    [agent_audio.c, agent_beacon_fw.c]
2026-09-14 fix: distinguish reply requests from completed turns
    [agent_beacon_fw.c]
2026-09-14 fix: expire abandoned Codex activities
    Codex does not emit SessionEnd when its process is killed, so an
    activity could hold a task card and pin the pet to input_required
    forever. Only restarting beacond cleared it.
    Track updated_at per activity and sweep on a 60s background tick.
    Working expires after 30 minutes, input_required after 4 hours: a
    silent working turn usually means the process is gone, while a silent
    waiting turn only means the user has not come back yet.
    The sweep must be a timer, not lazy cleanup on the next hook — once the
    last session dies no further hooks arrive to trigger it.
    Expiry reuses agent.idle with a TIMED OUT title, so the firmware needs
    no change and no refla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
    [main.rs]
2026-09-14 refactor: extract agent-neutral ActivityTracker
    Card ordering, global priority, deduplication, one-shot announcements
    and expiry are not Codex concepts. Move them into activity.rs so the
    second adapter inherits them instead of copying them, and leave
    codex_hooks.rs as a thin translation from hook names to activity calls.
    Behaviour is unchanged: the nine Codex behaviour tests pass untouched.
    Two deliberate exceptions, neither observable on the device:
    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
2026-09-14 feat: add Claude Code adapter
    Claude Code events now drive the Beaconling alongside Codex. Three
    things this required beyond a second translation table:
    - One shared ActivityTracker, not one per adapter. The device has a
    single screen and a single pet, so two aggregators would each keep
    their own card stack and overwrite one another. Adapters are now
    stateless translators.
    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
2026-09-14 fix: stop reporting idle while other activities are still working
    Live on the device, ending one session blanked the screen to ALL QUIET
    while another agent was still working.
    visible_activity returns None for two different reasons: there are no
    activities, or the snapshot is unchanged and was deduplicated. The
    or_else(idle) pattern treated both as the first, so a session ending
    while another agent held an unchanged visible state erased a task that
    was still running.
    The bug predates the shared tracker; it was in the Codex SessionEnd and
    Interrupt paths from the start. Coexistence just made it easy to hit,
    since two agents keep far more sessions alive at once.
    Found by running the adapter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
2026-09-14 fix: make card titles readable on the device
    Two defects found by looking at the actual screen.
    The separator was U+00B7, two bytes in UTF-8, and the firmware renders
    one glyph per byte, so every card showed two unknown symbols after the
    agent prefix. The font covers A-Z, 0-9 and a few ASCII symbols, so the
    prefix is now CX: and CC:.
    The title came from the working directory, which showed TOOLS when the
    agent was working in repo/tools, and the branch directory name inside a
    git worktree. It now resolves the git project root, reading the .git
    file a worktree points back with.
2026-09-14 fix: make announcements audible and pin the target chip
    The prompts were quiet for two reasons, and the smaller one was the
    volume setting. The synthesised assets peaked at 41-48% of full scale,
    throwing away more than 6 dB, so they are normalised to ~90% with a
    single shared gain, which keeps their relative loudness. The codec
    volume goes from 45 to 65 on top of that. No clipping.
    Flashing this from a fresh worktree failed first: sdkconfig.defaults
    never declared CONFIG_IDF_TARGET, and sdkconfig is gitignored, so the
    target chip only existed in one machine's untracked file and any fresh
    checkout built for plain esp32. Declaring it in the defaults puts that
    fact back under version control;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
    [agent_audio.c]
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2026-09-14 feat: show a lost link instead of a stale state
    Until now a dead daemon or an unplugged cable left the device showing
    whatever arrived last. The screen kept saying WORKING, the Beaconling
    kept bobbing, and nothing was actually running. A status device that
    cannot say "I don't know" has to choose between knowing and pretending,
    and it was pretending.
    beacond now sends a heartbeat every 5 seconds. The firmware treats any
    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
2026-09-14 feat: put time on the cards and today on the idle screen
    任务卡现在显示活动在当前状态里待了多久；空闲屏轮播当日战绩，并让小灯灵
    偶尔做个小动作。
    计时从状态变化起算，不是从上一个事件起算：工作中的卡片回答「这个 turn 跑
    了多久」，等待确认的卡片回答「等了多久」，而工具事件每几秒就来一次。设备
    收到后自行继续计时，因为可见状态不变时 daemon 会去重、不再发消息。
    也正因为要去重，计时与战绩都在去重之后才盖到事件上。放进状态快照会让每个
    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
2026-09-14 feat: report GitHub Actions on the same task cards
    CI 出结果的时候用户通常早就切走了，而这个盒子一直在视野边缘。GitHub
    Actions 不走 Hook，由 beacond 每 30 秒用 gh run list 主动轮询，然后写进
    和 Agent 同一个聚合器：一块屏幕、一只小灯灵，来源不同不该各有一套。
    只报告亲眼见过在跑的 run。某次 run 已经结束、而 daemon 从没见过它处于
    运行中，就什么都不做——否则每次重启都会把每个仓库最近一次历史结果重新
    宣告一遍，包括昨天那次失败。代价是两次轮询之间开始并结束的 run 不播报。
    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
2026-09-14 docs: record that acceptance must use the deployed binary
    心跳做完并「实机验收通过」之后，设备仍在无事发生的间隙反复跳 NO LINK：
    验收跑的是 worktree 里的 beacond，LaunchAgent 加载的是主仓库那一个，
    后者从头到尾没重新编译过，进程里 device.heartbeat 出现 0 次。
    固件端的 15 秒超时上线了，发心跳的那一半没有，功能被做反成了持续的假警报。
    代码本身是对的，所以任何测试都不会发现它。
2026-09-14 fix: give the daemon a PATH that contains gh
    launchd 启动的进程只有 /usr/bin:/bin:/usr/sbin:/sbin，gh 不在里面，
    CI 轮询会在每个仓库上报「无法执行 gh」。
2026-09-14 Revert "fix: give the daemon a PATH that contains gh"
    daemon 现在自己去找 gh，不再依赖 launchd 的 PATH。往模板里塞一份
    机器专属的 PATH 只会让下一个读到它的人以为这是必需的安装步骤。
2026-09-14 feat: work out which repositories to watch
    原来要用户在 ~/.config/agentbeacon/ci-repos 里列一份仓库清单。这是多余的：
    每个 Hook 都带 cwd，适配器为了生成任务卡标题本来就把它解析成了 git 项目根，
    CI 复用同一个事实，再从 .git/config 的 origin 远端读出 owner/repo 即可。
    关注的就是 Agent 最近一小时工作过的 GitHub 仓库——这个窗口对应的是「我正在
    这个仓库上干活，所以我关心它的 CI」。推导只读本地文件，不调用 git 也不联网；
    没有项目在跟踪时一次请求都不发。
    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
2026-09-14 feat: show which build is running on both sides
    页脚显示固件与 Mac 端的构建标识：git describe 加编译时刻。
    不用语义版本号。今天那个 NO LINK 就是两边版本不一致，而它们都写着
    0.1.0——看不出任何问题。能揭穿这件事的是构建身份，不是版本号。
    比对交给设备做：一致时只占一行，不一致时分两行并转失败色。让人去读两串
    哈希再自己对比不可靠，而不一致本身正是要被看见的信号。还没收到心跳时不算
    不一致，那只是还不知道。
    Mac 端的时间戳取可执行文件的 mtime，不用编译期常量：build.rs 只在它声明的
    依赖变化时才重跑，改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
    [agent_beacon_fw.c, agent_display.c, main.rs]
2026-09-14 fix: stop treating a build mismatch as an alarm
    上一版让设备比对两侧的 git 描述，不一致就转失败色。这是错的。
    固件要插 USB、停 daemon 才能烧，daemon 改一行源码就重编重启——两边大部分
    时间本来就不在同一个 commit 上。按那个设计页脚会几乎永远是红的，几天之内
    就会被彻底无视。
    而且 commit 相等根本不是要关心的那个不变量。今天坏掉的是协议能力不匹配：
    固件多了「15 秒没消息就算失联」这个要求，Mac 端还没有满足它的那一半。纯
    显示改动的固件比 daemon 新完全没问题，两边 commit 不同却协议兼容也完全
    没问题。
    信息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
    [agent_display.c]
2026-09-14 fix: notice when HEAD moves without HEAD changing
    build.rs 只盯了 .git/HEAD，而 fast-forward 只改 refs/heads/<branch>——
    HEAD 的内容一个字节都没变，构建脚本因此不会重跑，二进制里会留下一个过时
    的 SHA。一个会骗人的版本标签比没有标签更糟。
    改成连当前分支的 ref 和 packed-refs 一起盯；worktree 的 ref 存在主仓库里，
    位置由 commondir 指出。
2026-09-14 docs: extend the stale binary lesson to build metadata
    同一天同一类问题的第二次：这回过时的不是二进制，是刻在二进制里的 SHA。
2026-09-14 fix: detect box uart bridge
    [serial_transport.rs]
2026-09-14 fix: support box uart transport
    [agent_beacon_fw.c]
2026-09-14 fix: keep K2 source after activity ends
    [main.rs]
2026-09-15 fix: stop the usb write from freezing the device
    Every diagnostic line goes to both UART0 and USB Serial/JTAG. With only
    the BOX UART bridge attached, nothing drains the USB tx ring buffer, so
    portMAX_DELAY blocked the main task forever once ~1 KiB had accumulated.
    The screen froze on its last frame, button and link-loss handling stopped
    with it, and the Mac kept writing heartbeats into a port nobody read.
    [agent_beacon_fw.c]
2026-09-15 fix: keep the codex hook runnable on the stock python
    Codex invokes the hook as /usr/bin/python3, which on macOS is 3.9. The
    K2 work added `str | None` to a signature, and PEP 604 unions are
    evaluated at def time there, so every Codex event since has died with a
    TypeError before reaching the daemon — silently, because the hook is
    wired to never disturb Codex.
    Defer annotation evaluation instead of matching the interpreter version.
2026-09-15 feat: log the link K2 actually opened
    "K2 已打开当前活动来源" says the call succeeded, not where it went. When
    the jump lands on the wrong session the log has to name the target.
    [main.rs]
2026-09-15 fix: send K2 to the task that just announced
    Finishing a task removes it from the stack, so K2 recomputed the focus
    on press and could only land on something still running. With two agents
    working in parallel the sequence is: alpha finishes, the device says
    "done", the user presses K2, and it opens beta. The one thing the user
    just heard about is the one thing that could never be selected.
    Keep the source of a task that announced its end, and prefer it for a
    short window. A task waiting for a reply still outranks it — that one is
    blocking someone.
2026-09-15 fix: let the next announcement, not a timer, move the K2 target
    A 30s window assumed the user was sitting at the desk. This device earns
    its keep when they are not: walk away for a coffee, come back, press K2,
    and the target had already drifted back to whatever was still running.
    Hold the target until the next announcement replaces it.
2026-09-15 fix: name the task that actually finished in the end announcement
    The announcement rode on activity_snapshot(), which describes whichever
    activity still holds the screen. Running two agents in parallel, alpha
    finishing rendered as "task.start / CX:BETA / done" — an event named
    start, titled after a task that did not finish, announcing completion.
    K2 went to alpha correctly and looked wrong, because the screen had
    named beta.
    Single tasks were fine only because the empty-stack branch titled the
    event after the finisher, so the two paths disagreed.
    Build the announcement around the task that ended. A task waiting for a
    reply still keeps the screen — it needs the user to act, while "done"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
2026-09-15 feat: add a pomodoro scene on the box keys
    The box gets a second scene: a 25/5 pomodoro with a Focus To-Do style
    dial — sixty ticks, the elapsed arc in the phase colour, a hand at the
    current position, the countdown in the middle. K0 starts, pauses and
    resumes (hold to abandon), K1 switches scenes, K2 keeps opening the
    source. Each key means one thing regardless of scene, so a confirmation
    request mid-focus is still one press away.
    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
    [partitions.csv]
2026-09-15 tools: script the flash over the box uart bridge
    The working parameters — no stub, 256-byte write blocks, partition
    table first as a probe — lived only in a LESSONS paragraph, so every
    flash meant reassembling the command. Now they are a script, and the
    lesson about build metadata records the firmware half of the problem
    it had only fixed on the daemon side.
2026-09-15 feat: carry the local hour in the heartbeat
    The box has no clock and should not join Wi-Fi to get one. The
    beaconling only needs to know night from day, so the heartbeat that
    already repeats the build identity now repeats the Mac's local hour.
    Old daemons that omit it read as daytime on the device.
2026-09-15 feat: let the beaconling play when nothing is happening
    Three modes now, each named for what the beaconling is doing for you:
    on duty (watching agents), pomodoro (timing you), leisure (nothing to
    do, so it plays). "Scene" is gone from the vocabulary; leisure owns the
    whole screen like the other two, so one word covers all three.
    Leisure is driven by boredom, not a switch. Idle counts by state, not
    by message silence — a twenty-minute task sends nothing and is still
    work — so it only accrues while the agent side is idle, no pomodoro is
    running, the link is up and no key was pressed. Five minutes: bored,
    a short skit every 20–40 s (patrol, kick a ball, read, count stars,
    hide and seek,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
    [agent_beacon_fw.c, agent_buttons.c, agent_display.c]
2026-09-15 feat: keep a daily tally of completed pomodoros on the box
    The pomodoro panel now says TODAY, one mark per completed focus and a
    line like "3 FOCUS 1H15"; the idle screen's stat rotation carries the
    same line. Only completed focuses count — abandoning one records
    nothing, pausing does not subtract.
    The tally stays on the box rather than round-tripping through beacond:
    the number on the panel has to change the moment a focus ends, and a
    detour through the Mac only adds delay and a second source of truth.
    It lives in NVS so a reboot keeps it, and it resets when the heartbeat
    brings a new local date — the heartbeat now carries YYYYMMDD next to
    the hour. If the Mac is off across midnight, t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
    [agent_beacon_fw.c, agent_display.c]
2026-09-15 docs: rename the product to Vibe Buddy and the character to 氛围小助手
    Display names only. The repository, beacond, beacon, Beacon Protocol,
    the LaunchAgent label and the on-disk paths keep their old names; the
    screen header, README and docs say Vibe Buddy, and the pixel character
    formerly called 小灯灵 is now 氛围小助手 (Vibe Buddy in English too).
    Code identifiers such as draw_beaconling stay as they are.
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2026-09-15 fix: do not leave a dangling hyphen when a card title is cut
2026-09-15 fix: let a pending pomodoro get bored after five minutes, not thirty
    A pomodoro left at 25:00 is a static screen, as idle as duty. Only a
    paused one is a deliberate stop worth waiting half an hour for. dragon
    sat in front of a pending pomodoro and the beaconling never came out
    to play; agent activity kept resetting the thirty-minute clock too.
    [agent_beacon_fw.c]
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2026-09-16 fix: keep Codex background sessions off the cards and away from K2
    Codex fires the same hooks for its own background runs — the ambient
    suggestions pass after every turn is one — and those sessions have no
    working directory and no row in the threads table. One of them ended
    six seconds after a real turn, so the box announced "done" twice, and
    K2, which follows the most recent announcement, opened
    codex://threads/<id> for a thread that does not exist: a blank window.
    Ignore Codex hooks that have neither a usable cwd nor a known thread.
    Both conditions are required: a freshly started real session may not
    be in the table yet, but it always has a cwd. K2 now walks its
    candidates in priority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
    [main.rs]
2026-09-16 feat: hold K2 to mute
    A long press on K2 toggles a global mute: agent announcements and the
    pomodoro bells are logged as AUDIO MUTED instead of played, and MUTE
    sits in the top-left corner until the next long press. Deliberately
    not persisted — a mute forgotten after a meeting would leave the box
    silent for days, and a reboot restoring sound is the safer failure.
    [agent_beacon_fw.c, agent_buttons.c, agent_display.c]
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2026-09-16 chore: configure issue tracker, triage labels and domain docs for agent skills
    AGENTS.md 作为两个 Agent 共用的说明，CLAUDE.md 只引用它；docs/agents/ 记录
    GitHub issue tracker、五个 triage 标签与单一上下文的领域文档布局。
2026-09-16 feat(firmware): voice packs in their own partition, written over the serial link
    分区表新增 2 MB 的 voices 数据分区；固件启动时映射并校验语音包，空或坏就
    回落内置的湾湾小何。voice.begin/chunk/end 走现有串口协议写入：每块带 CRC
    当场核对，包头留到最后回读校验通过才落盘。device.identify 让背光快闪一秒，
    device.echo 回显收到的字符串用于链路自检。语音包格式是纯 C，主机测试覆盖
    解析与拒绝；打包脚本另有 Python 测试。页脚第二行标签改为 APP。
    主任务栈加到 8 KB：串口中断放进 IRAM 后在音频初始化的深栈上触发会溢出。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
    [partitions.csv]
2026-09-16 fix(daemon): pace writes to the BOX UART bridge at wire speed
    CH343 桥吞不下一整行：主机一次推超过一两百字节，桥的缓冲被冲掉，每 384
    字节丢 32 字节再把后面 32 字节重复一遍，长度不变、内容错位；设备累计报过
    三百多次 invalid_json。设备侧用直接轮询 FIFO 的对照实验证明无辜。桥接时按
    线速分段写，每 128 字节等它在线上走完再写下一段；原生 USB 口不受影响。
    设备到 Mac 的通道改为带诊断行与连断状态的 DeviceMessage，串口可让出给烧录。
    [main.rs, serial_transport.rs]
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2026-09-16 fix(app): semantic version in the heartbeat; daemon follows the App to exit
    App 版本用 git 描述时和 daemon 的构建号重复成「7fb5310-dirty 7fb5310-dirty …」，
    改取 Cargo 工作区的语义版本，构建号只在界面上显示。App 收到 SIGTERM 走正常
    退出把 daemon 停掉；daemon 另看着 BEACON_PARENT_PID，App 被强杀后两秒内自己
    退出，不再变成孤儿占着串口和 7331 端口。
    [main.rs]
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2026-10-08 wip: breadboard board (GoouuuTech S3-N16R8, ST7789 SPI, MAX98357A), from 2026-09-17
    Uncommitted work from a Codex worktree, saved so it survives worktree cleanup.
    Local backup only: holds unreleased PCB files and vendor datasheets, not for the public repo.
    firmware/prebuilt-breadboard is the exact image the devkit ran (685118c-dirty 2026-09-17 15:56).
    [audio-playback.kicad_sch, audio-power.kicad_sch, audio.kicad_sch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]
